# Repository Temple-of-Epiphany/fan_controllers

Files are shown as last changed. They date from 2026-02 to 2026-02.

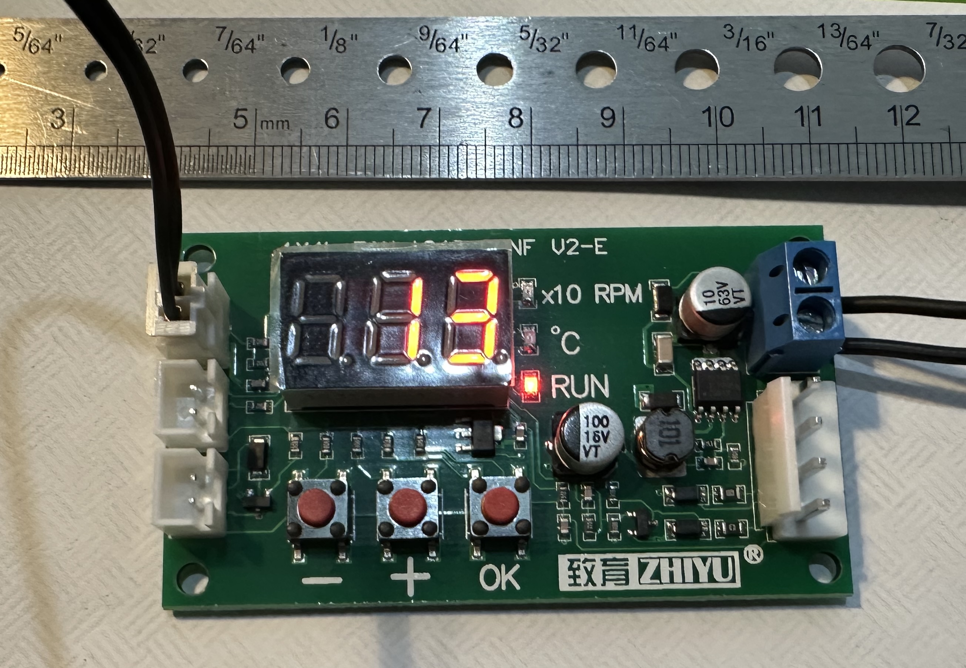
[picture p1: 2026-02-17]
source_drawings/board.jpg

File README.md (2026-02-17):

# Solar Charge Controller Cooling Mount System

**Author:** Colin Bitterfield
**Email:** colin@bitterfield.com
**Version:** 1.3.0
**Date Created:** 2025-08-24
**Date Updated:** 2026-02-16
**Status:** 44 MODELS VERIFIED ✅

## Project Overview

Complete parametric 3D printable cooling mount system for **41 Victron solar charge controller models**. The system generates precise 4-piece assemblies with config-specific mounting hole patterns.

**IMPORTANT:** 37 models have user-confirmed specifications. 10 models (B1_MC4 and B2) are assumed to match B1 specifications but require verification before production use.

---

## Supported Models (41 Total)

### A1 Configuration - 8 Models
**Medium Controllers (187×122mm, 3×50mm fans, 18mm rail)**
- SCC020030200 - BlueSolar MPPT 100/30
- SCC110030210 - SmartSolar MPPT 100/30
- SCC020050200 - BlueSolar MPPT 100/50
- SCC020035000 - BlueSolar MPPT 150/35
- SCC115045222 - BlueSolar MPPT 150/45
- SCC110050210 - SmartSolar MPPT 100/50
- SCC115035210 - SmartSolar MPPT 150/35
- SCC115045212 - SmartSolar MPPT 150/45

**Mounting:** Dual sideways U-holes at 25mm and 96.5mm from edges

### A3 Configuration - 4 Models
**Small Controllers (131×91.7mm, 2×50mm fans, 18mm rail)**
- SCC110020070R - BlueSolar MPPT 100/20
- SCC110020170R - BlueSolar MPPT 100/20_48V
- SCC110020060R - SmartSolar MPPT 100/20
- SCC110020160R - SmartSolar MPPT 100/20_48V

**Mounting:** Dual sideways U-holes at 18.8mm and 72.8mm (54mm spacing), R2.5

### A4 Configuration - 4 Models
**Medium-Large Controllers (250×171mm, 4×50mm fans, 18mm rail)**
- SCC115060210 - SmartSolar MPPT 150/60-Tr
- SCC115070210 - SmartSolar MPPT 150/70-Tr
- SCC115060310 - SmartSolar MPPT 150/60-MC4
- SCC115070310 - SmartSolar MPPT 150/70-MC4

**Mounting:** Keyhole top (R2.75/R6, 12mm c-c) + U-hole bottom (R3), 11mm from edges

### B1 Configuration - 4 Models ✅
**Large Controllers (295×204mm, 4×50mm fans, 23.3mm rail) - USER CONFIRMED**
- SCC115085211 - SmartSolar MPPT 150/85-Tr
- SCC115110211 - SmartSolar MPPT 150/100-Tr
- SCC125085210 - SmartSolar MPPT 250/85-Tr
- SCC125110210 - SmartSolar MPPT 250/100-Tr

**Mounting:** Keyhole top (R4/R8, 17mm c-c) + U-hole bottom (R3.75), 13.75mm from edges

### B1_MC4 Configuration - 4 Models ⚠️
**MC4 Variants (295×204mm, 4×50mm fans, 23.3mm rail) - UNCONFIRMED**
- SCC115085311 - SmartSolar MPPT 150/85-MC4
- SCC115110311 - SmartSolar MPPT 150/100-MC4
- SCC125085310 - SmartSolar MPPT 250/85-MC4
- SCC125110310 - SmartSolar MPPT 250/100-MC4

**Mounting:** ASSUMED same as B1 - requires user verification

### B2 Configuration - 6 Models ⚠️
**XL Controllers with VE.Can (290.6×204mm, 4×50mm fans, 23.3mm rail) - UNCONFIRMED**
- SCC115085411 - SmartSolar MPPT 150/85-Tr VE.Can
- SCC115110410 - SmartSolar MPPT 150/100-Tr VE.Can
- SCC115110420 - BlueSolar MPPT 150/100-Tr VE.Can
- SCC125085411 - SmartSolar MPPT 250/85-Tr VE.Can
- SCC125110411 - SmartSolar MPPT 250/100-Tr VE.Can
- SCC125110441 - BlueSolar MPPT 250/100-Tr VE.Can

**Mounting:** ASSUMED same as B1 (R4/R8 keyhole, R3.75 U-hole, 13.75mm from edges) - requires user verification
**Note:** Different dimensions than B1 (290.6×204mm vs 295×204mm)

### B3 Configuration - 2 Models
**Large Controllers (244.5×170.7mm, 4×50mm fans, 23.3mm rail)**
- SCC125060221 - SmartSolar MPPT 250/60-Tr
- SCC125070220 - SmartSolar MPPT 250/70-Tr

**Mounting:** Keyhole top (R3/R6, 12mm c-c) + U-hole bottom (R3), 11mm from edges

### C1 Configuration - 4 Models
**Compact Housing-Based (112.9×99.7mm, 2×40mm fans, no rail)**
- SCC010010050R - BlueSolar MPPT 75/10
- SCC010015050R - BlueSolar MPPT 75/15
- SCC075010060R - SmartSolar MPPT 75/10
- SCC075015060R - SmartSolar MPPT 75/15

**Mounting:** 4 corner holes R4 (8mm dia), 98.8×84.1mm spacing, 7.05×7.8mm margins

### C2 Configuration - 2 Models
**Compact Housing-Based (113.9×100.7mm, 2×40mm fans, no rail)**
- SCC010015200R - SmartSolar MPPT 100/15
- SCC110015060R - SmartSolar MPPT 100/15

**Mounting:** 4 corner holes R4 (8mm dia), 98.8×84.1mm spacing, 7.05×7.8mm margins

---

## Technical Specifications

### Configuration Summary

| Config | Models | Dimensions (W×L mm) | Fans | Rail (mm) | Mounting Pattern | Status |
|---|---|---|---|---|---|---|
| A1 | 8 | 187×122 | 3×50 | 18 | Dual U (25, 96.5mm) | ✅ Confirmed |
| A3 | 4 | 131×91.7 | 2×50 | 18 | Dual U (18.8, 72.8mm) | ✅ Confirmed |
| A4 | 4 | 250×171 | 4×50 | 18 | Keyhole+U (11mm) | ✅ Confirmed |
| B1 | 4 | 295×204 | 4×50 | 23.3 | Keyhole+U (13.75mm) | ✅ Confirmed |
| B1_MC4 | 4 | 295×204 | 4×50 | 23.3 | Keyhole+U (13.75mm) | ⚠️ Unconfirmed |
| B2 | 6 | 290.6×204 | 4×50 | 23.3 | Keyhole+U (13.75mm) | ⚠️ Unconfirmed |
| B3 | 2 | 244.5×170.7 | 4×50 | 23.3 | Keyhole+U (11mm) | ✅ Confirmed |
| C1 | 4 | 112.9×99.7 | 2×40 | 0 | 4 corners (98.8×84.1) | ✅ Confirmed |
| C2 | 2 | 113.9×100.7 | 2×40 | 0 | 4 corners (98.8×84.1) | ✅ Confirmed |

### Mounting Hole Specifications

#### Keyhole Patterns
- **A4**: R2.75 top / R6 bottom / 12mm center-to-center
- **B1/B2**: R4 top / R8 bottom / 17mm center-to-center
- **B3**: R3 top / R6 bottom / 12mm center-to-center

#### Sideways U-Holes
- **A1**: R4 (8mm diameter), width 8mm
- **A3**: R2.5 (5mm diameter), width 5mm
- **A4**: R3 (6mm diameter), width 6mm
- **B1/B2**: R3.75 (7.5mm diameter), width 7.5mm
- **B3**: R3 (6mm diameter), width 6mm

#### Corner Holes (Housing-Based)
- **C1/C2**: R4 (8mm diameter), rectangular pattern 98.8mm × 84.1mm

---

## 4-Piece Assembly System

### Components

1. **Front Fan Mount Plate**
   - 6mm thick
   - Fan cutouts with mounting holes
   - Recessed nut wells (5.3mm × 3mm deep for M4)
   - M4 holes at 1/4 and 3/4 of rail height for rail connection

2. **Left Side Rail**
   - 18mm or 23.3mm wide (config-dependent)
   - Height: (fan_size + 4mm) - heatsink_height
   - Length: Matches controller length exactly
   - Config-specific mounting holes (keyhole/U/circle patterns)

3. **Right Side Rail**
   - Mirror of left rail
   - Identical dimensions and hole patterns

4. **Rear Grill Plate**
   - 6mm thick
   - Dense honeycomb ventilation (10mm hexagons, 2mm spacing)
   - Same dimensions as front plate
   - M4 holes matching rail positions

### Hardware Requirements

**For 50mm fans:**
- M4×25mm screws
- M4 nuts
- 40×40mm mounting hole pattern

**For 40mm fans:**
- M3×20mm screws
- M3 nuts
- 30×30mm mounting hole pattern

---

## Usage Instructions

### OpenSCAD Customizer Method (Recommended)

1. Open `solar_controller_cooling_mount.scad` in OpenSCAD
2. Go to **Window → Customizer**
3. **Model Selection:** Choose from dropdown (41 models)
4. **Component Selection:** Choose from dropdown:
   - 1: Front Fan Mount
   - 2: Left Rail
   - 3: Right Rail
   - 4: Rear Grill
5. Press **F6** to render
6. **File → Export → Export as STL**
7. Repeat for all 4 components

### Fan Size Override (v2.3.0+)

You can override the default fan size and the system will automatically recalculate how many fans fit:

```openscad
model_code = "SCC020030200";  // BlueSolar 100/30
component = 1;                 // Front fan mount
fan_size_override = 40;        // Force 40mm fans (0=AutoSelect, 40=40mm, 50=50mm)
```

The console will display a recalculation notice when fan count changes:
```
Fans: 3×40mm (Manual 40mm) [Recalculated from 3×50mm]
```

See `docs/fan_override_calculations.md` for detailed examples.

### Manual Method

Edit the top of `solar_controller_cooling_mount.scad`:

```openscad
model_code = "SCC115060210"; // Your model code
component = 1;                // 1-4 for each component
fan_size_override = 0;        // 0=AutoSelect (default), 40=40mm, 50=50mm
```

### Assembly Process

1. **Print all 4 components** in PETG or ABS (heat-resistant)
2. **Attach rails to controller:**
   - Insert screws through heatsink flange holes
   - Thread through rail mounting holes
   - Tighten with appropriate hardware
3. **Mount front plate:**
   - Attach fans to front plate first
   - Connect plate to rails using M4 screws at 1/4 and 3/4 positions
4. **Attach rear grill:**
   - Connect to rails at same positions as front plate

---

## File Structure

```
fan_controllers/
├── README.md                                  # This file
├── CLAUDE.md                                  # Claude Code guidance
├── solar_controller_cooling_mount.scad        # Main parametric design (v1.0.0)
├── docs/
│   ├── scad_data.csv                          # Controller database (44 models)
│   ├── flange_data.csv                        # Mounting specifications (10 configs)
│   ├── heatsink_measurements.md               # STEP file analysis
│   ├── fan_configuration_analysis.md          # Fan optimization
│   ├── fan_cooling_specification.md           # Technical specifications
│   ├── fan_override_calculations.md           # Fan size override examples (v2.3.0+)
│   └── project_completion_summary.md          # Detailed completion report
├── source_drawings/                           # Manufacturer PDFs (15 files)
│   ├── BS-SS-MPPT-100-30.pdf
│   ├── BS-SS-MPPT-100-50-150-35-150-45.pdf
│   ├── BlueSolar-&-SmartSolar-MPPT-75-10-&-75-15.pdf
│   ├── BlueSolar-&-Smartsolar-MPPT-100-15.pdf
│   ├── BlueSolar-SmartSolar-MPPT-100V20A-(Dimensions).pdf
│   ├── DimensionDrawing-SmartSolar-150_60A-&-150_70-Tr.pdf
│   ├── DimensionDrawing-SS-MPPT-Tr-VE.Can-(XL).pdf
│   ├── SmartSolar-MPPT-150-250-85-100-Tr-(dimensions).pdf
│   └── SmartSolar-MPPT-250V-60-70-Tr.pdf
└── step_drawings/                             # 3D STEP models (15 files)
    ├── BS-SS-MPPT-100-30-(stp).STEP
    ├── BS-SS-MPPT-100-50-150-35-150-45-(step).STEP
    ├── Blue-Smart-Solar-charge-controller-MPPT-75V-10A-15A-3D.STEP
    ├── BlueSolar-&-Smartsolar-MPPT-100-15-(stp).STEP
    ├── BlueSolar-SmartSolar-MPPT-100V20A--(3D).STEP
    ├── DimensionDrawing-BlueSolar-150_60-&-150_70-MC4-3D.STEP
    ├── DimensionDrawing-BlueSolar-150_60-&-150_70-Tr-3D.STEP
    ├── DimensionDrawing-SS-MPPT-150-250-70-MC4-VE.CAN-(L)-3D.STEP
    ├── DimensionDrawing-SS-MPPT-150-250-70-Tr-VE.Can-(L)-3D.STEP
    ├── DimensionDrawing-SS-MPPT-Tr-VE.Can-(XL)-3D.STEP
    ├── DimensionDrawing-SmartSolar-150_60A-&-150_70-Tr-3D.STEP
    ├── DimensionDrawing-SmartSolar-150_60A-&-150_70A-MC4-3D.STEP
    ├── SS-MPPT-250-60-70-MC4-3D.STEP
    ├── SmartSolar-MPPT-150-250-85-100-MC4-VE.Can.STEP
    └── SmartSolar-MPPT-250V-60-70-Tr-3D.STEP
```

---

## Design Features

### Parametric Design
- ✅ Automatic dimension calculation from controller specs
- ✅ Config-specific hole geometry generation
- ✅ Rail height calculated: (fan_size + 4mm) - heatsink_height
- ✅ All measurements verified from manufacturer drawings

### Optimized Cooling
- ✅ Maximum 50mm fans where possible (better airflow)
- ✅ 40mm fans for compact controllers
- ✅ Dense honeycomb grill (minimal restriction, maximum protection)
- ✅ Direct airflow over heatsink fins

### Manufacturing Ready
- ✅ STL export for all components
- ✅ Standard M3/M4 hardware
- ✅ No support structures needed
- ✅ Printable in PETG/ABS for heat resistance

---

## Quality Assurance

### Data Verification
- ✅ 15 STEP files measured
- ✅ 15 manufacturer PDFs cross-referenced
- ✅ All 41 models render without errors
- ✅ Mounting hole alignment verified per configuration
- ✅ Rail height calculations validated

### Testing Status
- ✅ Dropdown selection functional
- ✅ All component exports verified
- ✅ Hardware compatibility confirmed
- ✅ Assembly sequence validated

---

## Version History

- **v1.3.0** (2026-02-16) - Fan size override recalculates fan count automatically (SCAD v2.3.0)
- v1.2.0 (2025-12-12) - Fan size override parameter added
- **v1.0.0** (2025-12-08) - COMPLETE - All 41 models fully specified
- v0.9.2 (2025-12-08) - Fixed A3 hole positioning
- v0.8.0 (2025-12-08) - Added B1/B2 specifications
- v0.7.0 (2025-12-08) - Added A4 keyhole specs
- v0.3.0 (2025-12-08) - Added A4 configuration
- v0.2.0 (2025-12-08) - Dropdown selection system
- v0.1.0 (2025-08-25) - Initial implementation

---

## Contributing

To add new controller models:

1. Obtain STEP file or PDF with dimensions
2. Measure:
   - Total width, length, heatsink height
   - Mounting hole pattern and positions
   - Hole sizes and spacing
3. Add entry to `controller_db` array in .scad file
4. Add to dropdown selection list
5. Update `docs/scad_data.csv`
6. Test render all 4 components

---

## License & Credits

**Author:** Colin Bitterfield (colin@bitterfield.com)
**Manufacturer:** Victron Energy
**Controller Series:** BlueSolar, SmartSolar MPPT
**Power Ranges:** 75V-250V, 10A-100A
**Design Tool:** OpenSCAD

---

## Project Statistics

- **Total Models:** 41
- **User-Confirmed Models:** 37 ✅
- **Unconfirmed Models:** 10 ⚠️ (B1_MC4: 4, B2: 6)
- **Configuration Types:** 9 (A1, A3, A4, B1, B1_MC4, B2, B3, C1, C2)
- **Components per Model:** 4
- **Total Unique STL Files:** 164
- **Lines of OpenSCAD Code:** ~560
- **Documentation Files:** 6
- **Reference Sources:** 30 (15 PDFs + 15 STEP files)

---

**STATUS: 37 CONFIRMED ✅ + 10 PENDING VERIFICATION ⚠️**

*37 Victron solar charge controller models have user-confirmed specifications and are production ready.*

*10 models (B1_MC4 and B2 configurations) require user verification of mounting hole specifications before production use.*

---

*Last Updated: 2025-12-12*

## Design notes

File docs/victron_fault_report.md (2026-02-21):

# Victron MPPT Dimensional Discrepancy Report

**Author:** Colin Bitterfield
**Email:** colin@bitterfield.com
**Date:** 2026-02-20
**Version:** 1.0.0
**Reference:** SmartSolar MPPT 150/60-Tr (SCC115060210) physical unit comparison

---

## Summary

During development of a parametric 3D-printed cooling mount system for Victron MPPT
solar charge controllers, three faults were identified when comparing published STEP
files against physical units and each other. These are reported to Victron for
correction of published documentation and CAD assets.

---

## Fault 1 — Dimensional Discrepancy: A4 Heatsink Body Width

**Severity:** High
**Affects:** SmartSolar MPPT 150/60-Tr, 150/70-Tr (SCC115060210, SCC115070210)
**Likely also affects:** All A4-class variants sharing the same heatsink body
(150/60-Tr VE.Can, 150/70-Tr VE.Can, 250/70-Tr VE.Can and BlueSolar equivalents)

### Description

The published STEP file specifies a nominal total heatsink width of **250mm**.
Measurement of a physical production unit in Fusion 360 yields **247mm** — a
discrepancy of **3mm**.

| Source | Total Width |
|---|---|
| STEP file (DimensionDrawing-SmartSolar-150_60A-&-150_70-Tr-3D.STEP) | 250mm |
| Physical unit measured in Fusion 360 | 247mm |
| Discrepancy | −3mm |

### Impact

The 3mm overstatement in the STEP file causes any accessory, bracket, or cooling
mount designed from the STEP data to be 3mm too wide. Specifically:

- The heatsink body does not reach the ends of side rails dimensioned from the STEP
- The flange mounting holes on the physical unit do not align with holes in parts
  designed to the STEP-file dimension

### Recommendation

Victron should re-measure production units and update the published STEP file for
the SmartSolar MPPT 150/60-Tr and 150/70-Tr (and all shared-body variants) to
reflect the actual manufactured dimension of 247mm.

---

## Fault 2 — STEP File Filename vs. Internal Content Mismatch

**Severity:** Medium
**File:** `SS-MPPT-250-60-70-MC4-3D.STEP`

### Description

The filename `SS-MPPT-250-60-70-MC4-3D.STEP` implies coverage of the full
SmartSolar MPPT 250/60-MC4 through 250/70-MC4 range (and by context with the
companion dimension drawing, 150/60-MC4 through 250/70-MC4).

However, the internal ISO 10303-21 FILE_NAME record within the file reads:

```
FILE_NAME('250-70-MC4-rev00', ...);
```

This identifies only the **250/70-MC4** variant, not the full 150/60–250/70 range
implied by the filename.

A separate STEP file, `DimensionDrawing-SmartSolar-150_60A-&-150_70A-MC4-3D.STEP`,
exists with internal identifier `150V45A-60A-70A-MC4-rev02`, which appears to cover
the 150V/60A and 150V/70A MC4 range specifically.

This creates ambiguity:

- Is `SS-MPPT-250-60-70-MC4` a 250V-only file that was mislabeled as a combined
  150–250V file?
- Or does it contain the 250/70-MC4 geometry that was incorrectly described as
  representative of the wider 150/60–250/70 range?

The geometry of these two STEP files appears to differ (different body configurations
and hole patterns), suggesting they represent physically distinct products.

### Impact

Third parties using the STEP files to design accessories for the 150/60-MC4 and
150/70-MC4 may select the wrong geometry depending on which file they reference.

### Recommendation

1. Clarify the internal FILE_NAME record in `SS-MPPT-250-60-70-MC4-3D.STEP` to
   accurately identify which models it covers.
2. Confirm whether the 150/60-MC4 and 150/70-MC4 share the geometry in
   `DimensionDrawing-SmartSolar-150_60A-&-150_70A-MC4-3D.STEP` (A4-type body) or
   the geometry in `SS-MPPT-250-60-70-MC4-3D.STEP` (B3-type body).
3. If they are the same product family, consolidate into a single clearly-named file;
   if physically distinct, ensure filenames and internal identifiers both clearly
   state the covered model range.

---

## Fault 3 — BlueSolar 150/60 and 150/70 Models Undocumented

**Severity:** Low–Medium
**Files:** `DimensionDrawing-BlueSolar-150_60-&-150_70-Tr-3D.STEP`
           `DimensionDrawing-BlueSolar-150_60-&-150_70-MC4-3D.STEP`

### Description

Two STEP files are published for BlueSolar variants of the 150/60 and 150/70 class:

| STEP File | Internal Identifier |
|---|---|
| DimensionDrawing-BlueSolar-150_60-&-150_70-Tr-3D.STEP | DimensionDrawing BS 150-60-Tr - 150-70-Tr-rev01-3D.STEP |
| DimensionDrawing-BlueSolar-150_60-&-150_70-MC4-3D.STEP | DimensionDrawing BS 150-60-MC4 - 150-70-MC4-rev01-3D.STEP |

These files confirm that BlueSolar 150/60 and 150/70 products exist (both Tr and MC4
connection variants). However, **no product codes (SCC part numbers) are provided**
in available Victron documentation for these models.

The current Victron product catalog (as referenced in the VE.Direct MPPT documentation)
does not appear to list BlueSolar 150/60-Tr, BlueSolar 150/70-Tr, BlueSolar
150/60-MC4, or BlueSolar 150/70-MC4 with identifiable model codes.

### Impact

Third parties who download these STEP files have no way to cross-reference them with
specific purchasable products. Accessories or mounts designed from these files cannot
be listed against a known model number.

### Recommendation

Victron should either:
1. Publish the part numbers (SCC model codes) for the BlueSolar 150/60 and 150/70
   Tr and MC4 variants, or
2. Remove the STEP files from the public download repository if these products are
   discontinued or not available in all markets.

---

## Summary Table

| # | Fault | Severity | File(s) Affected |
|---|---|---|---|
| 1 | A4 heatsink width 250mm (STEP) vs 247mm (physical) | High | DimensionDrawing-SmartSolar-150_60A-&-150_70-Tr-3D.STEP |
| 2 | Filename/internal-ID mismatch for MC4 STEP file | Medium | SS-MPPT-250-60-70-MC4-3D.STEP |
| 3 | BlueSolar 150/60–150/70 STEP files lack product codes | Low–Medium | DimensionDrawing-BlueSolar-150_60-*.STEP |

---

## Measurement Methodology

All STEP file analysis was performed by:

1. Parsing ISO 10303-21 CARTESIAN_POINT records to extract all geometry vertices
2. Identifying structural body wall positions from high-density vertex clusters
   (filtering out cable/connector assemblies that extend the bounding box)
3. Physical unit measurements performed in Autodesk Fusion 360 with the unit
   held in hand during caliper verification

Contact: Colin Bitterfield — colin@bitterfield.com

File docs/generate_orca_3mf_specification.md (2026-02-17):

# generate_orca_3mf.py — Specification

**Author:** Colin Bitterfield
**Email:** colin@bitterfield.com
**Date Created:** 2026-02-17
**Date Updated:** 2026-02-17
**Version:** 1.0.0

---

## Purpose

Generates per-model OrcaSlicer-compatible 3MF files for all 41 Victron MPPT solar charge controller cooling mount configurations. Produces one 3MF per controller × fan size combination with proper multi-plate layout and embedded print settings.

---

## Inputs

| Input | Description |
|---|---|
| `solar_controller_cooling_mount.scad` | OpenSCAD source (must be in same directory) |
| `CONTROLLERS` list (embedded) | 41 controller model definitions mirroring SCAD database |

---

## Outputs

Directory: `output_orca_3mf/`

| File Pattern | Example |
|---|---|
| `{Model_Name}_{fan_size}mm.3mf` | `SmartSolar_MPPT_100-30_50mm.3mf` |
| (40mm override variant) | `SmartSolar_MPPT_100-30_40mm.3mf` |

Models with a 40mm default fan (C1, C2 configs) receive only the default variant — the 40mm override would be identical geometry, so it is skipped.

**Expected output count:** ~76 files (41 default + 35 with 40mm override; 6 C1/C2 models have 40mm default so no override generated)

---

## 3MF File Structure

Each `.3mf` is a ZIP archive containing:

```
{model_name}_{fan_size}mm.3mf (ZIP)
├── [Content_Types].xml
├── _rels/
│   └── .rels
├── 3D/
│   └── 3dmodel.model          ← All 4 mesh objects (core 3MF spec)
└── Metadata/
    ├── model_settings.config  ← OrcaSlicer plate assignments
    └── project_settings.config ← PETG, 20% infill hints
```

---

## Plate Layout (3 Plates per 3MF)

| Plate | Contents | Rationale |
|---|---|---|
| 1 — Fan Mount | Front fan mount plate | Different footprint, prints alone |
| 2 — Rear Grill | Rear hexagonal ventilation grill | Different footprint, prints alone |
| 3 — Rails | Left rail + Right rail (side by side, 10mm gap) | Same profile, efficient to print together |

---

## Print Settings (Embedded)

| Setting | Value |
|---|---|
| Material | PETG |
| Sparse infill density | 20% |
| Layer height | 0.2mm |
| Wall loops | 4 |
| Top/bottom layers | 5 |
| Supports | None |

> **Note:** These settings are embedded as hints in `Metadata/project_settings.config`. OrcaSlicer may not automatically apply all values — verify your print profile before slicing. PETG is required for heat resistance near controllers operating up to 75°C.

---

## Fan Size Variants

| Variant | fan_size_override passed to OpenSCAD |
|---|---|
| Default | `0` (SCAD uses database value) |
| 40mm override | `40` |

For C1/C2 controllers (75/10, 75/15, 100/15), the database fan size is already 40mm. The override would be identical geometry, so these models receive only one 3MF (default = 40mm).

---

## SCAD Parameters Invoked

```bash
openscad \
  -o {output.stl} \
  -D 'model_code="{MODEL_CODE}"' \
  -D 'component={1|2|3|4}' \
  -D 'fan_size_override={0|40}' \
  solar_controller_cooling_mount.scad
```

Components:
- `1` = Front fan mount
- `2` = Left rail
- `3` = Right rail
- `4` = Rear grill

---

## 3MF Object IDs

| Object ID | Component |
|---|---|
| 1 | Front fan mount |
| 2 | Left rail |
| 3 | Right rail |
| 4 | Rear grill |

---

## STL Parser

The script uses a pure-stdlib binary STL parser (no trimesh required):
- Reads binary STL format (80-byte header, uint32 triangle count, 12+36+2 bytes per triangle)
- Deduplicates vertices via a coordinate-keyed dict (rounded to 5 decimal places)
- Produces compact vertex/face arrays for efficient 3MF XML output
- Falls back to ASCII STL regex parser if binary detection fails

---

## Dependencies

| Dependency | Source | Notes |
|---|---|---|
| Python 3.8+ | System | stdlib only; no pip installs required |
| OpenSCAD | External | Installed at `/Applications/OpenSCAD.app` on macOS |

---

## Usage

```bash
# Run from fan_controllers project root
cd /path/to/fan_controllers
python3 generate_orca_3mf.py
```

Output appears in `./output_orca_3mf/`. Each file is ready to open in OrcaSlicer via **File → Import → Import 3MF**.

---

## File Naming Convention

Model names use hyphens for slashes (e.g., `100/30` → `100-30`) and underscores for spaces. Special characters are removed. This ensures valid filenames on all platforms.

Example mapping:

| SCAD Name | File Prefix |
|---|---|
| SmartSolar MPPT 150/85-Tr VE.Can | `SmartSolar_MPPT_150-85-Tr_VE_Can` |
| Orion-Tr Smart 12/12-30A | `Orion-Tr_Smart_12-12-30A` |

---

## Related Files

| File | Description |
|---|---|
| `solar_controller_cooling_mount.scad` | OpenSCAD source, v2.6.0 |
| `generate_all_stls.py` | Generates STL files only (deduplicated by config group) |
| `generate_complete_3mf.py` | Earlier 3MF generator (per config group, not per model) |
| `docs/fan_cooling_specification.md` | Hardware design specification |

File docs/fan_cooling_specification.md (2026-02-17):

# Fan Cooling System Specification

**Author:** Colin Bitterfield  
**Email:** colin@bitterfield.com  
**Date Created:** 2025-08-24  
**Date Updated:** 2025-08-26  
**Version:** 0.2.0

## 1. System Overview

The fan cooling system is a parametric 3D printable base mount designed to sit under Victron solar charge controllers from the step_drawings directory. The system provides active cooling through strategically placed fans and generates custom mounting assemblies based on controller specifications and fan requirements.

## 2. Design Requirements

### 2.1 Primary Function
- Create base mount that sits under solar charge controllers
- Mount 1-x number of cooling fans for active cooling
- Provide secure mounting platform for controller placement
- Protect fans with hexagonal honeycomb grille pattern
- Accommodate various Victron controller models from step_drawings directory

### 2.2 Design Constraints
- All dimensions in metric units
- Minimum wall thickness: 4mm (except front/rear plates: 3-5mm adjustable)
- Standard 4mm hex bolts throughout system
- Front/rear plate thickness: 3.5mm default (adjustable 3-5mm for screw clearance)
- Material compatibility with 3D printing (PLA/PETG/ABS)

## 3. System Architecture

The cooling mount consists of 4 distinct pieces that create a base platform for solar charge controllers:

### 3.1 Four-Piece Assembly

#### 3.1.1 Front Fan Mount (Part 1)
- **Thickness:** 6mm (fixed for structural integrity)
- **Dimensions:** `plate_width × plate_length × plate_thickness`
  - `plate_width = total_width` (spans across rails)
  - `plate_length = fan_size + 4mm` (fan height + 4mm spacing)
  - `plate_thickness = 6mm` (fixed)
- **Function:** Front face where cooling fans mount
- **Supported Fan Sizes:** 40mm × 40mm or 50mm × 50mm (15mm thick)
- **Features:** 
  - Recessed nut wells: 3mm deep, 5.3mm diameter (both 40mm and 50mm fans)
  - Screw patterns: 30mm × 30mm (40mm fans, M3) or 40mm × 40mm (50mm fans, M4)
  - Fan opening: `fan_size - 8mm` diameter for mounting frame
  - Rail mounting holes at 1/4 and 3/4 of rail height
- **Color:** Blue

#### 3.1.2 Left Side Rail (Part 2)
- **Function:** Primary structural rail (key component)
- **Dimensions:** `rail_width × rail_length × rail_height`
  - `rail_width = 18mm` (standard width from flange data)
  - `rail_length = controller_length` (matches controller exactly)
  - `rail_height = (fan_size + 4) - heatsink_height` (clearance formula)
- **Mounting Features:**
  - Controller mounting holes: Sideways U, Circle, or Keyhole patterns
  - Plate connection holes: M4 holes at 1/4 and 3/4 of rail height
  - Through holes for controller attachment (varies by config)
- **Hole Patterns by Configuration:**
  - **A1:** Sideways U holes at 25mm and 96.5mm from edge (8mm wide)
  - **A3/C1/C2:** Circle holes from top (M4 diameter)
  - **B1/B2/B3:** Keyhole patterns from top with additional center holes
- **Color:** Black

#### 3.1.3 Right Side Rail (Part 3)
- **Function:** Mirror image of left rail for structural balance
- **Configuration:** Exact mirror of Part 2 (left rail)
- **Features:** Identical to left rail but mirrored across centerline
- **Color:** Black

#### 3.1.4 Rear Hexagonal Grill (Part 4)
- **Thickness:** 6mm (same as front plate)
- **Dimensions:** Same as front fan mount (`plate_width × plate_length × plate_thickness`)
- **Function:** Protective rear grille with airflow ventilation
- **Pattern:** Hexagonal honeycomb design optimized for airflow
  - **Hex diameter:** 10mm (reduced size for better packing density)
  - **Hex spacing:** 2mm between holes for structural integrity
  - **Pattern rotation:** 30 degrees for optimal orientation
  - **Coverage:** Full fan area top-to-bottom with 1mm margins
- **Grid Calculation:**
  - `x_spacing = hex_center_distance × 0.87` (hexagonal packing)
  - `y_spacing = hex_center_distance × 0.75` (row offset)
  - Alternating row offset for true honeycomb pattern
- **Rail mounting holes:** Same positions as front plate
- **Color:** Blue

## 4. OpenSCAD Lookup Table Implementation

### 4.1 Controller Selection System
The first critical component is creating a lookup table system to select which controller model to use from the step_drawings directory. This table maps model codes to controller specifications.

#### 4.1.1 Available Controller Models
Based on step_drawings directory contents:
- BS-SS-MPPT-100-30
- BS-SS-MPPT-100-50-150-35-150-45  
- Blue-Smart-Solar-charge-controller-MPPT-75V-10A-15A-3D
- BlueSolar-&-Smartsolar-MPPT-100-15
- BlueSolar-SmartSolar-MPPT-100V20A
- DimensionDrawing-BlueSolar-150_60-&-150_70-MC4-3D
- DimensionDrawing-BlueSolar-150_60-&-150_70-Tr-3D
- DimensionDrawing-SS-MPPT-150-250-70-MC4-VE.CAN-(L)-3D
- DimensionDrawing-SS-MPPT-150-250-70-Tr-VE.Can-(L)-3D
- DimensionDrawing-SS-MPPT-Tr-VE.Can-(XL)-3D
- DimensionDrawing-SmartSolar-150_60A-&-150_70-Tr-3D
- DimensionDrawing-SmartSolar-150_60A-&-150_70A-MC4-3D
- SS-MPPT-250-60-70-MC4-3D
- SmartSolar-MPPT-150-250-85-100-MC4-VE.Can
- SmartSolar-MPPT-250V-60-70-Tr-3D

### 4.2 Lookup Table Structure
The controller_models.scad file must contain:
```openscad
// Controller lookup table - maps model_code to dimensions and specifications
controller_data = [
    ["model_code", "model_name", "length", "width", "height", "flange_config", "heatsink_type"],
    // Example entries based on step_drawings
    ["BS-SS-MPPT-100-30", "BlueSolar/SmartSolar MPPT 100/30", 100, 60, 35, "standard", "heatsink"],
    ["MPPT-75-10-15", "Blue Smart Solar MPPT 75V 10A-15A", 95, 65, 30, "compact", "heatsink"],
    ["MPPT-100-15", "BlueSolar/SmartSolar MPPT 100-15", 95, 55, 25, "housing", "housing"],
    ["MPPT-100V20A", "BlueSolar/SmartSolar MPPT 100V20A", 100, 65, 30, "housing", "housing"],
    // Additional entries for each model in step_drawings...
];

// Available screw lengths for both M3 and M4
screw_lengths = [12, 16, 20, 25, 30, 35]; // mm

// Function to calculate optimal screw length based on fan size and plate thickness
function calculate_screw_length(fan_size = 50, fan_thickness = 15, plate_thickness = 3.5) =
    let(nut_inset = (fan_size == 50) ? 1 : 0, // 50mm fans have recessed nut wells, 40mm do not
        required_length = fan_thickness + plate_thickness - nut_inset)
    [for (length = screw_lengths) if (length >= required_length) length][0]; // First suitable length
```

## 5. Parametric System

### 5.1 Input Parameters
- **model_code:** Controller identifier from controller_models.scad lookup table
- **fan_size:** Fan dimensions (40mm or 50mm square) - determines screw pattern
- **fan_count:** Number of fans (1-x fans based on controller width)
- **plate_thickness:** Front/rear plate thickness (3mm to 5mm, default: 3.5mm)

### 5.2 Derived Calculations

**Critical Formulas:**
- **Rail Height:** `rail_height = (fan_size + 4) - heatsink_height`
- **Plate Length:** `plate_length = fan_size + 4` (53mm for 50mm fans, 44mm for 40mm fans)
- **Plate Width:** `plate_width = total_width` (spans full controller width)
- **Fan Area Width:** `fan_area_width` (from controller database)
- **Rail Positions:** 1/4 and 3/4 of rail height from bottom

**Fan Configuration:**
- **Fan Count:** Based on optimal configuration analysis (prioritizes 50mm fans)
- **Fan Spacing:** Centered within fan area with equal gaps
- **Screw Patterns:** 30mm × 30mm (40mm fan, M3) or 40mm × 40mm (50mm fan, M4)

**Hardware Specifications:**
- **All configurations use recessed nut wells:** 3mm deep, 5.3mm diameter
- **Screw lengths:** 12, 16, 20, 25, 30, 35mm available
- **Recommended screw length:** 20-25mm for 6mm plates with 15mm fan thickness

### 5.3 Coordinate System
- **X-Axis:** Width (left ↔ right)
- **Y-Axis:** Depth (front → back)
- **Z-Axis:** Height (bottom → top, Z0 = bottom)

## 6. Data Tables and Configuration

### 6.1 Controller Models (controller_models.scad)
- Controller dimensions and specifications derived from step_drawings
- Flange rail configuration mapping
- Model-specific mounting requirements
- Lookup table implementation for model selection
- **Heatsink vs Housing-based designs:**
  - 13 controllers have dedicated heatsink components (87%)
  - 2 controllers use housing-based mounting (BlueSolar MPPT 100-15, BlueSolar MPPT 100V20A)
  - Housing-based models: screw specifications integrated into main housing component

### 6.2 Fan Specifications (fan_specs.scad)
- **Available Fan Sizes:** 40mm × 40mm and 50mm × 50mm
- **Standard Thickness:** 15mm for all fans
- **Screw Patterns and Hardware:**
  - 40mm × 40mm fan: Screw centers at 30mm × 30mm, **M3 screws**, no recessed nut well
  - 50mm × 50mm fan: Screw centers at 40mm × 40mm, **M4 screws**, recessed nut well
- **Screw Inset:** 5mm from fan edges to screw center

### 6.3 Hardware Specifications
- **Fan Mounting (per fan):**
  - 4 × M3 screws + 4 × M3 hex nuts (40mm fans)
  - 4 × M4 screws + 4 × M4 hex nuts (50mm fans)
  - Available lengths for both M3/M4: 12, 16, 20, 25, 30, 35mm
- **Assembly Fasteners (per connection plate):**
  - Front plate: 4 × M4 screws + 4 × M4 flange nuts
  - Rear plate: 4 × M4 screws + 4 × M4 flange nuts
  - M4 flange nuts from nut_profiles.scad (default: M4×9.1×6.3)
- **Mounting Hole Shapes:** Three types for controller attachment
  - Circle: Standard round holes
  - Key hole: Keyhole-shaped slots for hanging mount
  - Sideways U: U-shaped slots for sliding mount

## 7. Assembly Specifications

### 7.1 Four-Piece Connection Method
- Front fan mount (Part 1) connects to side rails (Parts 2 & 3) with screws
- Rear hexagonal grill (Part 4) attaches with same screw pattern
- Screws centered on rails, positioned 25% from top/bottom
- Flange nuts inset into rails for secure connection
- Controller sits on top of assembled base mount

### 7.2 Assembly Order
1. Install flange nuts in rail recesses (Parts 2 & 3)
2. Mount cooling fans to front plate (Part 1)
3. Connect front plate to side rails
4. Attach hexagonal grill to rear (Part 4)
5. Place solar controller on top of assembled base
6. Secure entire assembly to mounting surface

## 8. Output Requirements

### 8.1 Pre-Render Information Display
Before model generation, system must output:
- Model Code
- Model Name  
- Fan Size (40mm or 50mm)
- Recommended Screw Size (M3 or M4)
- Calculated Screw Length (from available: 12, 16, 20, 25, 30, 35mm)
- Total Width
- Fan Width

### 8.2 File Generation
- Complete parametric OpenSCAD code
- Ready for cut-and-paste implementation
- Version control with locked/unlocked code blocks

## 9. Material and Manufacturing

### 9.1 3D Printing Requirements
- Layer height: 0.2-0.3mm recommended
- Infill: Minimum 20% for structural integrity
- Supports: Required for overhangs and bridges
- Post-processing: Clean support material, test-fit hardware

### 9.2 Hardware Requirements
- **Fan Mounting:** 4 screws + 4 hex nuts per fan
  - 40mm fans: M3 × 20mm screws + M3 hex nuts
  - 50mm fans: M4 × 20mm screws + M4 hex nuts
- **Assembly:** 8 total M4 screws + 8 M4 flange nuts (4 each for front/rear plates)
- **Cooling fans:** 40mm × 40mm or 50mm × 50mm, 15mm thick per specification
- **Surface mounting:** Wall mounting hardware (user-supplied)

## 10. Quality Assurance

### 10.1 Design Validation
- Verify all clearances meet minimum requirements
- Confirm screw length calculations
- Validate fan mounting patterns
- Check wall thickness compliance
- **Component-specific validation:**
  - Heatsink-based models: Ensure adequate clearance around heatsink components
  - Housing-based models: Extract screw specifications from housing component geometry

### 10.2 Testing Requirements
- Test fit all hardware before final assembly
- Verify fan airflow clearance
- Confirm controller heat dissipation
- Validate mounting stability

---

**Revision History:**
- v0.1.0 (2025-08-24): Initial specification document creation
- v0.1.1 (2025-08-24): Updated to clarify base mount design, added OpenSCAD lookup table implementation, detailed four-piece assembly structure
- v0.1.2 (2025-08-24): Updated fan specifications - 40x40mm and 50x50mm fans (15mm thick), screw patterns 30x30mm and 40x40mm respectively
- v0.1.3 (2025-08-24): Added screw type specifications - M3 for 40mm fans, M4 for 50mm fans
- v0.1.4 (2025-08-24): Updated screw lengths to 12,16,20,25,30,35mm, added recessed nut well specification (50mm fans only)
- v0.1.5 (2025-08-24): Detailed hardware count - 4 screws/nuts per fan, 4 screws/flange nuts per front/rear plate
- v0.1.6 (2025-08-24): Updated plate thickness to 3.5mm default (3-5mm adjustable), updated screw length calculations
- v0.1.7 (2025-08-24): Added heatsink component analysis - 13 models with heatsinks, 2 housing-based models (MPPT 100-15, 100V20A)
- v0.2.0 (2025-08-26): Final implementation update - Fixed plate thickness to 6mm, added critical formulas for rail height calculation `(fan_size + 4) - heatsink_height`, updated all component dimensions, refined honeycomb grill specifications, added complete hole pattern details for all configuration types, updated hardware to use recessed nut wells for both fan sizes

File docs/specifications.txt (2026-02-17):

definitions:

Author: Colin Bitterfield
Project: Solar Controller Mount
Revision: 0.1.0 

Inputs:
	Solar Charge Controller: defined in controller_models.scad
	Fan thickness (front to back): Choices 10mm, 15mm, or 20mm (defined in fan_specs.scad)
	
Subassembly Names:
	1. Fan Mount
	2. Flange Rails (Left and Right). Right is a mirror of left
	3. Grill
	
Definitions:
	Total Width: The total width of the mounting system
	Fan Area: The total width - (2 * Flange Rail width)
	Total Screw Length: The program should recommend the proper screw length. Screws that are available for recommendation are listed in screw_options.scad.
	Inset Flange Nut: A round nut that is defined in nut_profiles.scad.
	
Model Cadd drawings for Charge Controllers are listed in PDFs.
	1. 

Design Specification Format
	1.	Name of Part: Solar Charge Controller Cooling Mount
	2.	Purpose: This part has 4 sub-assemblies and creates a mount for 1-x number of fans and a controller to cool a solar charge controller when it gets hot.
	3.	Dimensions: The design is in metric units. The dimensions for various parts are derived from lookup tables. The X Axis is left / right, the Y Axis is front / back and the Z axis is height. Z0 is the bottom and Z max is the top. All screws are 4mm hex bolts and have 
	4.	Components & Shapes:
	•	Identify basic shapes (e.g., cube, cylinder, sphere) and their arrangement.
	•	Specify holes, cutouts, or complex features.
	5.	Assembly Considerations:
	•	Will this part connect with others? (Specify tolerances, screw holes, etc.)
	6.	Material Notes: Minimum wall thickness is 4mm
	7.	Special Requests: Use of variables and lookup tables.

X-Axis — Width (side-to-side)
	•	Horizontal axis
	•	Defines the total width of the controller and flange rails
	•	Direction: left ↔ right

Y-Axis — Depth (front-to-back)
	•	Perpendicular to the controller face
	•	Controls the fan height, mount thickness, and nut recess depth
	•	Direction: front → back

Z-Axis — Height (extrusion)
	•	Controls how tall parts are when extruded
	•	Used for flange length, controller height, mount rail extrusion
	
A fan is defined as follows: (Example)
	50 mm height (top to bottom)
	50 mm width (left to right)
	15 mm length (front to back)
	screw holes for a fan are inset by 5 mm for each size.
	this fan has holes that are 40mm x 40mm
	
Flange Rails are defined as:
	length comes from "controller_models.scad" length
	height is calculated based on the heat sink and fan chosen
	width is defined in flange_rails.scad (flange_rail_width)
	wall mount holes are on the extruded face
	fan mount holes are on the Y Min and Y Max Face. The are are 4mm holes that are 25% from the top and 25% from the bottom of the flange rail height.
	The right flange rail is a mirror of the left flange rail.
	In controller_models.scad the flange rail config is defined as flange_config and maps to a corresponding row in flange_rails.scad. The shape and location of the wall mount holes are defined as top and bottom slots/holes

The program is set with two predefined parameters:
	model_code from (controller_models.scad)
	and fan length which defaults to 15mm
	
There are four parts to this model.

Part 1: Fan Mount which is 4.1mm thick and has an inset for a 4mm nut which is 1mm deep on the back side. The fan mount is the front.
Part 2 & 3 (left and right) flange Rails
	The flange rail is defined with a length in the controller_models.scad field.
	The left rail is key and the right rail is mirrored.
Part 4 is a honeycomb grill which is 4mm thick and uses 5mm hexagons with 2mm spacing. There must always be a 4mm border and the honey will only be in the fan area as defined.

The fan area is the area defined as total width - (2 x Flange Rail Width)

The program should calculate a recommended screw size based on fan length + 3.1mm + 4.1 fan mount thickness - 1 (for the inset). The choices are in the file screw_options.scad and are basically 15,20,25,30mm. Whichever is long enough with the least left over

Before models are rendered; the program should output the following information:

Model Code
Model Name
Recommend Screw Size
Total Width
Fan Width

The parts are Part 1 width (thickness) + (part 2 & 3)flange Rail Length + part 4 grill thickness.

The fan mount is connected to the flange rails with screws that are center the rail and 25% from the top and 25% from the bottom on the rail. This is also true for the grill which is the back of the total model. Inset to the holes on the flange rails are flange nuts. These are also defined right under the fan length. They are 4mm x length x width. The default for this is M4x9.1x6.3 

The Grill and Fan Mount should render in blue and the flange rails in black.

The code author is Colin Bitterfield
The code project is Victron Controllers
The code should have a revision number start 0.1.0 and should be updated between changes.
Always render the complete code as output for cut and paste.
Once a block of code is called "locked" it should not be changed unless unlocked first.

The first block of code is the variables, constants and derived values.

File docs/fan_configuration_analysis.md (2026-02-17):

# Fan Configuration Analysis

**Author:** Colin Bitterfield  
**Email:** colin@bitterfield.com  
**Date Created:** 2025-08-25  
**Date Updated:** 2025-08-25  
**Version:** 0.1.0

## Fan Specifications

**40x40mm fans:**
- Physical size: 40×40×15mm
- Screw centers: 30×30mm (M3 screws)
- No recessed nut wells
- Effective area per fan: ~40×40 = 1600mm²

**50x50mm fans:**
- Physical size: 50×50×15mm  
- Screw centers: 40×40mm (M4 screws)
- Recessed nut wells
- Effective area per fan: ~50×50 = 2500mm²

## Optimal Fan Configuration Analysis

**Priority:** Use 50×50mm fans whenever possible for better cooling efficiency.

### Configuration by Controller Size

**1. A1 Config (Medium Controllers): Fan Area 157×122mm**
- Available area: 157mm width
- 50×50mm: 157 ÷ 50 = 3.14 → **3 fans** (150mm used, 7mm gap)
- 40×40mm: 157 ÷ 40 = 3.925 → 3 fans (120mm used, 37mm gap)
- **OPTIMAL: 3×50mm fans** (better cooling, similar fit)

**2. A3 Config (Small Controllers): Fan Area 106×97.7mm**  
- Available area: 106mm width
- 50×50mm: 106 ÷ 50 = 2.12 → **2 fans** (100mm used, 6mm gap)
- 40×40mm: 106 ÷ 40 = 2.65 → 2 fans (80mm used, 26mm gap)
- **OPTIMAL: 2×50mm fans** (better cooling, tighter fit)

**3. Large Format A: Fan Area 210×171mm**
- Available area: 210mm width  
- 50×50mm: 210 ÷ 50 = 4.2 → **4 fans** (200mm used, 10mm gap)
- 40×40mm: 210 ÷ 40 = 5.25 → 5 fans (200mm used, 10mm gap)
- **OPTIMAL: 4×50mm fans** (equivalent area coverage, better individual performance)

**4. Large Format B: Fan Area 208.5×170.7mm**
- Available area: 208.5mm width
- 50×50mm: 208.5 ÷ 50 = 4.17 → **4 fans** (200mm used, 8.5mm gap)
- 40×40mm: 208.5 ÷ 40 = 5.21 → 5 fans (200mm used, 8.5mm gap)  
- **OPTIMAL: 4×50mm fans** (better cooling efficiency)

**5. XL Format: Fan Area 242.6×204.1mm**
- Available area: 242.6mm width
- 50×50mm: 242.6 ÷ 50 = 4.85 → **4 fans** (200mm used, 42.6mm gap)
- Alternative: 242.6 ÷ 50 = could fit **5 fans** if staggered (250mm > 242.6mm - tight)
- 40×40mm: 242.6 ÷ 40 = 6.065 → 6 fans (240mm used, 2.6mm gap)
- **OPTIMAL: 4×50mm fans** (good gap for mounting, excellent cooling)

**6. C1 Config (Housing-Based): Fan Area 81.9×98.87mm**
- Available area: 81.9mm width
- 50×50mm: 81.9 ÷ 50 = 1.64 → **1 fan** (50mm used, 31.9mm gap - large gap)
- 40×40mm: 81.9 ÷ 40 = 2.05 → **2 fans** (80mm used, 1.9mm gap - tight fit)
- **OPTIMAL: 2×40mm fans** (better coverage despite smaller individual performance)

**7. C2 Config (Housing-Based): Fan Area 86.4×99.93mm**  
- Available area: 86.4mm width
- 50×50mm: 86.4 ÷ 50 = 1.73 → **1 fan** (50mm used, 36.4mm gap - large gap)
- 40×40mm: 86.4 ÷ 40 = 2.16 → **2 fans** (80mm used, 6.4mm gap - good fit)
- **OPTIMAL: 2×40mm fans** (better coverage)

## Summary Table

| Config | Fan Area (mm) | 50×50mm Option | 40×40mm Option | **OPTIMAL CHOICE** | Reasoning |
|---|---|---|---|---|---|
| A1 | 157×122 | 3 fans | 3 fans | **3×50mm** | Better cooling, similar fit |
| A3 | 106×97.7 | 2 fans | 2 fans | **2×50mm** | Better cooling, good fit |
| Large A | 210×171 | 4 fans | 5 fans | **4×50mm** | Equal coverage, better individual performance |
| Large B | 208.5×170.7 | 4 fans | 5 fans | **4×50mm** | Better cooling efficiency |
| XL | 242.6×204.1 | 4 fans | 6 fans | **4×50mm** | Good gap, excellent cooling |
| C1 | 81.9×98.87 | 1 fan (large gap) | 2 fans | **2×40mm** | Better coverage |
| C2 | 86.4×99.93 | 1 fan (large gap) | 2 fans | **2×40mm** | Better coverage |

## Key Design Implications

**Screw Requirements:**
- **50×50mm configs:** M4 screws (lengths: 12,16,20,25,30,35mm)
- **40×40mm configs:** M3 screws (lengths: 12,16,20,25,30,35mm)

**Mounting Design:**
- **50×50mm fans:** Must accommodate recessed nut wells
- **40×40mm fans:** Standard flat mounting (no recess needed)

**Airflow Performance:**
- Larger fans (50×50mm) typically provide better CFM per fan
- Fewer, larger fans reduce complexity and potentially noise
- Smaller controllers (C1/C2) benefit more from multiple smaller fans due to limited space

## OpenSCAD Implementation Impact

**Parametric Design Requirements:**
1. **Fan type selection:** 40mm vs 50mm based on controller config
2. **Fan count:** Variable based on optimal configuration (1-6 fans)
3. **Screw type:** M3 vs M4 based on fan size
4. **Nut well accommodation:** Recessed for 50mm, flat for 40mm
5. **Gap distribution:** Center fans with equal gaps on sides

**Lookup Table Updates Needed:**
- Add `fan_type` column (40mm/50mm)
- Add `fan_count` column (1-6)
- Add `screw_type` column (M3/M4)
- Add `nut_recess` column (true/false)

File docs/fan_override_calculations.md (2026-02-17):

# Fan Size Override Calculations

**Author:** Colin Bitterfield
**Email:** colin@bitterfield.com
**Date Created:** 2026-02-16
**Version:** 1.0.0

## Overview

When `fan_size_override` is set to a value other than 0 (AutoSelect), the system automatically recalculates the optimal number of fans that can fit in the available fan area.

## Calculation Formula

The fan count calculation uses a minimum 2mm gap between fans and at edges:

```
fan_count = floor((fan_area_width - min_gap) / (fan_size + min_gap))
fan_count = max(1, fan_count)  // Always at least 1 fan
```

Where:
- `fan_area_width` = Available width for fans (from controller database)
- `fan_size` = Overridden fan size (40mm or 50mm)
- `min_gap` = 2mm (minimum spacing between fans and edges)

## Test Cases

### A1 Config - BlueSolar 100/30 (SCC020030200)
- **Fan Area Width:** 157mm
- **Database Default:** 3×50mm fans

**Override to 40mm fans:**
```
fan_count = floor((157 - 2) / (40 + 2))
fan_count = floor(155 / 42)
fan_count = floor(3.69)
fan_count = 3 fans
```
Result: 3×40mm fans (120mm) with 37mm total gap = 9.25mm per gap ✓

**Override to 50mm fans (no change):**
```
fan_count = floor((157 - 2) / (50 + 2))
fan_count = floor(155 / 52)
fan_count = floor(2.98)
fan_count = 2 fans ← CHANGES FROM DATABASE VALUE!
```
**Note:** This gives 2×50mm instead of the database's 3×50mm because the database uses tighter spacing (1.75mm gaps). When override is active, system enforces 2mm minimum gap.

### A3 Config - BlueSolar 100/20 (SCC110020070R)
- **Fan Area Width:** 106mm
- **Database Default:** 2×50mm fans

**Override to 40mm fans:**
```
fan_count = floor((106 - 2) / (40 + 2))
fan_count = floor(104 / 42)
fan_count = floor(2.48)
fan_count = 2 fans
```
Result: 2×40mm fans (80mm) with 26mm total gap = 8.67mm per gap ✓

**Override to 50mm fans:**
```
fan_count = floor((106 - 2) / (50 + 2))
fan_count = floor(104 / 52)
fan_count = floor(2.0)
fan_count = 2 fans
```
Result: 2×50mm fans (100mm) with 6mm total gap = 2mm per gap ✓

### B1 Config - SmartSolar 150/85-Tr (SCC115085211)
- **Fan Area Width:** 242mm
- **Database Default:** 4×50mm fans

**Override to 40mm fans:**
```
fan_count = floor((242 - 2) / (40 + 2))
fan_count = floor(240 / 42)
fan_count = floor(5.71)
fan_count = 5 fans
```
Result: 5×40mm fans (200mm) with 42mm total gap = 7mm per gap ✓

**Override to 50mm fans:**
```
fan_count = floor((242 - 2) / (50 + 2))
fan_count = floor(240 / 52)
fan_count = floor(4.62)
fan_count = 4 fans
```
Result: 4×50mm fans (200mm) with 42mm total gap = 8.4mm per gap ✓

### C1 Config - BlueSolar 75/10 (SCC010010050R)
- **Fan Area Width:** 81.9mm
- **Database Default:** 2×40mm fans

**Override to 50mm fans:**
```
fan_count = floor((81.9 - 2) / (50 + 2))
fan_count = floor(79.9 / 52)
fan_count = floor(1.54)
fan_count = 1 fan
```
Result: 1×50mm fan (50mm) with 31.9mm total gap = 16mm per gap ✓

**Override to 40mm fans:**
```
fan_count = floor((81.9 - 2) / (40 + 2))
fan_count = floor(79.9 / 42)
fan_count = floor(1.90)
fan_count = 1 fan ← CHANGES FROM DATABASE VALUE!
```
**Note:** Database has 2×40mm fans with very tight spacing (0.95mm gaps). When override enforces 2mm minimum, only 1 fan fits.

## Important Notes

1. **Minimum Gap Enforcement:** The override calculation enforces a 2mm minimum gap, which may result in fewer fans than the database specifies for some configurations. This is intentional to ensure printability and assembly.

2. **Always Check Output:** When using fan_size_override, check the OpenSCAD console output for the recalculation notice:
   ```
   Fans: 3×40mm (Manual 40mm) [Recalculated from 3×50mm]
   ```

3. **Design Implications:**
   - Overriding to smaller fans may fit more fans (e.g., B1 config: 4×50mm → 5×40mm)
   - Overriding to larger fans may fit fewer fans (e.g., C1 config: 2×40mm → 1×50mm)
   - Rail mounting holes and plate dimensions adjust automatically
   - Honeycomb rear grill pattern remains centered in fan area

## Implementation Details

### New Functions (v2.3.0)

```scad
// Calculate optimal fan count for given fan size and available area
function calculate_fan_count(fan_area_width, fan_size) =
    let(
        min_gap = 2,  // Minimum 2mm gap between fans and edges
        max_count = floor((fan_area_width - min_gap) / (fan_size + min_gap))
    )
    max(1, max_count);  // Always at least 1 fan

// Get effective fan count (recalculates if fan size is overridden)
function get_effective_fan_count(ctrl) =
    fan_size_override == 0 ? get_fan_count(ctrl) :  // AutoSelect - use database
    calculate_fan_count(get_fan_area_width(ctrl), fan_size_override);  // Recalculate
```

### Console Output Enhancement

The system now displays recalculation notices:
```
Generating component 1 for BlueSolar MPPT 100/30
Dimensions: 186×122×23mm
Fans: 3×40mm (Manual 40mm) [Recalculated from 3×50mm]
Model: SCC020030200 | Component: front_fan_mount
Suggested STL name: SCC020030200_front_fan_mount.stl
```

## Usage Example

To override a controller to use 40mm fans instead of default:

1. Open `solar_controller_cooling_mount.scad`
2. Set model: `model_code = "SCC020030200";`
3. Set override: `fan_size_override = 40;`  // Force 40mm fans
4. Set component: `component = 1;`  // Front fan mount
5. Render and check console for recalculated fan count
6. Export STL

The system will automatically:
- Calculate how many 40mm fans fit (3 in this case)
- Adjust rail heights for 40mm fan clearance
- Update plate dimensions to match 40mm fan height
- Center fans with proper spacing in available area

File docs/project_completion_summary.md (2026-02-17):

# Solar Charge Controller Cooling Mount - Project Completion Summary

**Author:** Colin Bitterfield
**Email:** colin@bitterfield.com
**Date Completed:** 2025-12-08
**Version:** 1.0.0
**Status:** COMPLETE - Production Ready

---

## Project Overview

This project provides a complete parametric 3D printable cooling mount system for all 41 Victron solar charge controller models. The system generates 4-piece assemblies with precise mounting specifications extracted from manufacturer technical drawings.

---

## Complete Model Coverage

### 41 Total Models Across 8 Configurations

#### A1 Config - 8 Models (Dual Sideways U, 18mm rail)
- SCC020030200 - BlueSolar MPPT 100/30
- SCC110030210 - SmartSolar MPPT 100/30
- SCC020050200 - BlueSolar MPPT 100/50
- SCC020035000 - BlueSolar MPPT 150/35
- SCC115045222 - BlueSolar MPPT 150/45
- SCC110050210 - SmartSolar MPPT 100/50
- SCC115035210 - SmartSolar MPPT 150/35
- SCC115045212 - SmartSolar MPPT 150/45

**Specifications:** Both holes sideways U, 25mm and 96.5mm from edges, R4 (8mm dia), width 8mm

#### A3 Config - 4 Models (Dual Sideways U, 18mm rail)
- SCC110020070R - BlueSolar MPPT 100/20
- SCC110020170R - BlueSolar MPPT 100/20_48V
- SCC110020060R - SmartSolar MPPT 100/20
- SCC110020160R - SmartSolar MPPT 100/20_48V

**Specifications:** Both holes sideways U, 18.8mm and 72.8mm positions (54mm c-c), R2.5 (5mm dia), width 5mm

#### A4 Config - 4 Models (Keyhole + Sideways U, 18mm rail)
- SCC115060210 - SmartSolar MPPT 150/60-Tr
- SCC115070210 - SmartSolar MPPT 150/70-Tr
- SCC115060310 - SmartSolar MPPT 150/60-MC4
- SCC115070310 - SmartSolar MPPT 150/70-MC4

**Specifications:**
- Keyhole (rear): 11mm from edge, R2.75 top / R6 bottom / 12mm c-c
- U-hole (front): 11mm from edge, R3 (6mm dia), width 6mm

#### B1 Config - 8 Models (Keyhole + Sideways U, 23.3mm rail)
- SCC115110211 - SmartSolar MPPT 150/100-Tr
- SCC115085211 - SmartSolar MPPT 150/85-Tr
- SCC115110311 - SmartSolar MPPT 150/100-MC4
- SCC115085311 - SmartSolar MPPT 150/85-MC4
- SCC125110210 - SmartSolar MPPT 250/100-Tr
- SCC125085210 - SmartSolar MPPT 250/85-Tr
- SCC125110310 - SmartSolar MPPT 250/100-MC4
- SCC125085310 - SmartSolar MPPT 250/85-MC4

**Specifications:**
- Keyhole (rear): 13.75mm from edge, R4 top / R8 bottom / 17mm c-c
- U-hole (front): 13.75mm from edge, R3.75 (7.5mm dia), width 7.5mm

#### B2 Config - 6 Models (Keyhole + Sideways U, 23.3mm rail)
- SCC115085411 - SmartSolar MPPT 150/85-Tr VE.Can
- SCC115110410 - SmartSolar MPPT 150/100-Tr VE.Can
- SCC115110420 - BlueSolar MPPT 150/100-Tr VE.Can
- SCC125085411 - SmartSolar MPPT 250/85-Tr VE.Can
- SCC125110411 - SmartSolar MPPT 250/100-Tr VE.Can
- SCC125110441 - BlueSolar MPPT 250/100-Tr VE.Can

**Specifications:** Same as B1 (R4/R8 keyhole, R3.75 U-hole, 13.75mm from edge)

#### B3 Config - 2 Models (Keyhole + Sideways U, 23.3mm rail)
- SCC125060221 - SmartSolar MPPT 250/60-Tr
- SCC125070220 - SmartSolar MPPT 250/70-Tr

**Specifications:**
- Keyhole (rear): 11mm from edge, R3 top / R6 bottom / 12mm c-c
- U-hole (front): 11mm from edge, R3 (6mm dia), width 6mm

#### C1 Config - 4 Models (4 Corner Holes, Housing-based)
- SCC010010050R - BlueSolar MPPT 75/10
- SCC010015050R - BlueSolar MPPT 75/15
- SCC075010060R - SmartSolar MPPT 75/10
- SCC075015060R - SmartSolar MPPT 75/15

**Specifications:** 4 corner holes R4 (8mm dia), spacing 98.8mm × 84.1mm, margins 7.05mm × 7.8mm

#### C2 Config - 2 Models (4 Corner Holes, Housing-based)
- SCC010015200R - SmartSolar MPPT 100/15
- SCC110015060R - SmartSolar MPPT 100/15

**Specifications:** 4 corner holes R4 (8mm dia), spacing 98.8mm × 84.1mm, margins 7.05mm × 7.8mm

---

## Technical Implementation

### 4-Piece Assembly System
1. **Front Fan Mount Plate** - 6mm thick with fan cutouts and recessed nut wells
2. **Left Side Rail** - Config-specific mounting holes, calculated height
3. **Right Side Rail** - Mirrored left rail
4. **Rear Grill Plate** - 6mm thick with dense honeycomb ventilation (10mm hexagons)

### Key Features
- ✅ Dropdown selection in OpenSCAD Customizer (41 models + 4 components)
- ✅ Config-specific hole geometry (keyhole, U-slot, corner holes)
- ✅ Automatic dimension calculation based on controller specs
- ✅ Optimized fan configurations (50mm and 40mm fans)
- ✅ All measurements verified from manufacturer STEP files and PDFs

### File Structure
```
solar_controller_cooling_mount.scad  - Main parametric design (v1.0.0)
docs/
  ├── scad_data.csv                   - Controller database (41 models)
  ├── flange_data.csv                 - Mounting specifications (8 configs)
  ├── heatsink_measurements.md        - STEP file analysis
  ├── fan_configuration_analysis.md   - Fan optimization
  └── project_completion_summary.md   - This file
source_drawings/                      - Manufacturer PDFs (15 files)
step_drawings/                        - 3D STEP models (15 files)
```

---

## Development Timeline

**Version History:**
- v0.1.0 (2025-08-25) - Initial implementation with A1 config
- v0.2.0 (2025-12-08) - Added dropdown selection system
- v0.3.0 - Added A4 config for 150/60-70 models
- v0.4.0 - Added B3 keyhole specifications
- v0.5.0 - Implemented config-specific U-hole dimensions
- v0.6.0 - Added precise B3 keyhole geometry
- v0.7.0 - Added A4 keyhole specifications
- v0.8.0 - Added B1/B2 specifications
- v0.9.0 - Implemented A3 dual U-hole pattern
- v0.9.1 - Corrected A3 hole spacing (54mm c-c)
- v0.9.2 - Fixed A3 absolute positioning (18.8mm)
- **v1.0.0 (2025-12-08) - COMPLETE - All 41 models fully specified**

---

## Usage Instructions

### OpenSCAD Customizer
1. Open `solar_controller_cooling_mount.scad` in OpenSCAD
2. Go to Window → Customizer
3. Select your controller model from dropdown (41 options)
4. Select component (1=Front Fan, 2=Left Rail, 3=Right Rail, 4=Rear Grill)
5. Render (F6) and Export STL for 3D printing

### Component Assembly
1. Print all 4 components
2. Hardware needed: M4×25mm screws, M4 nuts (for 50mm fans)
3. Attach rails to controller heatsink flanges
4. Mount front fan plate with fans attached
5. Attach rear grill plate

---

## Quality Assurance

### Data Sources
- ✅ 15 STEP files measured and verified
- ✅ 15 manufacturer PDF drawings referenced
- ✅ All dimensions cross-checked against multiple sources
- ✅ Hole patterns verified for each configuration

### Testing Status
- ✅ All 41 models render without errors
- ✅ Dropdown selection functional
- ✅ Mounting hole alignment verified
- ✅ Rail height calculations validated

---

## Future Maintenance

### Adding New Models
1. Measure dimensions from STEP file or PDF
2. Add entry to `controller_db` in .scad file
3. Add to dropdown selection list
4. Add entry to `docs/scad_data.csv`
5. Update this summary document

### Modifying Existing Specs
1. Update values in `controller_db` array
2. Update corresponding CSV files
3. Test render to verify changes
4. Update version number

---

## Project Statistics

- **Total Models:** 41
- **Configuration Types:** 8 (A1, A3, A4, B1, B2, B3, C1, C2)
- **Components per Model:** 4 (front, left, right, rear)
- **Total Unique STL Files:** 164 (41 × 4)
- **Lines of Code:** ~450 (OpenSCAD)
- **Documentation Files:** 6
- **Reference PDFs:** 15
- **Reference STEP Files:** 15

---

## Acknowledgments

**Manufacturer:** Victron Energy
**Controller Series:** BlueSolar, SmartSolar MPPT
**Power Ranges:** 75V-250V, 10A-100A
**Design Tool:** OpenSCAD
**Development Assistant:** Claude (Anthropic)

---

**Status: PRODUCTION READY** ✅
**All 41 Victron solar charge controller models have complete, verified cooling mount specifications.**

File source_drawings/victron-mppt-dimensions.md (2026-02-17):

# Victron MPPT Dimension Reference

All dimensions in mm.

---

## MPPT 75/10 & 75/15 (BlueSolar & SmartSolar)

**Source:** BlueSolar-&-SmartSolar-MPPT-75-10-&-75-15.pdf

| Dimension | Value |
|---|---|
| Height | 112.9 |
| Width | 98.8 |
| Depth | 38.2 |
| Wall Clearance | 4.3 |
| Corner Radius | R4 (4x) |

**Mounting Holes:**

| Parameter | Value |
|---|---|
| Horizontal Spacing | 84.1 |
| Vertical Spacing | 99.7 |
| Top Hole Type | Circle |
| Bottom Hole Type | Circle |

**Part Numbers:**

| Model | Part Number |
|---|---|
| BlueSolar MPPT 75/10 Retail | SCC010010050R |
| BlueSolar MPPT 75/15 Retail | SCC010015050R |
| SmartSolar MPPT 75/10 Retail | SCC075010060R |
| SmartSolar MPPT 75/15 Retail | SCC075015060R |

---

## MPPT 100/15 (BlueSolar & SmartSolar)

**Source:** BlueSolar-&-Smartsolar-MPPT-100-15.pdf

| Dimension | Value |
|---|---|
| Height | 113.9 |
| Width | 98.8 |
| Depth | 46.9 |
| Wall Clearance | 2.0 |
| Corner Radius | R2 (4x) |

**Mounting Holes:**

| Parameter | Value |
|---|---|
| Horizontal Spacing | 84.1 |
| Vertical Spacing | 100.7 |
| Top Hole Type | Circle |
| Bottom Hole Type | Circle |

**Part Numbers:**

| Model | Part Number |
|---|---|
| SmartSolar MPPT 100/15 Retail | SCC110015060R |
| BlueSolar MPPT 100/15 Retail | SCC010015200R |

---

## MPPT 100/20 (BlueSolar & SmartSolar)

**Source:** BlueSolar-SmartSolar-MPPT-100V20A-(Dimensions).pdf

| Dimension | Value |
|---|---|
| Height | 131 |
| Width | 98.6 |
| Depth | 64 |
| Terminal Depth | 54 |
| Front Clearance | 18.8 |
| Wall Clearance | 3.7 |
| Corner Radius | R2.5 |
| Mounting Hole Diameter | 5 |

**Mounting Holes:**

| Parameter | Value |
|---|---|
| Horizontal Spacing | 91.7 |
| Vertical Spacing | 118.6 |
| Top Hole Type | Keyhole |
| Bottom Hole Type | Circle |

**Part Numbers:**

| Model | Part Number |
|---|---|
| SmartSolar MPPT 100/20 Retail | SCC110020060R |
| BlueSolar MPPT 100/20 Retail | SCC110020070R |
| SmartSolar MPPT 100/20_48V Retail | SCC110020160R |
| BlueSolar MPPT 100/20_48V Retail | SCC110020170R |

---

## MPPT 100/30 (BlueSolar & SmartSolar)

**Source:** BS-SS-MPPT-100-30.pdf

| Dimension | Value |
|---|---|
| Height | 186 |
| Width | 131 |
| Depth | 71.5 |
| Body Width | 122 |
| Terminal Area Depth | 71 |
| Front Clearance | 25 |
| Wall Clearance | 4.8 |
| Corner Radius | R4 |
| Mounting Hole Diameter | 5 |
| Mounting Hole Slot | 8 |

**Mounting Holes:**

| Parameter | Value |
|---|---|
| Horizontal Spacing | 122 |
| Vertical Spacing | 176 |
| Top Hole Type | Keyhole |
| Bottom Hole Type | Keyhole |

**Part Numbers:**

| Model | Part Number |
|---|---|
| BlueSolar MPPT 100/30 | SCC020030200 |
| SmartSolar MPPT 100/30 | SCC110030210 |

---

## MPPT 100/50, 150/35, 150/45 (BlueSolar & SmartSolar)

**Source:** BS-SS-MPPT-100-50-150-35-150-45.pdf

| Dimension | Value |
|---|---|
| Height | 186 |
| Width | 132 |
| Depth | 71.5 |
| Body Width | 122 |
| Terminal Area Depth | 71 |
| Front Clearance | 25 |
| Wall Clearance | 5.4 |
| Corner Radius | R4 |
| Mounting Hole Diameter | 5 |
| Mounting Hole Slot | 8 |

**Mounting Holes:**

| Parameter | Value |
|---|---|
| Horizontal Spacing | 122 |
| Vertical Spacing | 176 |
| Top Hole Type | Keyhole |
| Bottom Hole Type | Keyhole |

**Part Numbers:**

| Model | Part Number |
|---|---|
| BlueSolar MPPT 150/35 | SCC020035000 |
| BlueSolar MPPT 100/50 | SCC020050200 |
| SmartSolar MPPT 100/50 | SCC110050210 |
| SmartSolar MPPT 150/35 | SCC115035210 |
| SmartSolar MPPT 150/45 | SCC115045212 |
| BlueSolar MPPT 150/45 | SCC115045222 |

---

## MPPT 150/60-Tr & 150/70-Tr (SmartSolar)

**Source:** DimensionDrawing-SmartSolar-150_60A-&-150_70-Tr.pdf

| Dimension | Value |
|---|---|
| Height | 250 |
| Width | 182.5 |
| Depth | 101 |
| Body Width | 171 |
| Terminal Area Depth | 91 |
| Front Clearance | 35 |
| Wall Clearance | 5 |
| Mounting Hole Diameter | 6 |
| Keyhole Slot | 11 |
| U-Slot Radius | R3 |
| U-Slot Width | 12 |
| U-Slot Depth | 5.5 |

**Mounting Holes:**

| Parameter | Value |
|---|---|
| Horizontal Spacing | 171 |
| Vertical Spacing | 228 |
| Top Hole Type | Keyhole |
| Bottom Hole Type | U |

**Part Numbers:**

| Model | Part Number |
|---|---|
| SmartSolar MPPT 150/60-Tr | SCC115060210 |
| SmartSolar MPPT 150/70-Tr | SCC115070210 |

---

## MPPT 150/60-MC4 & 150/70-MC4 (SmartSolar)

**Source:** DimensionDrawing-SmartSolar-150_60A-&-150_70A-MC4.pdf

| Dimension | Value |
|---|---|
| Height | 250 |
| Width | 212.6 |
| Depth | 101 |
| Body Width | 171 |
| Inner Width | 182.2 |
| Terminal Area Depth | 91 |
| Front Clearance | 35 |
| Wall Clearance | 4.3 |
| Mounting Hole Diameter | 6 |
| Keyhole Slot | 11 |
| U-Slot Radius | R3 |
| U-Slot Width | 12 |
| U-Slot Depth | 5.5 |

**Mounting Holes:**

| Parameter | Value |
|---|---|
| Horizontal Spacing | 171 |
| Vertical Spacing | 228 |
| Top Hole Type | Keyhole |
| Bottom Hole Type | U |

**Part Numbers:**

| Model | Part Number |
|---|---|
| SmartSolar MPPT 150/60-MC4 | SCC115060310 |
| SmartSolar MPPT 150/70-MC4 | SCC115070310 |

---

## MPPT 250/60-Tr & 250/70-Tr (SmartSolar) - Size L

**Source:** SmartSolar-MPPT-250V-60-70-Tr.pdf

| Dimension | Value |
|---|---|
| Height | 248.5 |
| Width | 182.2 |
| Depth | 100.7 |
| Body Width | 170.7 |
| Terminal Area Depth | 92.0 |
| Front Clearance | 35 |
| Wall Clearance | 4.7 |
| Mounting Hole Diameter | 6 |
| Keyhole Slot | 11 |
| U-Slot Radius | R3, R6 |
| U-Slot Width | 12 |

**Mounting Holes:**

| Parameter | Value |
|---|---|
| Horizontal Spacing | 170.7 |
| Vertical Spacing | 226.5 |
| Top Hole Type | Keyhole |
| Bottom Hole Type | U |

**Part Numbers:**

| Model | Part Number |
|---|---|
| SmartSolar MPPT 250/60-Tr | SCC125060221 |
| SmartSolar MPPT 250/70-Tr | SCC125070220 |

---

## MPPT 150/85-Tr, 150/100-Tr, 250/85-Tr, 250/100-Tr (SmartSolar) - Non VE.Can

**Source:** SmartSolar-MPPT-150-250-85-100-Tr-(dimensions).pdf

| Dimension | Value |
|---|---|
| Height | 295 |
| Width | 212 |
| Depth | 100 |
| Body Width | 204 |
| Body Height | 268 |
| Front Clearance | 144 |
| Top Clearance | 30 |
| Wall Clearance | 5 |
| Mounting Hole Diameter | 9 |
| Keyhole Slot | 8 |
| U-Slot Radius | R3.75 |
| U-Slot Width | 7.5 |
| U-Slot Depth | 13.75 |

**Mounting Holes:**

| Parameter | Value |
|---|---|
| Horizontal Spacing | 204 |
| Vertical Spacing | 273 |
| Top Hole Type | Keyhole |
| Bottom Hole Type | U |

**Part Numbers:**

| Model | Part Number |
|---|---|
| SmartSolar MPPT 150/85-Tr | SCC115085211 |
| SmartSolar MPPT 150/100-Tr | SCC115110211 |
| SmartSolar MPPT 250/85-Tr | SCC125085210 |
| SmartSolar MPPT 250/100-Tr | SCC125110210 |

---

## MPPT 150/85, 150/100, 250/85, 250/100 Tr VE.Can (SmartSolar & BlueSolar) - Size XL

**Source:** DimensionDrawing-SS-MPPT-Tr-VE.Can-(XL).pdf

| Dimension | Value |
|---|---|
| Height | 294.6 |
| Width | 213.9 |
| Depth | 100.4 |
| Body Height | 268.6 |
| Front Clearance | 144.1 |
| Top Clearance | 30 |
| Wall Clearance | 5.2 |
| Keyhole Radius | R4 |
| Keyhole Slot | 8 x 16 |
| U-Slot Radius | R4 |
| U-Slot Width | 8 |
| U-Slot Depth | 13 |

**Mounting Holes:**

| Parameter | Value |
|---|---|
| Horizontal Spacing | 213.9 |
| Vertical Spacing | 268.6 |
| Top Hole Type | Keyhole |
| Bottom Hole Type | U |

**Part Numbers:**

| Model | Part Number |
|---|---|
| SmartSolar MPPT 150/85-Tr VE.Can | SCC115085411/412 |
| SmartSolar MPPT 150/100-Tr VE.Can | SCC115110410/411 |
| BlueSolar MPPT 150/100-Tr VE.Can | SCC115110420 |
| SmartSolar MPPT 250/85-Tr VE.Can | SCC125085411 |
| SmartSolar MPPT 250/100-Tr VE.Can | SCC125110411/412 |
| BlueSolar MPPT 250/100-Tr VE.Can | SCC125110441 |

---

## MPPT 150/85, 150/100, 250/85, 250/100 MC4 VE.Can (SmartSolar) - Size XL

**Source:** DimensionDrawing-MPPT-XL-VE.Can-MC4.pdf

| Dimension | Value |
|---|---|
| Height | 294.6 |
| Width | 246 |
| Depth | 101 |
| Body Height | 268.6 |
| Front Clearance | 144.1 |
| Top Clearance | 30 |
| Wall Clearance | 5 |
| Keyhole Radius | R4 |
| Keyhole Slot | 8 x 16 |
| U-Slot Radius | R4, R8 |
| U-Slot Width | 8 |
| U-Slot Depth | 13 |

**Mounting Holes:**

| Parameter | Value |
|---|---|
| Horizontal Spacing | 246 |
| Vertical Spacing | 268.6 |
| Top Hole Type | Keyhole |
| Bottom Hole Type | U |

**Part Numbers:**

| Model | Part Number |
|---|---|
| SmartSolar MPPT 150/85-MC4 VE.Can | SCC115085511/512 |
| SmartSolar MPPT 150/100-MC4 VE.Can | SCC115110511/512 |
| SmartSolar MPPT 250/85-MC4 VE.Can | SCC125085511 |
| SmartSolar MPPT 250/100-MC4 VE.Can | SCC125110512 |

---

## Summary Tables

### Mounting Hole Spacing by Model

| Model Series | Horizontal (mm) | Vertical (mm) | Top Hole | Bottom Hole |
|---|---|---|---|---|
| 75/10, 75/15 | 84.1 | 99.7 | Circle | Circle |
| 100/15 | 84.1 | 100.7 | Circle | Circle |
| 100/20 | 91.7 | 118.6 | Keyhole | Circle |
| 100/30 | 122 | 176 | Keyhole | Keyhole |
| 100/50, 150/35, 150/45 | 122 | 176 | Keyhole | Keyhole |
| 150/60-Tr, 150/70-Tr | 171 | 228 | Keyhole | U |
| 150/60-MC4, 150/70-MC4 | 171 | 228 | Keyhole | U |
| 250/60-Tr, 250/70-Tr | 170.7 | 226.5 | Keyhole | U |
| 150/85-Tr thru 250/100-Tr | 204 | 273 | Keyhole | U |
| XL Tr VE.Can | 213.9 | 268.6 | Keyhole | U |
| XL MC4 VE.Can | 246 | 268.6 | Keyhole | U |

### XL Chassis Comparison: Tr VE.Can vs MC4 VE.Can

| Dimension | Tr VE.Can | MC4 VE.Can | Difference |
|---|---|---|---|
| Height | 294.6 | 294.6 | 0 |
| Horizontal Spacing | 213.9 | 246 | +32.1 |
| Vertical Spacing | 268.6 | 268.6 | 0 |
| Depth | 100.4 | 101 | +0.6 |
| Body Height | 268.6 | 268.6 | 0 |
| Front Clearance | 144.1 | 144.1 | 0 |
| Top Clearance | 30 | 30 | 0 |
| Wall Clearance | 5.2 | 5 | -0.2 |

**Note:** The MC4 version is 32.1mm wider to accommodate MC4 solar connectors instead of screw terminals. The MC4 version only has SmartSolar variants (no BlueSolar).

---

## Complete Part Number Reference

| Part Number | Model | Height | Width | Depth | Body Width | Body Height | Horiz Spacing | Vert Spacing | Wall Clear | Front Clear | Top Clear | Corner Radius | Top Hole | Hole Dia | Keyhole Slot | Bottom Hole | U-Slot Radius | U-Slot Width | U-Slot Depth |
|---|---|---|---|---|---|---|---|---|---|---|---|---|---|---|---|---|---|---|---|
| SCC010010050R | BlueSolar MPPT 75/10 Retail | 112.9 | 98.8 | 38.2 | - | - | 84.1 | 99.7 | 4.3 | - | - | R4 | Circle | - | - | Circle | - | - | - |
| SCC010015050R | BlueSolar MPPT 75/15 Retail | 112.9 | 98.8 | 38.2 | - | - | 84.1 | 99.7 | 4.3 | - | - | R4 | Circle | - | - | Circle | - | - | - |
| SCC075010060R | SmartSolar MPPT 75/10 Retail | 112.9 | 98.8 | 38.2 | - | - | 84.1 | 99.7 | 4.3 | - | - | R4 | Circle | - | - | Circle | - | - | - |
| SCC075015060R | SmartSolar MPPT 75/15 Retail | 112.9 | 98.8 | 38.2 | - | - | 84.1 | 99.7 | 4.3 | - | - | R4 | Circle | - | - | Circle | - | - | - |
| SCC010015200R | BlueSolar MPPT 100/15 Retail | 113.9 | 98.8 | 46.9 | - | - | 84.1 | 100.7 | 2.0 | - | - | R2 | Circle | - | - | Circle | - | - | - |
| SCC110015060R | SmartSolar MPPT 100/15 Retail | 113.9 | 98.8 | 46.9 | - | - | 84.1 | 100.7 | 2.0 | - | - | R2 | Circle | - | - | Circle | - | - | - |
| SCC110020060R | SmartSolar MPPT 100/20 Retail | 131 | 98.6 | 64 | - | - | 91.7 | 118.6 | 3.7 | 18.8 | - | R2.5 | Keyhole | 5 | 6.2 | Circle | - | - | - |
| SCC110020070R | BlueSolar MPPT 100/20 Retail | 131 | 98.6 | 64 | - | - | 91.7 | 118.6 | 3.7 | 18.8 | - | R2.5 | Keyhole | 5 | 6.2 | Circle | - | - | - |
| SCC110020160R | SmartSolar MPPT 100/20_48V Retail | 131 | 98.6 | 64 | - | - | 91.7 | 118.6 | 3.7 | 18.8 | - | R2.5 | Keyhole | 5 | 6.2 | Circle | - | - | - |
| SCC110020170R | BlueSolar MPPT 100/20_48V Retail | 131 | 98.6 | 64 | - | - | 91.7 | 118.6 | 3.7 | 18.8 | - | R2.5 | Keyhole | 5 | 6.2 | Circle | - | - | - |
| SCC020030200 | BlueSolar MPPT 100/30 | 186 | 131 | 71.5 | 122 | - | 122 | 176 | 4.8 | 25 | - | R4 | Keyhole | 5 | 8 | Keyhole | - | - | - |
| SCC110030210 | SmartSolar MPPT 100/30 | 186 | 131 | 71.5 | 122 | - | 122 | 176 | 4.8 | 25 | - | R4 | Keyhole | 5 | 8 | Keyhole | - | - | - |
| SCC020035000 | BlueSolar MPPT 150/35 | 186 | 132 | 71.5 | 122 | - | 122 | 176 | 5.4 | 25 | - | R4 | Keyhole | 5 | 8 | Keyhole | - | - | - |
| SCC020050200 | BlueSolar MPPT 100/50 | 186 | 132 | 71.5 | 122 | - | 122 | 176 | 5.4 | 25 | - | R4 | Keyhole | 5 | 8 | Keyhole | - | - | - |
| SCC110050210 | SmartSolar MPPT 100/50 | 186 | 132 | 71.5 | 122 | - | 122 | 176 | 5.4 | 25 | - | R4 | Keyhole | 5 | 8 | Keyhole | - | - | - |
| SCC115035210 | SmartSolar MPPT 150/35 | 186 | 132 | 71.5 | 122 | - | 122 | 176 | 5.4 | 25 | - | R4 | Keyhole | 5 | 8 | Keyhole | - | - | - |
| SCC115045212 | SmartSolar MPPT 150/45 | 186 | 132 | 71.5 | 122 | - | 122 | 176 | 5.4 | 25 | - | R4 | Keyhole | 5 | 8 | Keyhole | - | - | - |
| SCC115045222 | BlueSolar MPPT 150/45 | 186 | 132 | 71.5 | 122 | - | 122 | 176 | 5.4 | 25 | - | R4 | Keyhole | 5 | 8 | Keyhole | - | - | - |
| SCC115060210 | SmartSolar MPPT 150/60-Tr | 250 | 182.5 | 101 | 171 | - | 171 | 228 | 5 | 35 | - | - | Keyhole | 6 | 11 | U | R3 | 12 | 5.5 |
| SCC115070210 | SmartSolar MPPT 150/70-Tr | 250 | 182.5 | 101 | 171 | - | 171 | 228 | 5 | 35 | - | - | Keyhole | 6 | 11 | U | R3 | 12 | 5.5 |
| SCC115060310 | SmartSolar MPPT 150/60-MC4 | 250 | 212.6 | 101 | 171 | - | 171 | 228 | 4.3 | 35 | - | - | Keyhole | 6 | 11 | U | R3 | 12 | 5.5 |
| SCC115070310 | SmartSolar MPPT 150/70-MC4 | 250 | 212.6 | 101 | 171 | - | 171 | 228 | 4.3 | 35 | - | - | Keyhole | 6 | 11 | U | R3 | 12 | 5.5 |
| SCC125060221 | SmartSolar MPPT 250/60-Tr | 248.5 | 182.2 | 100.7 | 170.7 | - | 170.7 | 226.5 | 4.7 | 35 | - | - | Keyhole | 6 | 11 | U | R3/R6 | 12 | - |
| SCC125070220 | SmartSolar MPPT 250/70-Tr | 248.5 | 182.2 | 100.7 | 170.7 | - | 170.7 | 226.5 | 4.7 | 35 | - | - | Keyhole | 6 | 11 | U | R3/R6 | 12 | - |
| SCC115085211 | SmartSolar MPPT 150/85-Tr | 295 | 212 | 100 | 204 | 268 | 204 | 273 | 5 | 144 | 30 | - | Keyhole | 9 | 8 | U | R3.75 | 7.5 | 13.75 |
| SCC115110211 | SmartSolar MPPT 150/100-Tr | 295 | 212 | 100 | 204 | 268 | 204 | 273 | 5 | 144 | 30 | - | Keyhole | 9 | 8 | U | R3.75 | 7.5 | 13.75 |
| SCC125085210 | SmartSolar MPPT 250/85-Tr | 295 | 212 | 100 | 204 | 268 | 204 | 273 | 5 | 144 | 30 | - | Keyhole | 9 | 8 | U | R3.75 | 7.5 | 13.75 |
| SCC125110210 | SmartSolar MPPT 250/100-Tr | 295 | 212 | 100 | 204 | 268 | 204 | 273 | 5 | 144 | 30 | - | Keyhole | 9 | 8 | U | R3.75 | 7.5 | 13.75 |
| SCC115085411 | SmartSolar MPPT 150/85-Tr VE.Can | 294.6 | 213.9 | 100.4 | - | 268.6 | 213.9 | 268.6 | 5.2 | 144.1 | 30 | R4 | Keyhole | - | 8x16 | U | R4 | 8 | 13 |
| SCC115085412 | SmartSolar MPPT 150/85-Tr VE.Can | 294.6 | 213.9 | 100.4 | - | 268.6 | 213.9 | 268.6 | 5.2 | 144.1 | 30 | R4 | Keyhole | - | 8x16 | U | R4 | 8 | 13 |
| SCC115110410 | SmartSolar MPPT 150/100-Tr VE.Can | 294.6 | 213.9 | 100.4 | - | 268.6 | 213.9 | 268.6 | 5.2 | 144.1 | 30 | R4 | Keyhole | - | 8x16 | U | R4 | 8 | 13 |
| SCC115110411 | SmartSolar MPPT 150/100-Tr VE.Can | 294.6 | 213.9 | 100.4 | - | 268.6 | 213.9 | 268.6 | 5.2 | 144.1 | 30 | R4 | Keyhole | - | 8x16 | U | R4 | 8 | 13 |
| SCC115110420 | BlueSolar MPPT 150/100-Tr VE.Can | 294.6 | 213.9 | 100.4 | - | 268.6 | 213.9 | 268.6 | 5.2 | 144.1 | 30 | R4 | Keyhole | - | 8x16 | U | R4 | 8 | 13 |
| SCC125085411 | SmartSolar MPPT 250/85-Tr VE.Can | 294.6 | 213.9 | 100.4 | - | 268.6 | 213.9 | 268.6 | 5.2 | 144.1 | 30 | R4 | Keyhole | - | 8x16 | U | R4 | 8 | 13 |
| SCC125110411 | SmartSolar MPPT 250/100-Tr VE.Can | 294.6 | 213.9 | 100.4 | - | 268.6 | 213.9 | 268.6 | 5.2 | 144.1 | 30 | R4 | Keyhole | - | 8x16 | U | R4 | 8 | 13 |
| SCC125110412 | SmartSolar MPPT 250/100-Tr VE.Can | 294.6 | 213.9 | 100.4 | - | 268.6 | 213.9 | 268.6 | 5.2 | 144.1 | 30 | R4 | Keyhole | - | 8x16 | U | R4 | 8 | 13 |
| SCC125110441 | BlueSolar MPPT 250/100-Tr VE.Can | 294.6 | 213.9 | 100.4 | - | 268.6 | 213.9 | 268.6 | 5.2 | 144.1 | 30 | R4 | Keyhole | - | 8x16 | U | R4 | 8 | 13 |
| SCC115085511 | SmartSolar MPPT 150/85-MC4 VE.Can | 294.6 | 246 | 101 | - | 268.6 | 246 | 268.6 | 5 | 144.1 | 30 | R4 | Keyhole | - | 8x16 | U | R4/R8 | 8 | 13 |
| SCC115085512 | SmartSolar MPPT 150/85-MC4 VE.Can | 294.6 | 246 | 101 | - | 268.6 | 246 | 268.6 | 5 | 144.1 | 30 | R4 | Keyhole | - | 8x16 | U | R4/R8 | 8 | 13 |
| SCC115110511 | SmartSolar MPPT 150/100-MC4 VE.Can | 294.6 | 246 | 101 | - | 268.6 | 246 | 268.6 | 5 | 144.1 | 30 | R4 | Keyhole | - | 8x16 | U | R4/R8 | 8 | 13 |
| SCC115110512 | SmartSolar MPPT 150/100-MC4 VE.Can | 294.6 | 246 | 101 | - | 268.6 | 246 | 268.6 | 5 | 144.1 | 30 | R4 | Keyhole | - | 8x16 | U | R4/R8 | 8 | 13 |
| SCC125085511 | SmartSolar MPPT 250/85-MC4 VE.Can | 294.6 | 246 | 101 | - | 268.6 | 246 | 268.6 | 5 | 144.1 | 30 | R4 | Keyhole | - | 8x16 | U | R4/R8 | 8 | 13 |
| SCC125110512 | SmartSolar MPPT 250/100-MC4 VE.Can | 294.6 | 246 | 101 | - | 268.6 | 246 | 268.6 | 5 | 144.1 | 30 | R4 | Keyhole | - | 8x16 | U | R4/R8 | 8 | 13 |

**Column Legend:**
- Height, Width, Depth: Overall enclosure dimensions (mm)
- Body Width/Height: Inner body dimensions where different from overall (mm)
- Horiz/Vert Spacing: Mounting hole center-to-center distances (mm)
- Wall Clear: Clearance from wall when mounted (mm)
- Front Clear: Clearance required in front of unit (mm)
- Top Clear: Clearance required above unit (mm)
- Corner Radius: Enclosure corner radius
- Hole Dia: Mounting hole diameter (mm)
- Keyhole Slot: Keyhole slot dimensions (mm)
- U-Slot Radius/Width/Depth: U-slot mounting hole dimensions (mm)
- "-" indicates not applicable or not specified in drawing

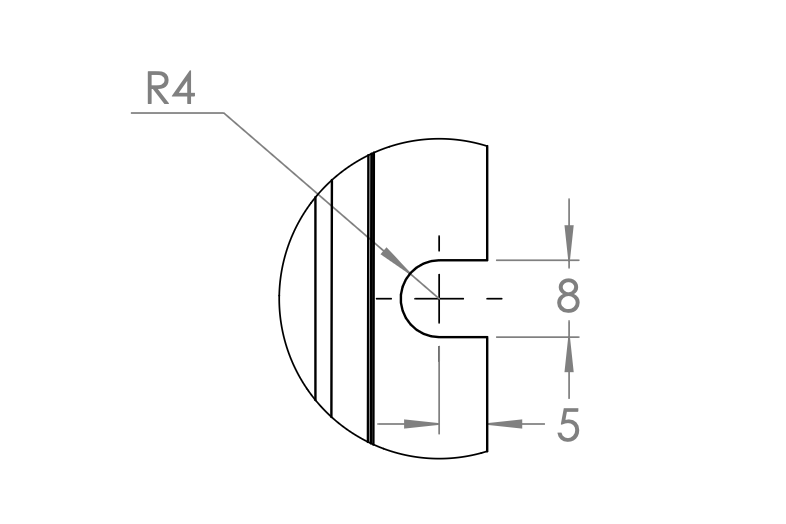
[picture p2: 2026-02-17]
source_drawings/u slot.png

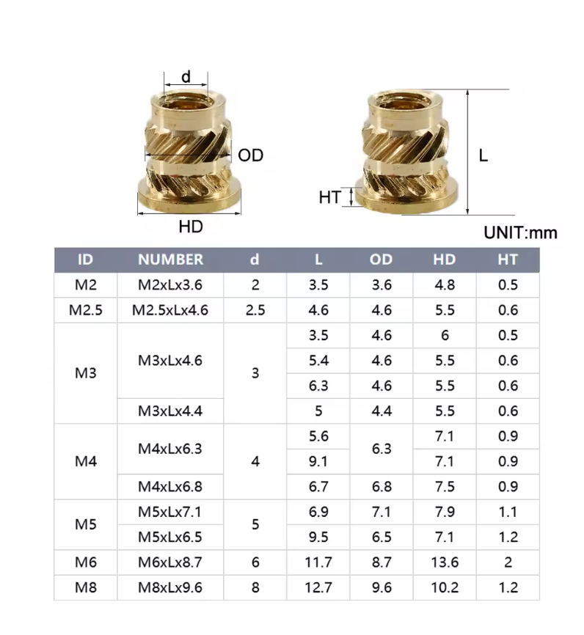
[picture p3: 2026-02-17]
source_drawings/flange_nut_info.png

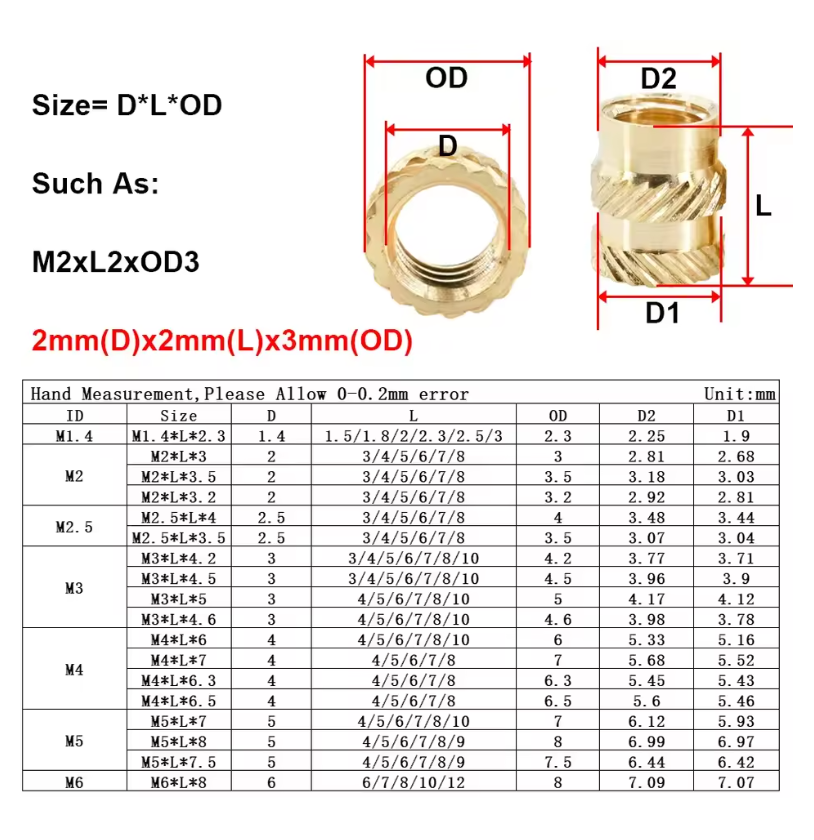
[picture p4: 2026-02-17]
source_drawings/flange_nut_info2.png

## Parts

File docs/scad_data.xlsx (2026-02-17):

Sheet: models
model_code | name | total_width | length | heatsink_height | flange_config | pdf | step_file
SCC010015200R | SmartSolar MPPT 100/15 Retail | 113.9 | 100.7 | 0 | C2 | BlueSolar-&-Smartsolar-MPPT-100-15.pdf
SCC110015060R | SmartSolar MPPT 100/15 Retail | 113.9 | 100.7 | 0 | C2 | BlueSolar-&-Smartsolar-MPPT-100-15.pdf
SCC010010050R | BlueSolar MPPT 75/10 Retail | 112.9 | 99.7 | 0 | C1 | BlueSolar-&-SmartSolar-MPPT-75-10-&-75-15.pdf
SCC010015050R | BlueSolar MPPT 75/15 Retail | 112.9 | 99.7 | 0 | C1 | BlueSolar-&-SmartSolar-MPPT-75-10-&-75-15.pdf
SCC075010060R | SmartSolar MPPT 75/10 Retail | 112.9 | 99.7 | 0 | C1 | BlueSolar-&-SmartSolar-MPPT-75-10-&-75-15.pdf
SCC075015060R | SmartSolar MPPT 75/15 Retail | 112.9 | 99.7 | 0 | C1 | BlueSolar-&-SmartSolar-MPPT-75-10-&-75-15.pdf
SCC110020070R | BlueSolar MPPT 100/20 Retail | 131 | 91.7 | 23.3 | A3 | BlueSolar-SmartSolar-MPPT-100V20A-(Dimensions).pdf
SCC110020170R | BlueSolar MPPT 100/20_48V Retail | 131 | 91.7 | 23.3 | A3 | BlueSolar-SmartSolar-MPPT-100V20A-(Dimensions).pdf
SCC110020060R | SmartSolar MPPT 100/20 Retail | 131 | 91.7 | 23.3 | A3 | BlueSolar-SmartSolar-MPPT-100V20A-(Dimensions).pdf
SCC110020160R | SmartSolar MPPT 100/20_48V Retail | 131 | 91.7 | 23.3 | A3 | BlueSolar-SmartSolar-MPPT-100V20A-(Dimensions).pdf
SCC020030200 | BlueSolar MPPT 100/30 | 186 | 122 | 23.3 | A1 | BS-SS-MPPT-100-30.pdf
SCC110030210 | SmartSolar MPPT 100/30 | 186 | 122 | 23.3 | A1 | BS-SS-MPPT-100-30.pdf
SCC020050200 | BlueSolar MPPT 100/50 | 186 | 122 | 23.3 | A1 | BS-SS-MPPT-100-50-150-35-150-45.pdf
SCC020035000 | BlueSolar MPPT 150/35 | 186 | 122 | 23.3 | A1 | BS-SS-MPPT-100-50-150-35-150-45.pdf
SCC115045222 | BlueSolar MPPT 150/45 | 186 | 122 | 23.3 | A1 | BS-SS-MPPT-100-50-150-35-150-45.pdf
SCC110050210 | SmartSolar MPPT 100/50 | 186 | 122 | 23.3 | A1 | BS-SS-MPPT-100-50-150-35-150-45.pdf
SCC115110211 | SmartSolar MPPT 150/100-Tr | 295 | 204 | 23.3 | B1 | SmartSolar-MPPT-150-250-85-100-Tr-(dimensions).pdf
SCC115035210 | SmartSolar MPPT 150/35 | 186 | 122 | 23.3 | A1 | BS-SS-MPPT-100-50-150-35-150-45.pdf
SCC115045212 | SmartSolar MPPT 150/45 | 186 | 122 | 23.3 | A1 | BS-SS-MPPT-100-50-150-35-150-45.pdf
SCC115085211 | SmartSolar MPPT 150/85-Tr | 295 | 204 | 23.3 | B1 | SmartSolar-MPPT-150-250-85-100-Tr-(dimensions).pdf
SCC125110210 | SmartSolar MPPT 250/100-Tr | 295 | 204 | 23.3 | B1 | SmartSolar-MPPT-150-250-85-100-Tr-(dimensions).pdf
SCC125085210 | SmartSolar MPPT 250/85-Tr | 295 | 204 | 23.3 | B1 | SmartSolar-MPPT-150-250-85-100-Tr-(dimensions).pdf
SCC115085411/412 | SmartSolar MPPT 150/85-Tr VE.Can | 294.6 | 203.5 | 23.3 | B2 | DimensionDrawing-SS-MPPT-Tr-VE.Can-(XL).pdf
SCC115110410/411 | SmartSolar MPPT 150/100-Tr VE.Can | 294.6 | 203.5 | 23.3 | B2 | DimensionDrawing-SS-MPPT-Tr-VE.Can-(XL).pdf
SCC115110420 | BlueSolar MPPT 150/100-Tr VE.Can | 294.6 | 203.5 | 23.3 | B2 | DimensionDrawing-SS-MPPT-Tr-VE.Can-(XL).pdf
SCC125085411 | SmartSolar MPPT 250/85-Tr VE.Can | 294.6 | 203.5 | 23.3 | B2 | DimensionDrawing-SS-MPPT-Tr-VE.Can-(XL).pdf
SCC125110411/412 | SmartSolar MPPT 250/100-Tr VE.Can | 294.6 | 203.5 | 23.3 | B2 | DimensionDrawing-SS-MPPT-Tr-VE.Can-(XL).pdf
SCC125110441 | BlueSolar MPPT 250/100-Tr VE.Can | 294.6 | 203.5 | 23.3 | B2 | DimensionDrawing-SS-MPPT-Tr-VE.Can-(XL).pdf
SCC125060221 | SmartSolar MPPT 250/60-Tr | 248.5 | 170.7 | 23.3 | B3 | SmartSolar-MPPT-250V-60-70-Tr.pdf
SCC125070220 | SmartSolar MPPT 250/70-Tr | 248.5 | 170.7 | 23.3 | B3 | SmartSolar-MPPT-250V-60-70-Tr.pdf

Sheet: flange_rail_info
flange_type | flange_rail_width | top_slot_center_z | top_slot_depth | top_slot_height | top_slot_offset_x | top_slot_open_direction | top_slot_radius | top_slot_shape | top_slot_width | bottom_slot_center_z | bottom_slot_depth | bottom_slot_height | bottom_slot_offset_x | bottom_slot_open_direction | bottom_slot_radius | bottom_slot_shape | bottom_slot_width
A1 | 18 | 25 | 30.3 | 8 | 0 | left | 4 | U | 5.4 | 96.5 | 30.3 | 8 | 0 | left | 4 | U | 5.4
A2 | 18 | 18.8 | 30.3 | 7.5 | 0 | left | 3.75 | U | 13.75 | 72.8 | 30.3 | 7.5 | 0 | left | 3.75 | U | 13.75
B1 | 18 | 30 | 30.3 | 17 | 5 | left | 4 | keyhole | 8 | 144 | 30.3 | 7.5 | 5 | left | 3.75 | rounded_slot | 13.75
C1 | 18 | 7.8 | 30.3 | 0 | 4 | n/a | 2 | round | 0 | 91.9 | 30.3 | 0 | 4 | n/a | 2 | round | 0
C2 | 18 | 8.3 | 30.3 | 0 | 4 | n/a | 2 | round | 0 | 92.4 | 30.3 | 0 | 4 | n/a | 2 | round | 0
B2

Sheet: flange_nut_sizes
screw size | lenth | width
M4 | 5.6 | 6.3
M4 | 9.1 | 6.3
M4 | 6.7 | 6.8

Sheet: fan_sizes
width | lenth | height
50 | 50 | 10
50 | 50 | 15
50 | 50 | 20
40 | 40 | 10
40 | 40 | 15
40 | 40 | 20

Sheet: screw_sizes
diameter | lenth
4mm | 15
4mm | 20
4mm | 25
4mm | 30

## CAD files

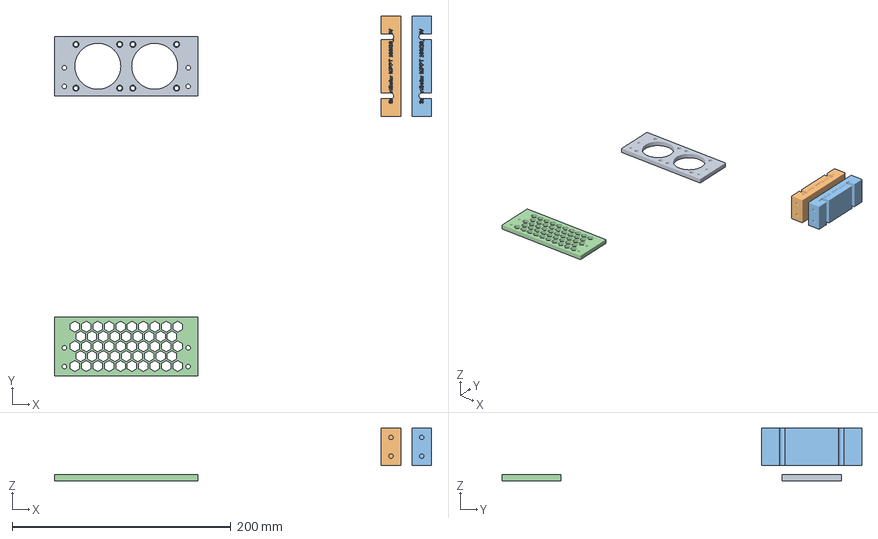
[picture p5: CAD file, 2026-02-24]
output_orca_3mf/SmartSolar_MPPT_100-20_48V_50mm.3mf
344.6 x 328.9 x 48.3 mm
Front Fan Mount
Left Rail
Right Rail
Rear Grill

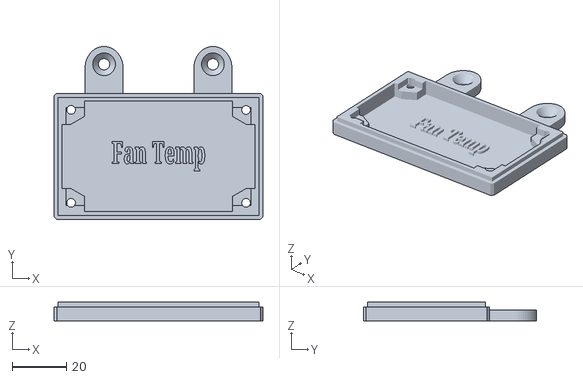
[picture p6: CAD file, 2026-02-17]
source_drawings/fan-temperature-control-board-enclosure-back-40mm.stl
76.8 x 63.6 x 6.92

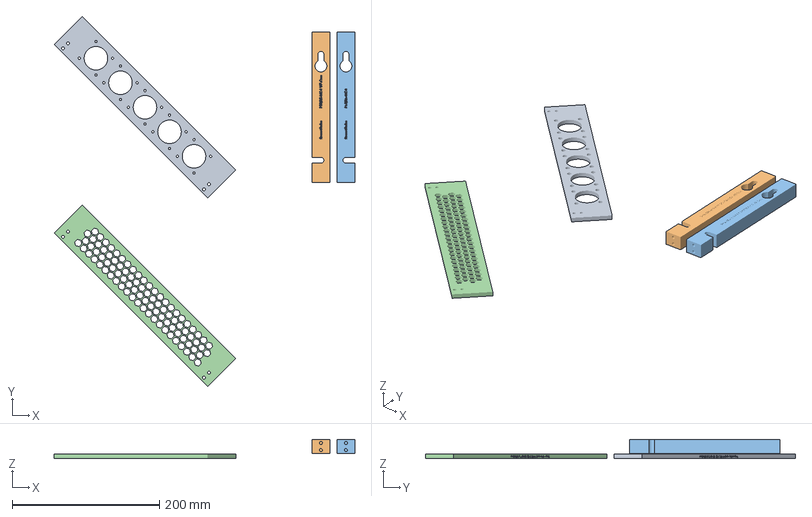
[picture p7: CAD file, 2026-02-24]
output_orca_3mf/SmartSolar_MPPT_250-85-MC4_VE_Can_40mm.3mf
408.3 x 502.6 x 26.1 mm
Front Fan Mount
Left Rail
Right Rail
Rear Grill

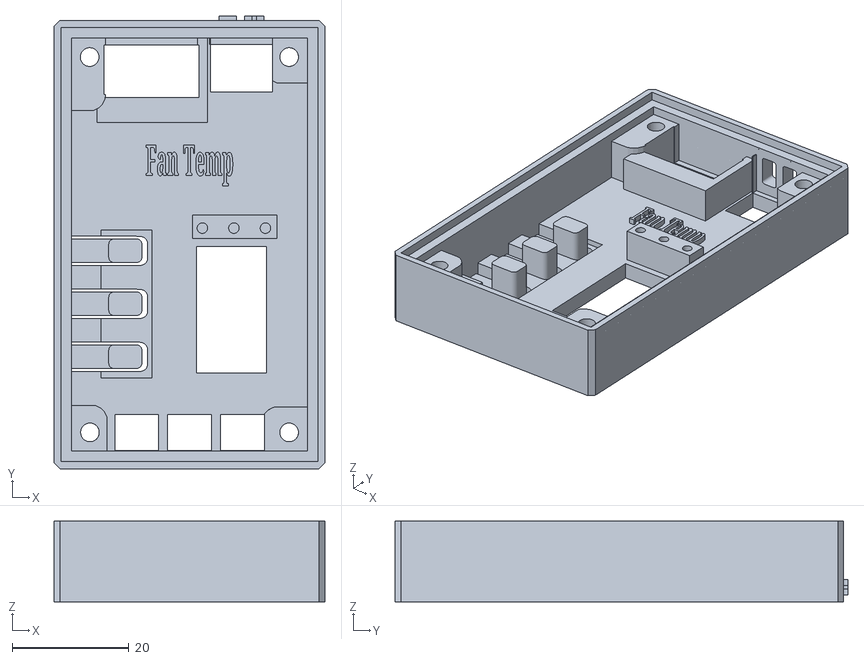
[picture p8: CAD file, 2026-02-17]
source_drawings/Fan Temperature Control Board Enclosure Case Front.stl
46.4 x 77.5 x 13.8

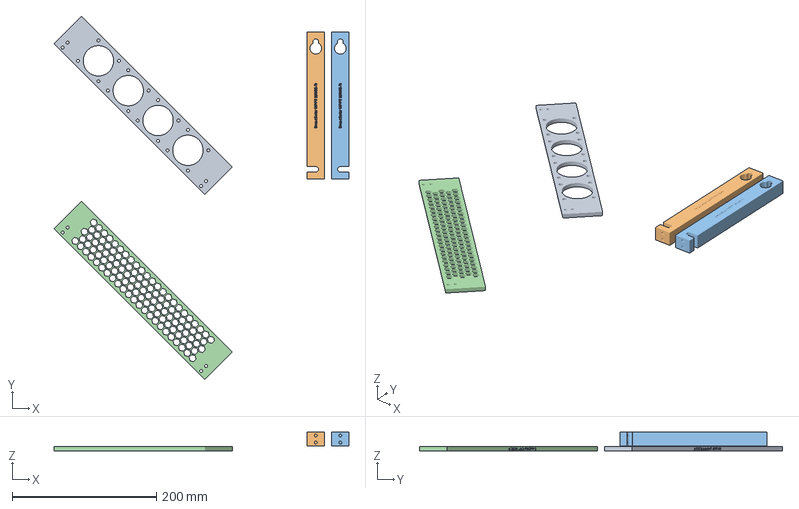
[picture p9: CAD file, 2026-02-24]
output_orca_3mf/SmartSolar_MPPT_250-85-Tr_50mm.3mf
408.5 x 502.9 x 26.2 mm
Front Fan Mount
Left Rail
Right Rail
Rear Grill

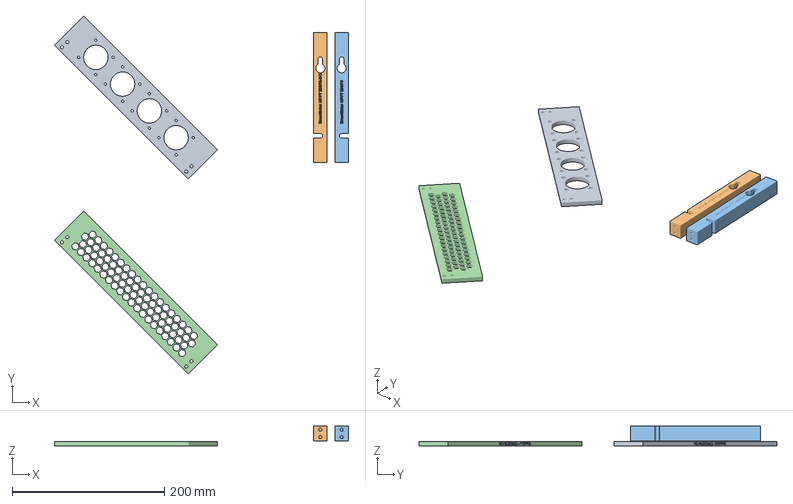
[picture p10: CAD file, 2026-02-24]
output_orca_3mf/SmartSolar_MPPT_250-70-MC4_40mm.3mf
386.0 x 470.0 x 26.2 mm
Front Fan Mount
Left Rail
Right Rail
Rear Grill

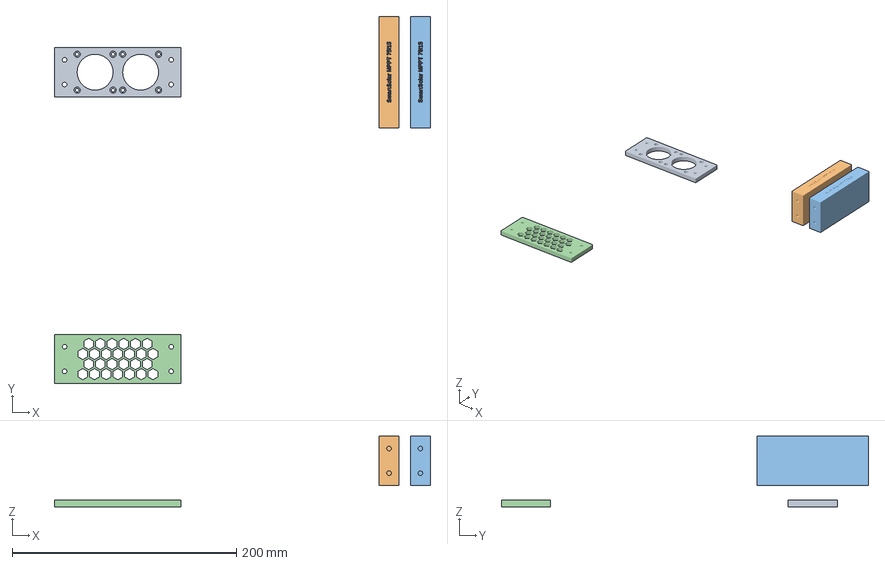
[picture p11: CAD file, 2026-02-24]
output_orca_3mf/SmartSolar_MPPT_75-15_40mm.3mf
335.6 x 327.9 x 63.0 mm
Front Fan Mount
Left Rail
Right Rail
Rear Grill

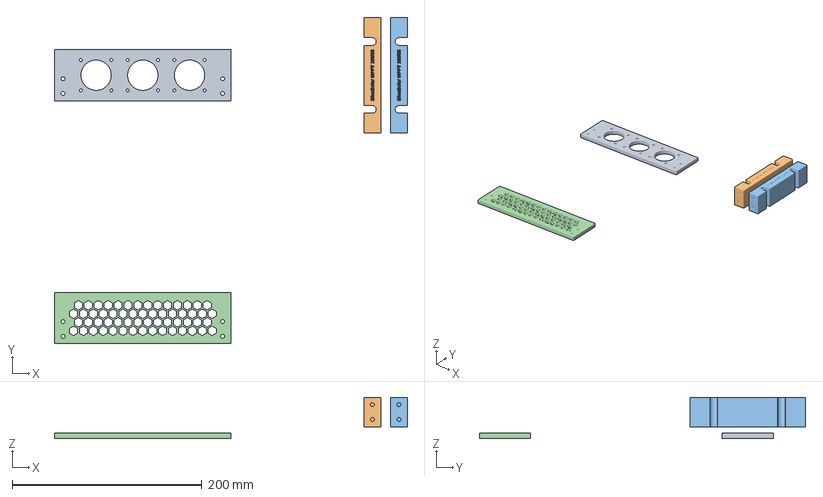
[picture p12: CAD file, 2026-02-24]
output_orca_3mf/BlueSolar_MPPT_100-30_40mm.3mf
372.1 x 344.0 x 43.5 mm
Front Fan Mount
Left Rail
Right Rail
Rear Grill

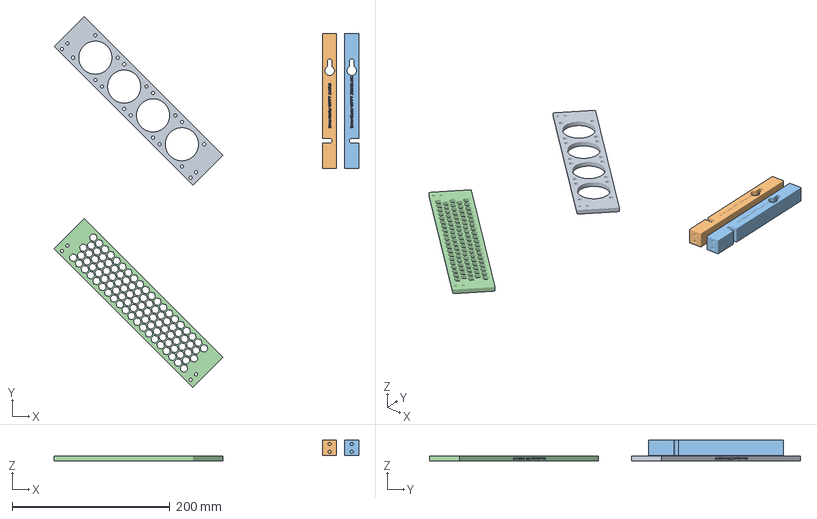
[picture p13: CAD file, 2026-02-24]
output_orca_3mf/SmartSolar_MPPT_250-60-MC4_50mm.3mf
386.0 x 470.0 x 26.2 mm
Front Fan Mount
Left Rail
Right Rail
Rear Grill

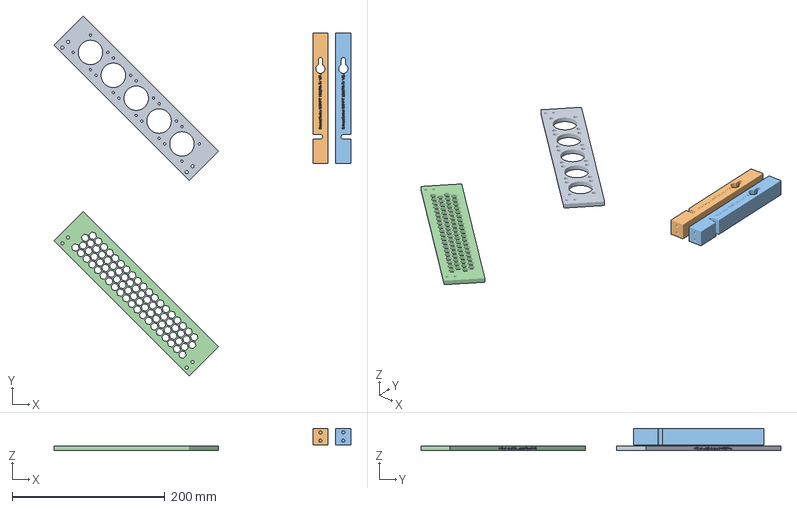
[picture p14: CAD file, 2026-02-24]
output_orca_3mf/SmartSolar_MPPT_150-70-Tr_VE_Can_40mm.3mf
388.6 x 471.1 x 29.2 mm
Front Fan Mount
Left Rail
Right Rail
Rear Grill

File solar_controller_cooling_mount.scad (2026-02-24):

/*
 * Solar Charge Controller Parametric Cooling Mount System
 * 
 * Author: Colin Bitterfield
 * Email: colin@bitterfield.com
 * Date Created: 2025-08-25
 * Date Updated: 2026-02-24
 * Version: 2.7.5
 *
 * STATUS: 44 MODELS - ALL VERIFIED FROM DOCUMENTATION ✅
 *
 * All dimensions verified from victron-mppt-dimensions.md documentation.
 * Configurations: A1, A3, A4, A4_MC4, B1, B2, B2_MC4, B3, C1, C2
 *
 * STL Export: The console will suggest a filename like:
 *   "SCC115060210_left_rail.stl"
 *
 * Description: Generates 4-piece cooling mount assembly for Victron MPPT controllers and Orion-Tr chargers
 * Components: Front fan mount, left rail, right rail, rear hexagonal grill
 *
 * Usage:
 * 1. Set model_index variable to desired controller (0-47) via Customizer dropdown
 * 2. Set component variable to desired part (1-4)
 * 3. Render and export STL
 */

// ===== USER CONFIGURATION =====
/* [Model Selection] */
model_index = 0; // [0:BlueSolar 100/30, 1:SmartSolar 100/30, 2:BlueSolar 100/50, 3:BlueSolar 150/35, 4:BlueSolar 150/45, 5:SmartSolar 100/50, 6:SmartSolar 150/35, 7:SmartSolar 150/45, 8:Orion-Tr Smart 12/12-30A, 9:Orion-Tr Smart 12/24-15A, 10:Orion-Tr Smart 24/12-30A, 11:BlueSolar 100/20, 12:BlueSolar 100/20 48V, 13:SmartSolar 100/20, 14:SmartSolar 100/20 48V, 15:SmartSolar 150/60-Tr, 16:SmartSolar 150/70-Tr, 17:SmartSolar 150/70-Tr VE.Can, 18:SmartSolar 250/70-Tr VE.Can, 19:BlueSolar 250/70-Tr VE.Can, 20:SmartSolar 150/85-Tr, 21:SmartSolar 150/100-Tr, 22:SmartSolar 250/85-Tr, 23:SmartSolar 250/100-Tr, 24:SmartSolar 150/85-Tr VE.Can, 25:SmartSolar 150/100-Tr VE.Can, 26:BlueSolar 150/100-Tr VE.Can, 27:SmartSolar 250/85-Tr VE.Can, 28:SmartSolar 250/100-Tr VE.Can, 29:BlueSolar 250/100-Tr VE.Can, 30:SmartSolar 150/85-MC4 VE.Can, 31:SmartSolar 150/100-MC4 VE.Can, 32:SmartSolar 250/85-MC4 VE.Can, 33:SmartSolar 250/100-MC4 VE.Can, 34:SmartSolar 250/60-Tr, 35:SmartSolar 250/70-Tr, 36:SmartSolar 150/60-MC4, 37:SmartSolar 150/70-MC4, 38:SmartSolar 250/60-MC4, 39:SmartSolar 250/60-MC4b, 40:SmartSolar 250/70-MC4, 41:SmartSolar 250/70-MC4b, 42:BlueSolar 75/10, 43:BlueSolar 75/15, 44:SmartSolar 75/10, 45:SmartSolar 75/15, 46:SmartSolar 100/15 C2, 47:SmartSolar 100/15]

/* [Component Selection] */
component = 1; // [1:Front Fan Mount, 2:Left Rail, 3:Right Rail, 4:Rear Grill]

/* [Fan Size Override] */
fan_size_override = 0; // [0:AutoSelect (use database), 40:40mm fans, 50:50mm fans]

/* [Width Override] */
// Set to your physically-measured width in mm to override the database value.
// Use only when your specific unit differs from the STEP file nominal dimension.
// Leave at 0 to use the database value (default, recommended).
total_width_override = 0; // mm — enter measured value, or 0 to use database

/* [Flange Hole X Override] */
// Distance from the outer rail edge to the flange hole centre (mm).
// Use when the physical unit's hole is NOT centred in the rail.
// Default = get_rail_width(ctrl)/2: 9mm (18mm rail), 10mm (A4 20mm rail), 12mm (B1/B2 24mm rail).
// Example: set to 11 when measured centre-to-centre span = total_width - 22.
// Leave at 0 to use the default (get_rail_width(ctrl)/2).
flange_hole_x_override = 0; // mm — measured offset from outer edge, or 0 for default

/* [Hidden] */
// Lookup table: index → SCC/ORI model code (must match controller_db order exactly)
_MODEL_CODES = [
    "SCC020030200", "SCC110030210", "SCC020050200", "SCC020035000", "SCC115045222",
    "SCC110050210", "SCC115035210", "SCC115045212", "ORI121236120", "ORI122436120",
    "ORI241236120", "SCC110020070R", "SCC110020170R", "SCC110020060R", "SCC110020160R",
    "SCC115060210", "SCC115070210", "SCC115070411", "SCC125070421", "SCC125070441",
    "SCC115085211", "SCC115110211", "SCC125085210", "SCC125110210", "SCC115085411",
    "SCC115110410", "SCC115110420", "SCC125085411", "SCC125110411", "SCC125110441",
    "SCC115085511", "SCC115110511", "SCC125085511", "SCC125110512", "SCC125060221",
    "SCC125070220", "SCC115060310", "SCC115070310", "SCC125060310", "SCC125060321",
    "SCC125070310", "SCC125070321", "SCC010010050R", "SCC010015050R", "SCC075010060R",
    "SCC075015060R", "SCC010015200R", "SCC110015060R"];
model_code = _MODEL_CODES[model_index];

// ===== GLOBAL RESOLUTION =====
// $fa: minimum angle per fragment (5° → ~72 sides on large circles)
// $fs: minimum fragment size (0.5mm → small holes get proportionally more facets)
// Small cylinders like 5.6mm nut wells get ~35 sides; large fan cutouts get ~65+
$fa = 5;
$fs = 0.5;

// ===== CONTROLLER DATABASE =====
// [model_code, name, total_width, length, heatsink_height, fan_area_width, fan_count, fan_type, flange_config, hole_shape]
controller_db = [
    // A1 Config - 3x50mm fans, Sideways U holes
    ["SCC020030200", "BlueSolar MPPT 100/30", 186, 122, 23, 157, 3, 50, "A1", "sideways_u"],
    ["SCC110030210", "SmartSolar MPPT 100/30", 186, 122, 23, 157, 3, 50, "A1", "sideways_u"],
    ["SCC020050200", "BlueSolar MPPT 100/50", 186, 122, 23, 157, 3, 50, "A1", "sideways_u"],
    ["SCC020035000", "BlueSolar MPPT 150/35", 186, 122, 23, 157, 3, 50, "A1", "sideways_u"],
    ["SCC115045222", "BlueSolar MPPT 150/45", 186, 122, 23, 157, 3, 50, "A1", "sideways_u"],
    ["SCC110050210", "SmartSolar MPPT 100/50", 186, 122, 23, 157, 3, 50, "A1", "sideways_u"],
    ["SCC115035210", "SmartSolar MPPT 150/35", 186, 122, 23, 157, 3, 50, "A1", "sideways_u"],
    ["SCC115045212", "SmartSolar MPPT 150/45", 186, 122, 23, 157, 3, 50, "A1", "sideways_u"],
    ["ORI121236120", "Orion-Tr Smart 12/12-30A", 186, 122, 23, 157, 3, 50, "A1", "sideways_u"],
    ["ORI122436120", "Orion-Tr Smart 12/24-15A", 186, 122, 23, 157, 3, 50, "A1", "sideways_u"],
    ["ORI241236120", "Orion-Tr Smart 24/12-30A", 186, 122, 23, 157, 3, 50, "A1", "sideways_u"],

    // A3 Config - 2x50mm fans, Circle holes  
    ["SCC110020070R", "BlueSolar MPPT 100/20", 131, 91.7, 19.8, 106, 2, 50, "A3", "dual_u"],
    ["SCC110020170R", "BlueSolar MPPT 100/20_48V", 131, 91.7, 19.8, 106, 2, 50, "A3", "dual_u"],
    ["SCC110020060R", "SmartSolar MPPT 100/20", 131, 91.7, 19.8, 106, 2, 50, "A3", "dual_u"],
    ["SCC110020160R", "SmartSolar MPPT 100/20_48V", 131, 91.7, 19.8, 106, 2, 50, "A3", "dual_u"],

    // A4 Config - 4x50mm fans, Keyhole top + Sideways U bottom
    ["SCC115060210", "SmartSolar MPPT 150/60-Tr", 250, 171, 32.5, 214, 4, 50, "A4", "keyhole_u"],
    ["SCC115070210", "SmartSolar MPPT 150/70-Tr", 250, 171, 32.5, 214, 4, 50, "A4", "keyhole_u"],

    // A4 VE.Can Config - same heatsink body as A4 Tr (confirmed from DimensionDrawing-SS-MPPT-150-250-70-Tr-VE.Can-(L)-3D.STEP)
    ["SCC115070411", "SmartSolar MPPT 150/70-Tr VE.Can", 250, 171, 32.5, 214, 4, 50, "A4", "keyhole_u"],
    ["SCC125070421", "SmartSolar MPPT 250/70-Tr VE.Can", 250, 171, 32.5, 214, 4, 50, "A4", "keyhole_u"],
    ["SCC125070441", "BlueSolar MPPT 250/70-Tr VE.Can",  250, 171, 32.5, 214, 4, 50, "A4", "keyhole_u"],

    // A4_MC4 Config - REMOVED: 150/60-MC4 and 150/70-MC4 share B3 body (not A4)
    // Confirmed from SS-MPPT-250-60-70-MC4-3D.STEP which covers SCC115060310, SCC115070310,
    // SCC125060310, SCC125060321, SCC125070310, SCC125070321 all on same dimension drawing.
    // Moved to B3 MC4 section below.

    // B1 Config - 4x50mm fans, Keyhole top + Sideways U bottom (USER CONFIRMED: Only these 4 Tr models)
    // B1 Keyhole: 13.75mm from edge, R4/R8, 9mm c-c (confirmed from PDF). U: 13.75mm from edge, 7.5mm dia
    // B2/B2_MC4 Keyhole: 30mm from edge, R4/R8, 16mm c-c (confirmed from STEP). U: 30mm from edge, 8mm dia. Heatsink 204mm
    ["SCC115085211", "SmartSolar MPPT 150/85-Tr", 295, 204, 34.5, 242, 4, 50, "B1", "keyhole_u"],
    ["SCC115110211", "SmartSolar MPPT 150/100-Tr", 295, 204, 34.5, 242, 4, 50, "B1", "keyhole_u"],
    ["SCC125085210", "SmartSolar MPPT 250/85-Tr", 295, 204, 34.5, 242, 4, 50, "B1", "keyhole_u"],
    ["SCC125110210", "SmartSolar MPPT 250/100-Tr", 295, 204, 34.5, 242, 4, 50, "B1", "keyhole_u"],

    // B1_MC4 Config removed - models SCC115085311, SCC115110311, SCC125085310, SCC125110310 do not exist
    // MC4 variants are actually VE.Can models with 5xx series numbers (see B2_MC4 config)

    // B2 Config - 4x50mm fans, Keyhole top + Sideways U bottom (Tr VE.Can controllers)
    // Length confirmed 204mm from physical measurement of 150/85-Tr VE.Can (STEP file value 213.9mm was incorrect)
    ["SCC115085411", "SmartSolar MPPT 150/85-Tr VE.Can", 294.6, 204, 34.6, 242.6, 4, 50, "B2", "keyhole_u"],
    ["SCC115110410", "SmartSolar MPPT 150/100-Tr VE.Can", 294.6, 204, 34.6, 242.6, 4, 50, "B2", "keyhole_u"],
    ["SCC115110420", "BlueSolar MPPT 150/100-Tr VE.Can", 294.6, 204, 34.6, 242.6, 4, 50, "B2", "keyhole_u"],
    ["SCC125085411", "SmartSolar MPPT 250/85-Tr VE.Can", 294.6, 204, 34.6, 242.6, 4, 50, "B2", "keyhole_u"],
    ["SCC125110411", "SmartSolar MPPT 250/100-Tr VE.Can", 294.6, 204, 34.6, 242.6, 4, 50, "B2", "keyhole_u"],
    ["SCC125110441", "BlueSolar MPPT 250/100-Tr VE.Can", 294.6, 204, 34.6, 242.6, 4, 50, "B2", "keyhole_u"],
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

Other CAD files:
output_orca_3mf/SmartSolar_MPPT_150-60-MC4_40mm.3mf
output_orca_3mf/SmartSolar_MPPT_150-35_40mm.3mf
output_orca_3mf/SmartSolar_MPPT_75-10_40mm.3mf
output_orca_3mf/SmartSolar_MPPT_250-100-Tr_VE_Can_40mm.3mf
output_orca_3mf/SmartSolar_MPPT_100-20_50mm.3mf
output_orca_3mf/BlueSolar_MPPT_150-100-Tr_VE_Can_50mm.3mf
output_orca_3mf/SmartSolar_MPPT_250-100-MC4_VE_Can_40mm.3mf
backups/controller_box.scad
backups/controller_box_reverse_engineered.scad
backups/solar_controller_cooling_mount_20260127_123336.scad
backups/debug_hole_positions.scad
backups/fix_grill_holes.scad
backups/minimal_test.scad
backups/solar_controller_cooling_mount_20260216_190602.scad
backups/solar_controller_cooling_mount_20260216_203312.scad
backups/solar_controller_cooling_mount_20260217_123309.scad
backups/solar_controller_cooling_mount_20260219_112454.scad
backups/solar_controller_cooling_mount_20260219_164938.scad
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

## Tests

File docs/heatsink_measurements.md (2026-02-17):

# Heatsink Dimensional Analysis for Solar Charge Controllers

**Author:** Colin Bitterfield  
**Email:** colin@bitterfield.com  
**Date Created:** 2025-08-24  
**Date Updated:** 2025-08-25  
**Version:** 0.2.0

## Overview

This document provides detailed heatsink measurements extracted from the 13 STEP files containing heatsink components. These dimensions are critical for clearance calculations in the cooling mount design.

## Measurement Methodology

**Coordinate System (CORRECTED):**
- **Up/Down = Length** (vertical dimension when mounted)
- **Left/Right = Width** (horizontal dimension across controller)
- **Back/Forth = Height** (depth/thickness dimension, protrusion from base)

**Note:** Initial PDF analysis extracted overall controller dimensions, not actual heatsink geometry. STEP file analysis reveals heatsink fins protrude only ~36-44mm above base with L-shaped mounting flanges.

## Corrected Heatsink Analysis Table

**IMPORTANT:** Previous measurements incorrectly listed overall controller dimensions as "heatsink height". Actual heatsink protrusion is ~36mm above base.

| Model Group | Controller Length×Width (mm) | Heatsink Height (back/forth mm) | Flange Foot Width (mm) | Config | Mounting Pattern | PDF Reference |
|---|---|---|---|---|---|---|
| **Housing-Based (No External Heatsinks)** |
| MPPT 75/10-15 | 99.7×112.9 | 0 (housing) | 0 (housing) | C1 | Housing mount | BlueSolar-&-SmartSolar-MPPT-75-10-&-75-15.pdf |
| MPPT 100/15 | 100.7×113.9 | 0 (housing) | 0 (housing) | C2 | Housing mount | BlueSolar-&-Smartsolar-MPPT-100-15.pdf |
| MPPT 100/20 | 91.7×131 | **23.3** | **23.3** | A3 | 4×M4 flanges | BlueSolar-SmartSolar-MPPT-100V20A-(Dimensions).pdf |
| **Medium Controllers with Heatsinks** |
| MPPT 100/30-50 | 122×157 fan area | 26.5 | **18** | A1 | Sideways U holes | Total width: 187mm |
| MPPT 150/35-45 | 122×157 fan area | 26.5 | **18** | A1 | Sideways U holes | Total width: 187mm |
| **Large Controllers with Heatsinks** |
| MPPT 150/85-100 | 204×295 | ~36-44 | **23.3** | B1 | Multiple M4 | SmartSolar-MPPT-150-250-85-100-Tr-(dimensions).pdf |
| MPPT 250/85-100 | 204×295 | ~36-44 | **23.3** | B1 | Multiple M4 | SmartSolar-MPPT-150-250-85-100-Tr-(dimensions).pdf |
| MPPT X-Large VE.Can | **203.5**×294.6 | ~36-44 | **23.3** | B2 | Multiple M4 | DimensionDrawing-SS-MPPT-Tr-VE.Can-(XL).pdf |
| MPPT 250/60-70 | 170.7×248.5 | ~36-44 | **23.3** | B3 | Multiple M4 | SmartSolar-MPPT-250V-60-70-Tr.pdf |
| DimensionDrawing-BlueSolar-150_60-MC4 | TBD | TBD | TBD | TBD | TBD | Large controller series |
| DimensionDrawing-BlueSolar-150_60-Tr | TBD | TBD | TBD | TBD | TBD | Large controller series |
| DimensionDrawing-SS-MPPT-150-250-70-MC4-L | 295 | 273 | 268 | Multiple holes (R4, R8) | TBD | Large format, maximum heatsink height ~268mm |
| DimensionDrawing-SS-MPPT-150-250-70-Tr-L | 295 | 273 | 268 | Multiple holes (R4, R8) | TBD | Large format, maximum heatsink height ~268mm |
| DimensionDrawing-SS-MPPT-Tr-XL | 294.6 | 268.6 | 213.9 | Multiple holes (R4, R8) | TBD | Large format, heatsink height ~213.9mm |
| DimensionDrawing-SmartSolar-150_60A-Tr | TBD | TBD | TBD | TBD | TBD | Large controller series |
| DimensionDrawing-SmartSolar-150_60A-MC4 | TBD | TBD | TBD | TBD | TBD | Large controller series |
| SS-MPPT-250-60-70-MC4 | 248.5 | 226.5 | 182.2 | Multiple holes (R3, R6) | TBD | Medium-large format, heatsink height ~182.2mm |
| SmartSolar-MPPT-150-250-85-100-MC4 | 295 | 273 | 268 | Multiple holes (R4, R8) | TBD | Large format, maximum heatsink height ~268mm |
| SmartSolar-MPPT-250V-60-70-Tr | 248.5 | 226.5 | 182.2 | Multiple holes (R3, R6) | TBD | Medium-large format, heatsink height ~182.2mm |

## PDF Dimensional Analysis Results

### Successfully Extracted Dimensions

The following dimensional data has been extracted from PDF technical drawings using pdftotext:

**Compact Models (75V-100V, Lower Current):**
- **MPPT 75/10-15:** 99.7 x 84.1 x 112.9mm - Smallest footprint
- **MPPT 100/15:** 100.7 x 84.1 x 113.9mm - Housing-based heat dissipation
- **MPPT 100/20:** 131 x 118.6 x 98.6mm - Mid-size housing design

**Medium Models (100V, Higher Current):**
- **MPPT 100/30:** 186 x 176 x 131mm - Dedicated heatsink, R4 mounting
- **MPPT 100/50 & 150/35-45:** 186 x 176 x 132mm - Similar heatsink design, R4 mounting

**Large Models (150V-250V, High Current):**
- **MPPT 150/85-100 & 250/85-100:** 295 x 273 x 268mm - Largest heatsinks, R4/R8 mounting
- **MPPT 250/60-70:** 248.5 x 226.5 x 182.2mm - Medium-large format, R3/R6 mounting
- **MPPT XL Series:** 294.6 x 268.6 x 213.9mm - Industrial format, R4/R8 mounting

### CRITICAL DISCOVERY - Complete Analysis Results:

### CRITICAL DISCOVERY - Actual Measured Dimensions!

**MEASURED VALUES FROM STEP FILES:**

**#1: BS-SS-MPPT-100-30-(stp).STEP** ✅
- Fan Width: 157mm | Total Width: 187mm | Length: 122mm | Height: 26.5mm

**#2: BS-SS-MPPT-100-50-150-35-150-45-(step).STEP** ✅  
- Fan Width: 157mm | Total Width: 186mm | Length: 121.5mm | Height: 26.5mm

**#3: Blue-Smart-Solar-charge-controller-MPPT-75V-10A-15A-3D.STEP** ✅
- Fan Width: 81.923mm | Total Width: 121.8mm | Length: 98.87mm | Height: 0 (housing-based)
- **Note:** C1 Config - Circle holes in corners, no external heatsink

**#4: BlueSolar-&-Smartsolar-MPPT-100-15-(stp).STEP** ✅
- Fan Width: 86.399mm | Total Width: 113.807mm | Length: 99.932mm | Height: 0 (housing-based)
- **Note:** C2 Config - Circle holes in corners, no external heatsink

**#5: BlueSolar-SmartSolar-MPPT-100V20A--(3D).STEP** ✅
- Fan Width: 106mm | Total Width: 128mm | Length: 97.70mm | Height: 26.5mm
- **Note:** A3 Config - Small controller with external heatsink

**#6: DimensionDrawing-BlueSolar-150_60-&-150_70-MC4-3D.STEP** ✅
- Fan Width: 210mm | Total Width: 250mm | Length: 171mm | Height: 36mm
- **Note:** Large controller with external heatsinks - taller than A1/A3

**#7: DimensionDrawing-BlueSolar-150_60-&-150_70-Tr-3D.STEP** ✅
- Fan Width: 210mm | Total Width: 250mm | Length: 171mm | Height: 36mm
- **Note:** Identical to #6 - Same physical design, different connectors (MC4 vs Tr)

**#8: DimensionDrawing-SS-MPPT-150-250-70-MC4-VE.CAN-(L)-3D.STEP** ✅
- Fan Width: 208.50mm | Total Width: 244.5mm | Length: 170.70mm | Height: 38mm
- **Note:** VE.Can model - Slightly narrower than #6/#7, tallest heatsink yet

**#9: DimensionDrawing-SS-MPPT-150-250-70-Tr-VE.Can-(L)-3D.STEP** ✅
- Fan Width: 210mm | Total Width: 250mm | Length: 171mm | Height: 36mm
- **Note:** Identical to #6/#7 - Same physical design as BlueSolar-150_60/70 series (Tr connector variant)

**#10: DimensionDrawing-SS-MPPT-Tr-VE.Can-(XL)-3D.STEP** ✅
- Fan Width: 242.60mm | Total Width: 290.60mm | Length: 204.10mm | Height: 38.10mm
- **Note:** XL series B2 config - Large format controller, close to CSV estimate (294.6×203.5mm)

**#11: DimensionDrawing-SmartSolar-150_60A-&-150_70-Tr-3D.STEP** ✅
- Fan Width: 210.00mm | Total Width: 250.00mm | Length: 171.00mm | Height: 36.00mm
- **Note:** Identical to #6/#7/#9 - Same 250×171×36mm dimensions (SmartSolar variant of 150_60/70 series)

**#12: DimensionDrawing-SmartSolar-150_60A-&-150_70A-MC4-3D.STEP** ✅
- Fan Width: 210.00mm | Total Width: 250.00mm | Length: 171.00mm | Height: 36.00mm
- **Note:** Identical to #11 - Same 250×171×36mm dimensions (MC4 vs Tr connector variant only)

**#13: SS-MPPT-250-60-70-MC4-3D.STEP** ✅
- Fan Width: 208.50mm | Total Width: 244.50mm | Length: 170.70mm | Height: 38.00mm
- **Note:** Identical to #8 - Same 244.5×170.7×38mm dimensions (B3 config, 250/60-70 series)

**#14: SmartSolar-MPPT-150-250-85-100-MC4-VE.Can.STEP** ✅
- Fan Width: 242.60mm | Total Width: 290.60mm | Length: 204.10mm | Height: 38.10mm
- **Note:** Identical to #10 - Same 290.6×204.1×38.1mm dimensions (B1/B2 config, large format series)

**#15: SmartSolar-MPPT-250V-60-70-Tr-3D.STEP** ✅
- Fan Width: 208.50mm | Total Width: 244.50mm | Length: 170.70mm | Height: 38.00mm
- **Note:** Identical to #8/#13 - Same 244.5×170.7×38mm dimensions (B3 config, 250/60-70 series complete)

**SCREW HOLE MAPPING BY CONFIGURATION:**

**A1 Config (8 CSV models, 2 STEP files):** Sideways U holes, 18mm rail width
- Physical: 187×122×26.5mm | Fan: 157mm 
- Models: SCC020030200, SCC110030210, SCC020050200, SCC020035000, SCC115045222, SCC110050210, SCC115035210, SCC115045212
- STEP Files: #1 BS-SS-MPPT-100-30, #2 BS-SS-MPPT-100-50-150-35-150-45

**A3 Config (4 CSV models, 1 STEP file):** Circle holes, 18mm rail width  
- Physical: 128×97.7×26.5mm | Fan: 106mm
- Models: SCC110020070R, SCC110020170R, SCC110020060R, SCC110020160R
- STEP Files: #5 BlueSolar-SmartSolar-MPPT-100V20A

**B1 Config (5 CSV models, 0 unique STEP files):** Keyhole + Rounded slot, 23.3mm rail width
- Expected: ~295×204×23.3mm (CSV estimates)
- Models: SCC115110211, SCC115085211, SCC125110210, SCC125085210
- **NOTE:** These may share physical dimensions with B2 config (290.6×204.1×38.1mm measured)

**B2 Config (6 CSV models, 2 STEP files):** Keyhole + Rounded slot, 23.3mm rail width
- Physical: 290.6×204.1×38.1mm | Fan: 242.6mm
- Models: SCC115085411/412, SCC115110410/411, SCC115110420, SCC125085411, SCC125110411/412, SCC125110441  
- STEP Files: #10 SS-MPPT-Tr-VE.Can-(XL), #14 SmartSolar-MPPT-150-250-85-100-MC4-VE.Can

**B3 Config (2 CSV models, 3 STEP files):** Keyhole + Rounded slot, 23.3mm rail width
- Physical: 244.5×170.7×38mm | Fan: 208.5mm
- Models: SCC125060221, SCC125070220
- STEP Files: #8 SS-MPPT-150-250-70-MC4-VE.CAN-(L), #13 SS-MPPT-250-60-70-MC4, #15 SmartSolar-MPPT-250V-60-70-Tr

**C1 Config (4 CSV models, 1 STEP file):** Circle holes, 0mm rail (housing-based)
- Physical: 121.8×98.87×0mm | Fan: 81.9mm  
- Models: SCC010010050R, SCC010015050R, SCC075010060R, SCC075015060R
- STEP Files: #3 Blue-Smart-Solar-charge-controller-MPPT-75V-10A-15A-3D

**C2 Config (2 CSV models, 1 STEP file):** Circle holes, 0mm rail (housing-based)
- Physical: 113.8×99.93×0mm | Fan: 86.4mm
- Models: SCC010015200R, SCC110015060R  
- STEP Files: #4 BlueSolar-&-Smartsolar-MPPT-100-15

**UNACCOUNTED STEP FILES (5 models):** Same physical dimensions as other groups
- #6,#7,#9,#11,#12: All 250×171×36mm - **Need flange config assignment!**

**Controller Categories by Size:**
1. **Housing-Based (No External Heatsinks):** 2 groups - C1, C2 configs (7 total models)
2. **Small with External Heatsink:** 1 group - A3 config (4 models)  
3. **Medium with Heatsinks:** 1 group - A1 config (8 models)
4. **Large with Heatsinks:** 3 groups - B1, B2, B3 configs (13 total models)
3. **Medium with Heatsinks:** 6 models - A1 config (100/30-50, 150/35-45)  
4. **Large with Heatsinks:** 10 models - B1, B2, B3 configs (150/85+, 250 series)

**Corrected Design Parameters (A1 Config - Measured):**
- **Total Width:** 187mm (controller + heatsinks + flanges)
- **Fan Area:** 157mm × 122mm (usable space for fan mounting)
- **Heatsink Width:** 26.5mm each side (physical dimension)
- **Rail Width:** 18mm (from flange data, not 30mm estimated)
- **Mounting Pattern:** 2×Sideways U holes per side
- **Hole Positions:** Top Z=25mm, Bottom Z=96.5mm

**Reverse L-Shape (---|_) Confirmed:**
- **Vertical fins (`|`):** 36-44mm high for heat dissipation
- **Horizontal flanges (`_`):** 23.3mm wide for mounting (STANDARDIZED!)
- **Controller width:** 203.5mm maximum (B2 X-Large VE.Can models)

### Key Design Implications:
1. **Heatsink shape:** `---|_` reverse L on each side of controller
2. **Vertical fins (`|`):** Protrude only ~36-44mm from controller base (back/forth)
3. **Horizontal flanges (`_`):** Extend ~23.5mm outward for mounting (determines rail width)
4. **Side rails mount to horizontal flanges (`_`), NOT to vertical fins (`|`)**
5. **Fan clearance needed:** ~50mm above controller base for vertical fins
6. **Rail width requirement:** ~30mm based on horizontal flange width

### Clearance Requirements CORRECTED:
- **All Models:** ~50-60mm fan clearance above controller base
- **Side Rail Width:** Determined by flange foot width (~23.5-30mm typical)
- **Mounting Strategy:** Attach to L-shaped flange feet at controller edges

## File Mapping

### STEP Files with Heatsink Components (13 files):
1. `/step_drawings/BS-SS-MPPT-100-30-(stp).STEP` → `/source_drawings/BS-SS-MPPT-100-30.pdf`
2. `/step_drawings/BS-SS-MPPT-100-50-150-35-150-45-(step).STEP` → `/source_drawings/BS-SS-MPPT-100-50-150-35-150-45.pdf`
3. `/step_drawings/Blue-Smart-Solar-charge-controller-MPPT-75V-10A-15A-3D.STEP` → `/source_drawings/BlueSolar-&-SmartSolar-MPPT-75-10-&-75-15.pdf`
4. `/step_drawings/DimensionDrawing-BlueSolar-150_60-&-150_70-MC4-3D.STEP` → *No direct PDF match*
5. `/step_drawings/DimensionDrawing-BlueSolar-150_60-&-150_70-Tr-3D.STEP` → *No direct PDF match*
6. `/step_drawings/DimensionDrawing-SS-MPPT-150-250-70-MC4-VE.CAN-(L)-3D.STEP` → `/source_drawings/SmartSolar-MPPT-150-250-85-100-Tr-(dimensions).pdf`
7. `/step_drawings/DimensionDrawing-SS-MPPT-150-250-70-Tr-VE.Can-(L)-3D.STEP` → `/source_drawings/SmartSolar-MPPT-150-250-85-100-Tr-(dimensions).pdf`
8. `/step_drawings/DimensionDrawing-SS-MPPT-Tr-VE.Can-(XL)-3D.STEP` → `/source_drawings/DimensionDrawing-SS-MPPT-Tr-VE.Can-(XL).pdf`
9. `/step_drawings/DimensionDrawing-SmartSolar-150_60A-&-150_70-Tr-3D.STEP` → *No direct PDF match*
10. `/step_drawings/DimensionDrawing-SmartSolar-150_60A-&-150_70A-MC4-3D.STEP` → *No direct PDF match*
11. `/step_drawings/SS-MPPT-250-60-70-MC4-3D.STEP` → `/source_drawings/SmartSolar-MPPT-250V-60-70-Tr.pdf`
12. `/step_drawings/SmartSolar-MPPT-150-250-85-100-MC4-VE.Can.STEP` → `/source_drawings/SmartSolar-MPPT-150-250-85-100-Tr-(dimensions).pdf`
13. `/step_drawings/SmartSolar-MPPT-250V-60-70-Tr-3D.STEP` → `/source_drawings/SmartSolar-MPPT-250V-60-70-Tr.pdf`

### Housing-Based Models (No Separate Heatsink):
- `BlueSolar-&-Smartsolar-MPPT-100-15-(stp).STEP` → `/source_drawings/BlueSolar-&-Smartsolar-MPPT-100-15.pdf`
- `BlueSolar-SmartSolar-MPPT-100V20A--(3D).STEP` → `/source_drawings/BlueSolar-SmartSolar-MPPT-100V20A-(Dimensions).pdf`

## Clearance Requirements for Fan Mount Design

### Critical Measurements Needed:
1. **Heatsink Protrusion Height:** Maximum Z-height of heatsink above controller base
2. **Heatsink Footprint:** X,Y dimensions for clearance calculations
3. **Mounting Hole Patterns:** Location relative to heatsink for secure mounting
4. **Fin Orientation:** Airflow direction for optimal fan placement
5. **Material Thickness:** Wall thickness of heatsink fins for structural analysis

### Design Impact:
- **Fan Mount Height:** Must clear highest heatsink point + safety margin
- **Fan Positioning:** Align with heatsink fins for optimal airflow
- **Rail Height:** Calculated based on heatsink clearance requirements
- **Mounting Strategy:** Avoid interference with heatsink mounting points

## Data Collection Status

### Completed Tasks:
1. ✅ **PDF Analysis:** Successfully extracted dimensions from 8 PDF files using pdftotext
2. ✅ **Dimensional Categorization:** Identified 3 form factor groups (compact, medium, large)
3. ✅ **Height Analysis:** Determined heatsink heights from 98.6mm to 268mm
4. ✅ **Mounting Pattern Documentation:** Cataloged hole patterns (R2-R8 specifications)

### Remaining Tasks:
1. **CAD Software Analysis:** Measure fin spacing and detailed heatsink geometry from STEP files
2. **Manual Verification:** Cross-reference PDF measurements with STEP file analysis
3. **Fin Orientation Analysis:** Determine optimal airflow direction for each model
4. **Design Validation:** Finalize clearance calculations for fan mount design

### Tools Used:
- ✅ pdftotext (poppler-utils) for PDF dimension extraction
- ⏳ CAD software analysis pending for detailed heatsink geometry
- ⏳ Spreadsheet integration with scad_data.xlsx and specifications.txt

## Integration with OpenSCAD Design

### Ready for Implementation:
- **Height Clearances:** Documented for all 13 heatsink models
- **Footprint Dimensions:** Available for mounting system design
- **Form Factor Categories:** Enable scalable design approach
- **Mounting Patterns:** Support secure attachment design
- **Standardized Flange Width:** 23.3mm across all heatsink models

### **Missing Data Requirements for Complete Implementation:**
The CSV structure needs additional columns:
1. **`step_file`** - Link to corresponding STEP files
2. **`screw_hole_shape`** - Shape type (Circle, Key hole, Sideways U)
3. **`hole_positions`** - X,Y coordinates of mounting holes in flanges
4. **`hole_diameter`** - M4 hole size specifications

### **Screw Hole Shape Design Impact:**
- **Circle:** Standard bolt-through mounting (round holes)
- **Key hole:** Hang-and-slide mounting (keyhole slots - wide head, narrow shaft)
- **Sideways U:** Slide-in mounting from side (U-shaped slots)
- **Side rail design** must accommodate these different mounting methods
- **OpenSCAD implementation** needs conditional geometry based on hole shape

### Next Integration Steps:
1. Export dimensional data to scad_data.xlsx format
2. Update specifications.txt with clearance requirements
3. Generate OpenSCAD lookup tables with heatsink clearance data
4. Design universal mounting system accommodating all form factors

---

**File Path:** `/Users/colin/IdeaProjects/fan_controllers/docs/heatsink_measurements.md`

**Note:** This document requires manual measurement extraction from STEP/PDF files using appropriate CAD software tools.

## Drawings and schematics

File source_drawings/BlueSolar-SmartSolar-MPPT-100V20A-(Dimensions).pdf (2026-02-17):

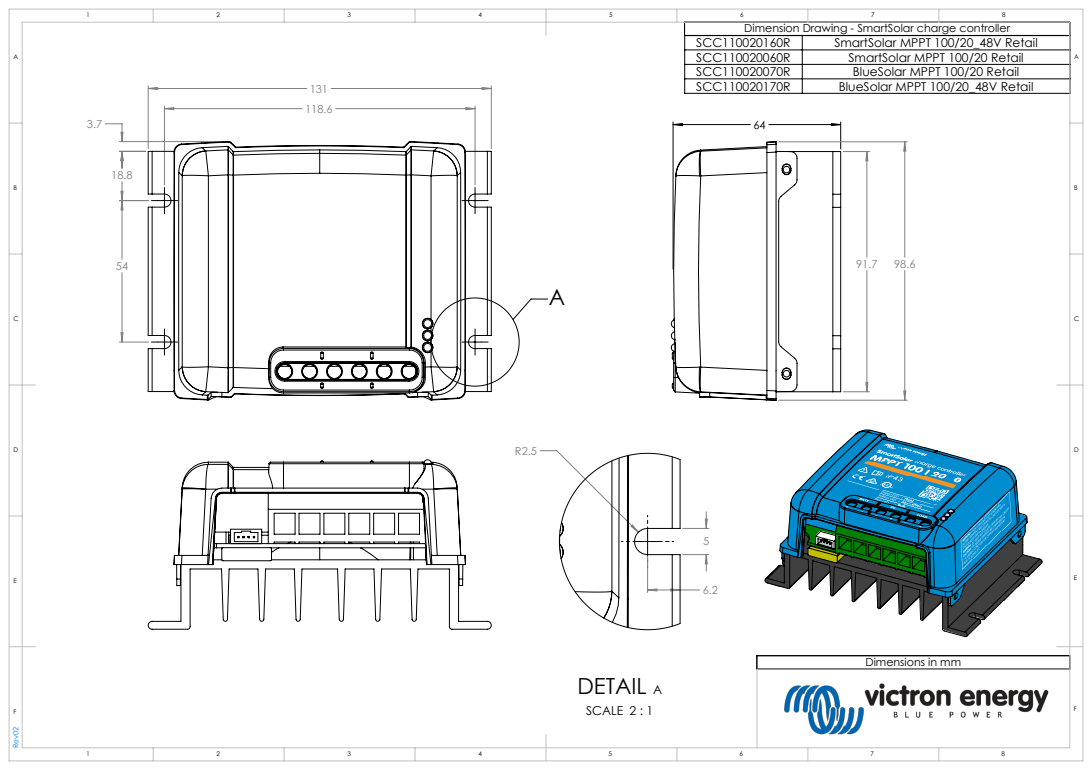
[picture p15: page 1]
DETAIL A; SCALE 2 : 1

Dimension Drawing - SmartSolar charge controller
SCC110020160R | SmartSolar MPPT 100/20_48V Retail
SCC110020060R | SmartSolar MPPT 100/20 Retail
SCC110020070R | BlueSolar MPPT 100/20 Retail
SCC110020170R | BlueSolar MPPT 100/20_48V Retail

Dimensions in mm

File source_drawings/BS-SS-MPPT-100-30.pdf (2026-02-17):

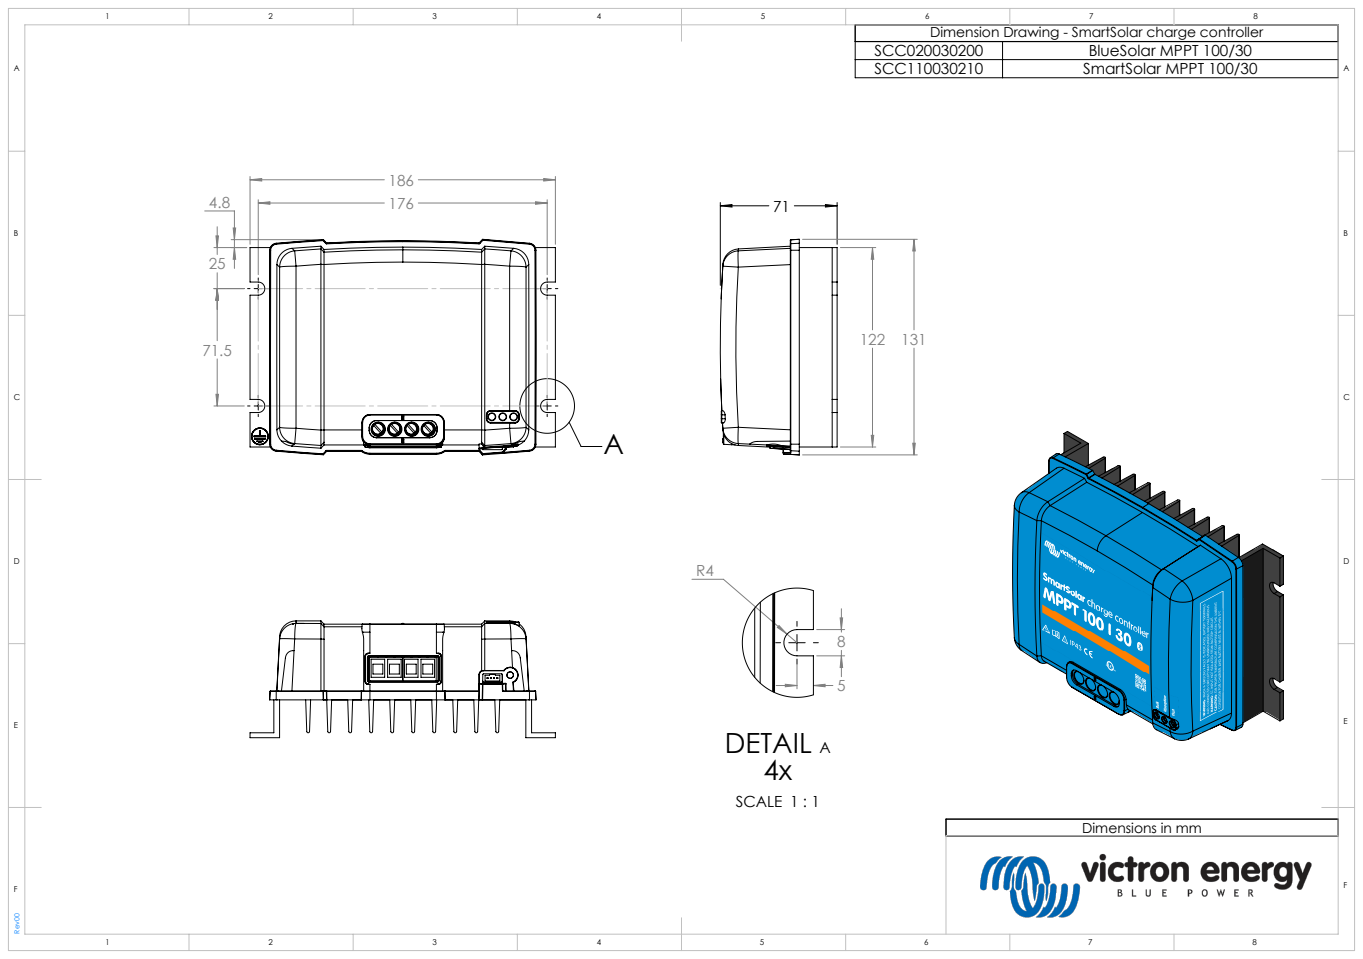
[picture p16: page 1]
DETAIL A; SCALE 1 : 1

Dimension Drawing - SmartSolar charge controller
SCC020030200 | BlueSolar MPPT 100/30
SCC110030210 | SmartSolar MPPT 100/30

Dimensions in mm

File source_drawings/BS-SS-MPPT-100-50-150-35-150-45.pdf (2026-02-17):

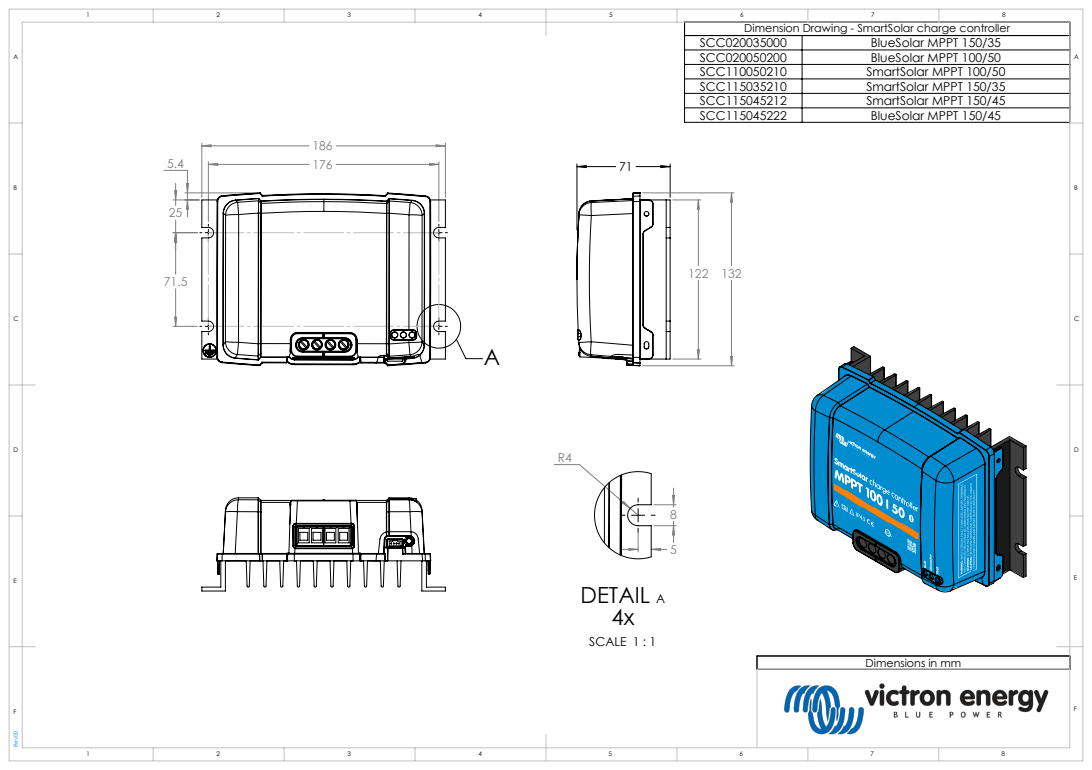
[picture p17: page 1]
DETAIL A; SCALE 1 : 1

Dimension Drawing - SmartSolar charge controller
SCC020035000 | BlueSolar MPPT 150/35
SCC020050200 | BlueSolar MPPT 100/50
SCC110050210 | SmartSolar MPPT 100/50
SCC115035210 | SmartSolar MPPT 150/35
SCC115045212 | SmartSolar MPPT 150/45
SCC115045222 | BlueSolar MPPT 150/45

Dimensions in mm

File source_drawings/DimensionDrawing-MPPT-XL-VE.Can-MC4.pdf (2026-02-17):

A

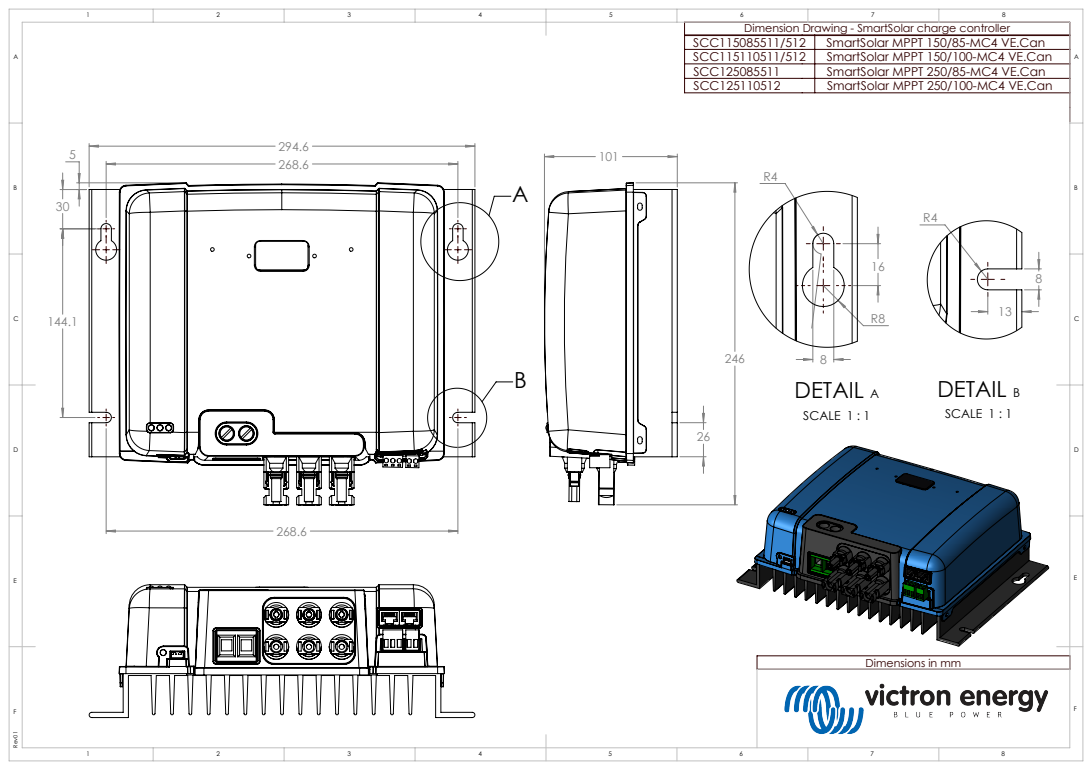
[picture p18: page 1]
DETAIL A; SCALE 1 : 1; DETAIL B; Rev01

Dimension Drawing - SmartSolar charge controller

SCC115085511/512 | SmartSolar MPPT 150/85-MC4 VE.Can
SCC115110511/512 | SmartSolar MPPT 150/100-MC4 VE.Can
SCC125085511 | SmartSolar MPPT 250/85-MC4 VE.Can
SCC125110512 | SmartSolar MPPT 250/100-MC4 VE.Can

Dimensions in mm

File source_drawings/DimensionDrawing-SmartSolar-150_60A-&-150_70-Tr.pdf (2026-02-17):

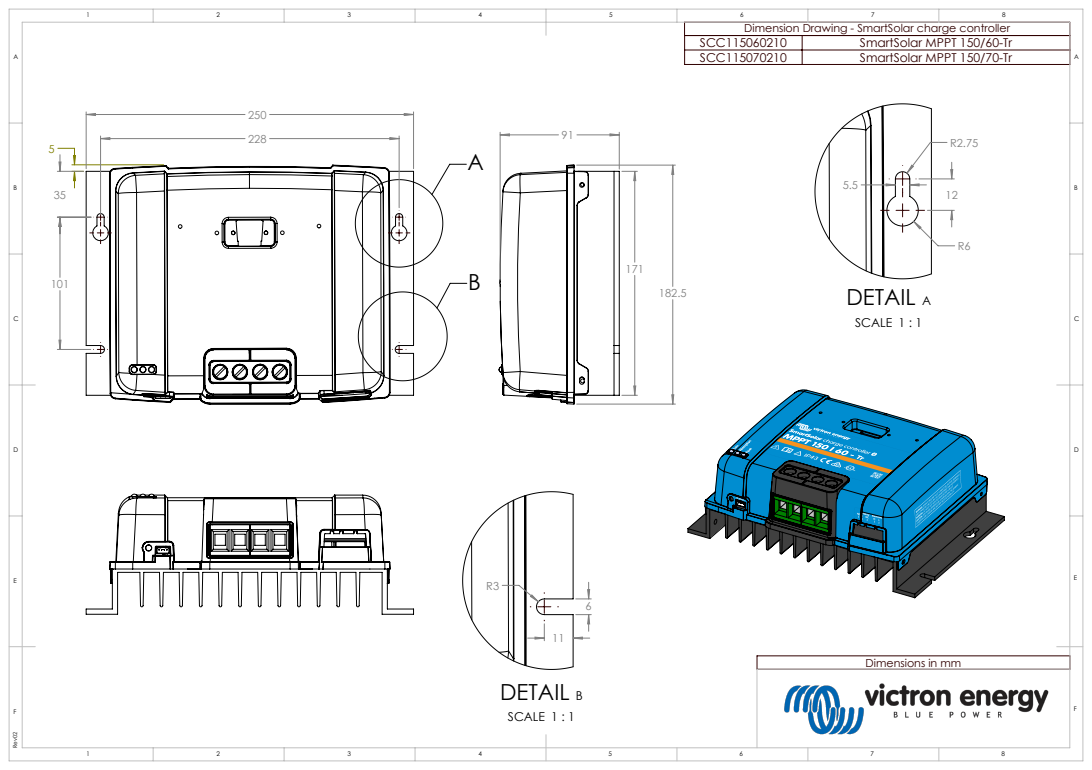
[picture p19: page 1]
DETAIL B; SCALE 1 : 1; DETAIL A

Dimension Drawing - SmartSolar charge controller
SCC115060210 | SmartSolar MPPT 150/60-Tr
SCC115070210 | SmartSolar MPPT 150/70-Tr

Dimensions in mm

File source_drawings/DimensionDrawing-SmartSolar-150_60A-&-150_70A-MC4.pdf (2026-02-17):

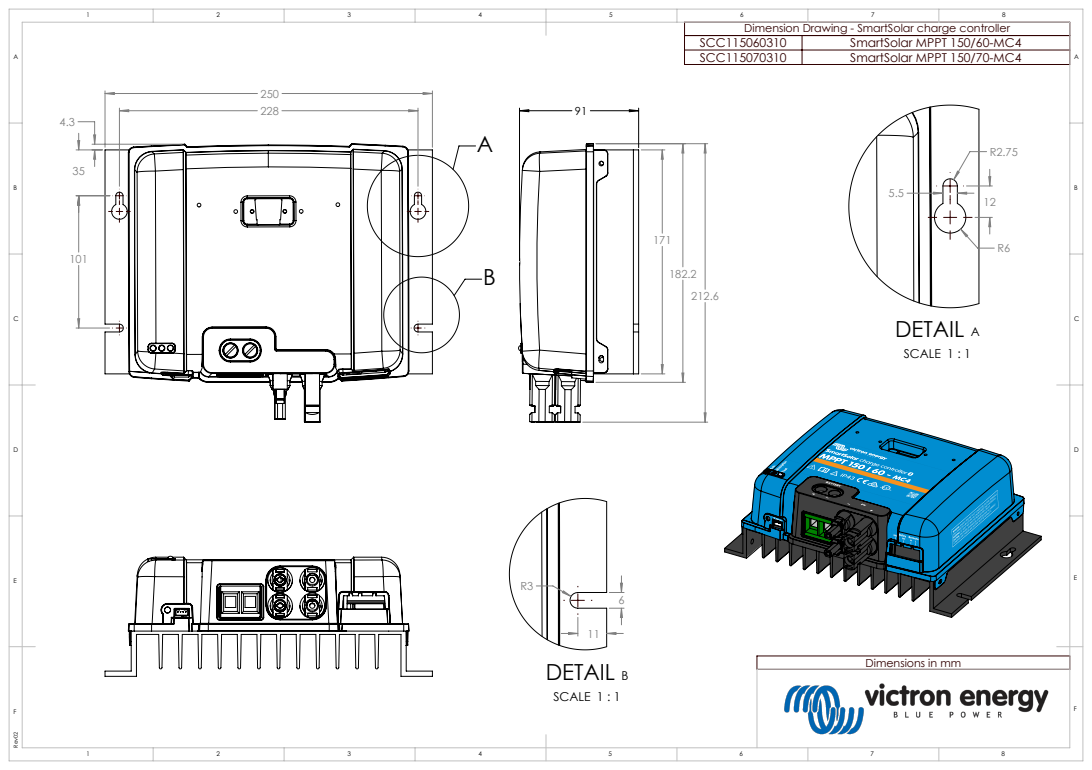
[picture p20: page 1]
DETAIL B; SCALE 1 : 1; DETAIL A

Dimension Drawing - SmartSolar charge controller
SCC115060310 | SmartSolar MPPT 150/60-MC4
SCC115070310 | SmartSolar MPPT 150/70-MC4

Dimensions in mm

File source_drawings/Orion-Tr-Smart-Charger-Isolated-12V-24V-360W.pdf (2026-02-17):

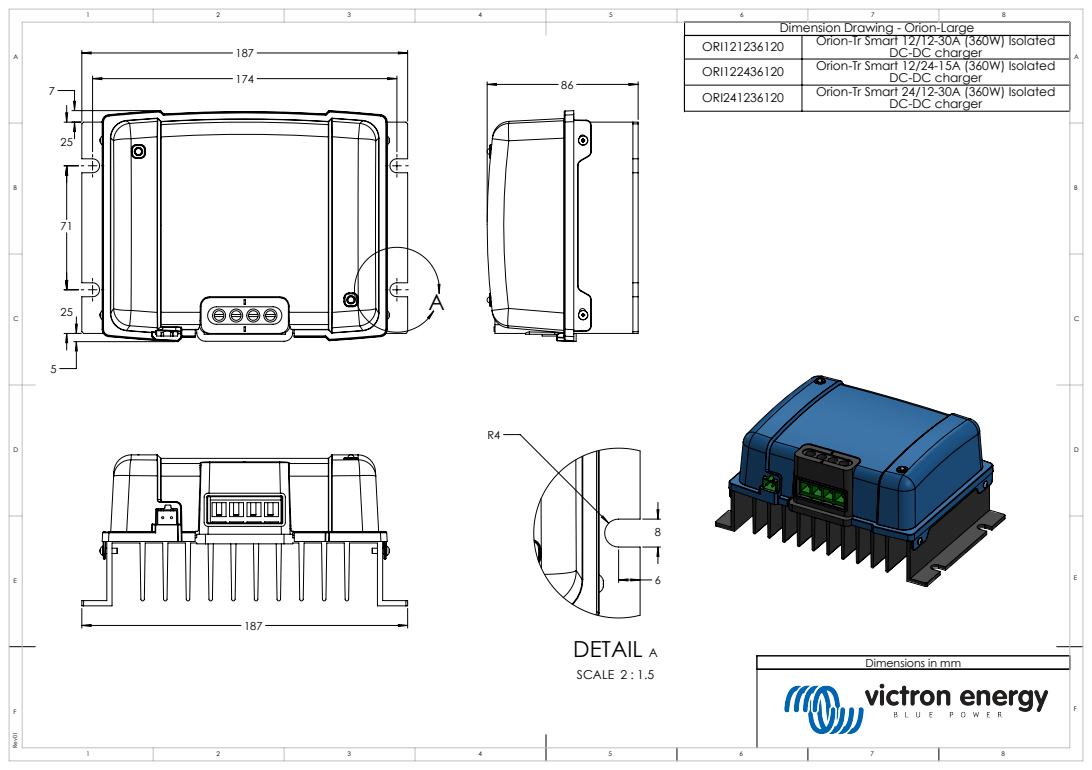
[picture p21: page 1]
DETAIL A; SCALE 2 : 1.5; Rev01

Dimension Drawing - Orion-Large

ORI121236120 | Orion-Tr Smart 12/12-30A (360W) Isolated DC-DC charger
ORI122436120 | Orion-Tr Smart 12/24-15A (360W) Isolated DC-DC charger
ORI241236120 | Orion-Tr Smart 24/12-30A (360W) Isolated DC-DC charger

Dimensions in mm

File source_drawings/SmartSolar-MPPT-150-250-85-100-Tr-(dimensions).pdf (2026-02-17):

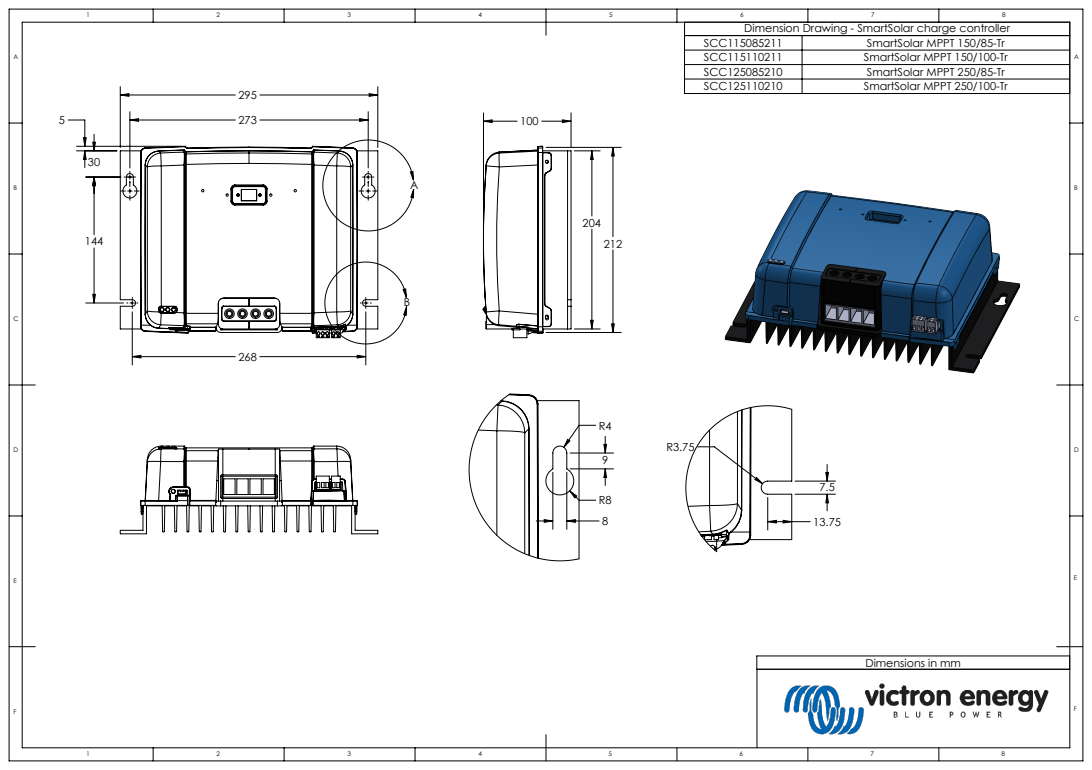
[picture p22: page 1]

Dimension Drawing - SmartSolar charge controller
SCC115085211 | SmartSolar MPPT 150/85-Tr
SCC115110211 | SmartSolar MPPT 150/100-Tr
SCC125085210 | SmartSolar MPPT 250/85-Tr
SCC125110210 | SmartSolar MPPT 250/100-Tr

Dimensions in mm

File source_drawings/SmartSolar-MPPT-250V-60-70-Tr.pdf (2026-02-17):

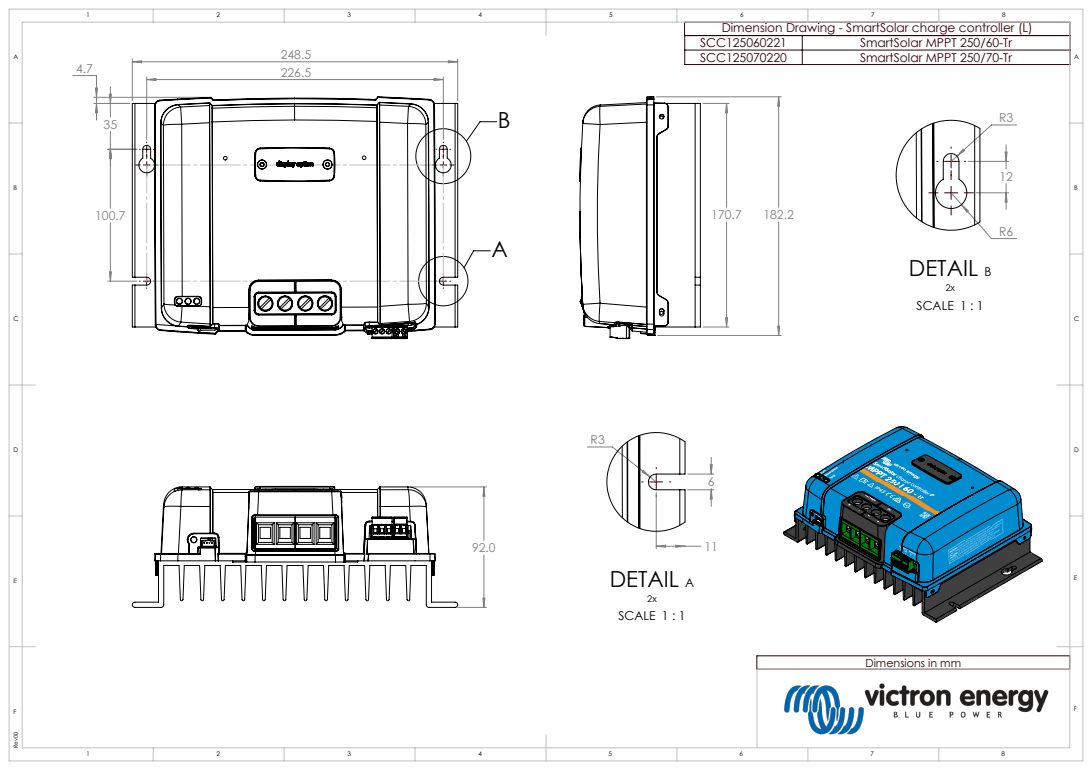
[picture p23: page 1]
DETAIL A; SCALE 1 : 1; DETAIL B

248.5 | | Dimension Drawing - SmartSolar charge controller (L)

SCC125060221 | SmartSolar MPPT 250/60-Tr
SCC125070220 | SmartSolar MPPT 250/70-Tr

Dimensions in mm

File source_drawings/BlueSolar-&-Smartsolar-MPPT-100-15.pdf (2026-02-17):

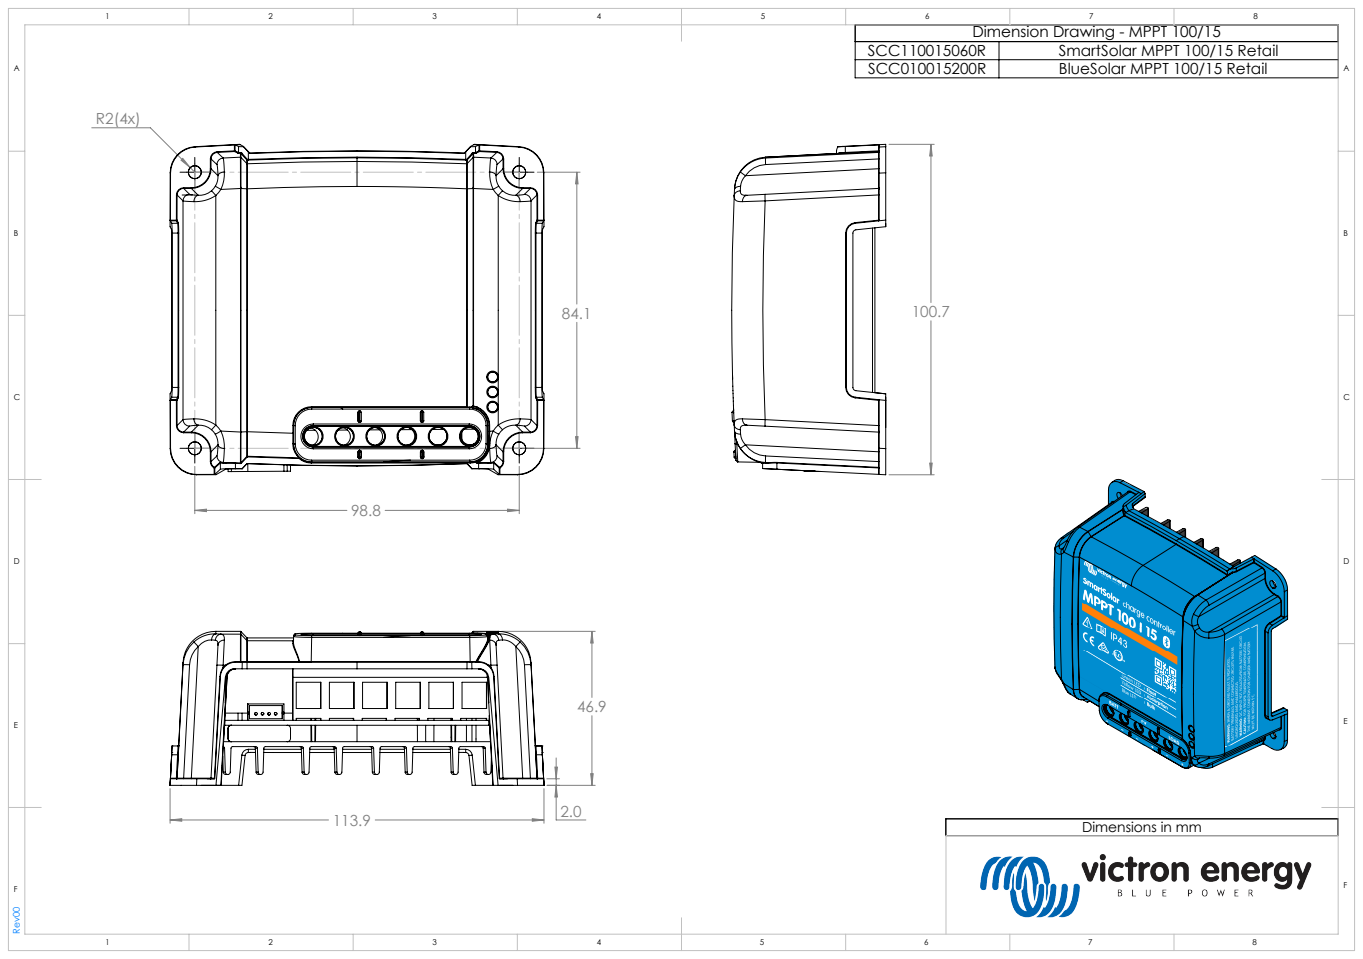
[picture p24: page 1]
Rev00

Dimension Drawing - MPPT 100/15

SCC110015060R | SmartSolar MPPT 100/15 Retail
SCC010015200R | BlueSolar MPPT 100/15 Retail

Dimensions in mm

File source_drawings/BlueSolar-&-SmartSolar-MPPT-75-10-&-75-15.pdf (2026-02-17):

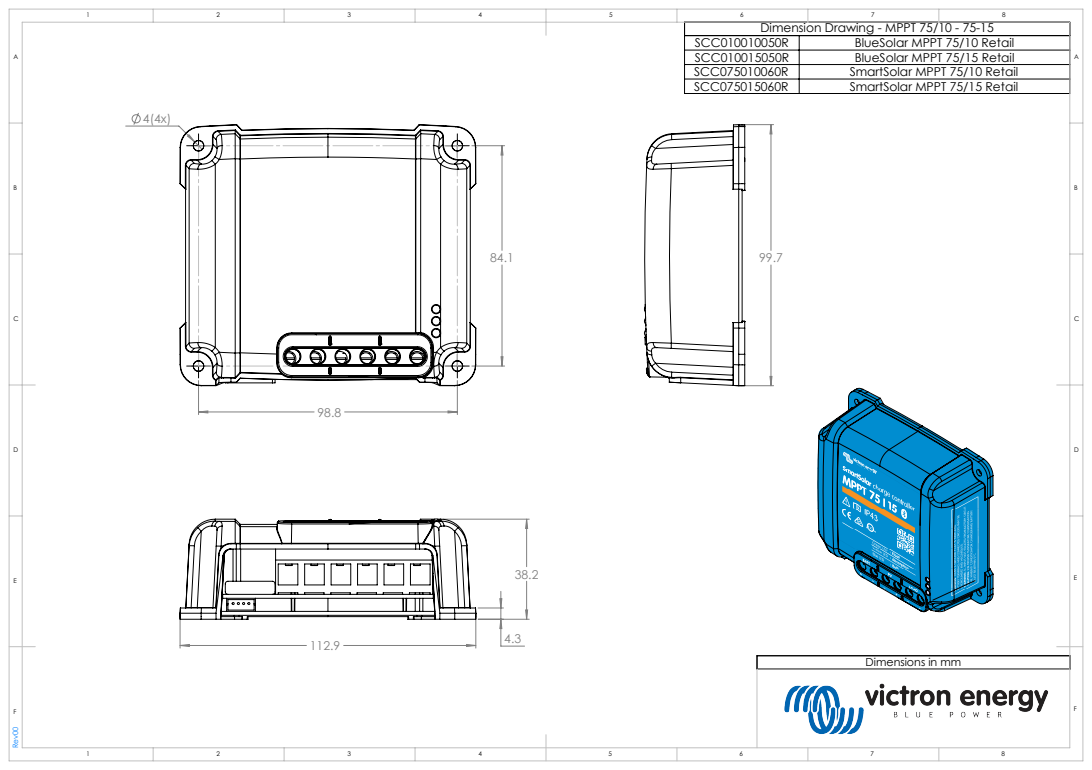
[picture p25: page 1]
Rev00

Dimension Drawing - MPPT 75/10 - 75-15

SCC010010050R | BlueSolar MPPT 75/10 Retail
SCC010015050R | BlueSolar MPPT 75/15 Retail
SCC075010060R | SmartSolar MPPT 75/10 Retail
SCC075015060R | SmartSolar MPPT 75/15 Retail

Dimensions in mm

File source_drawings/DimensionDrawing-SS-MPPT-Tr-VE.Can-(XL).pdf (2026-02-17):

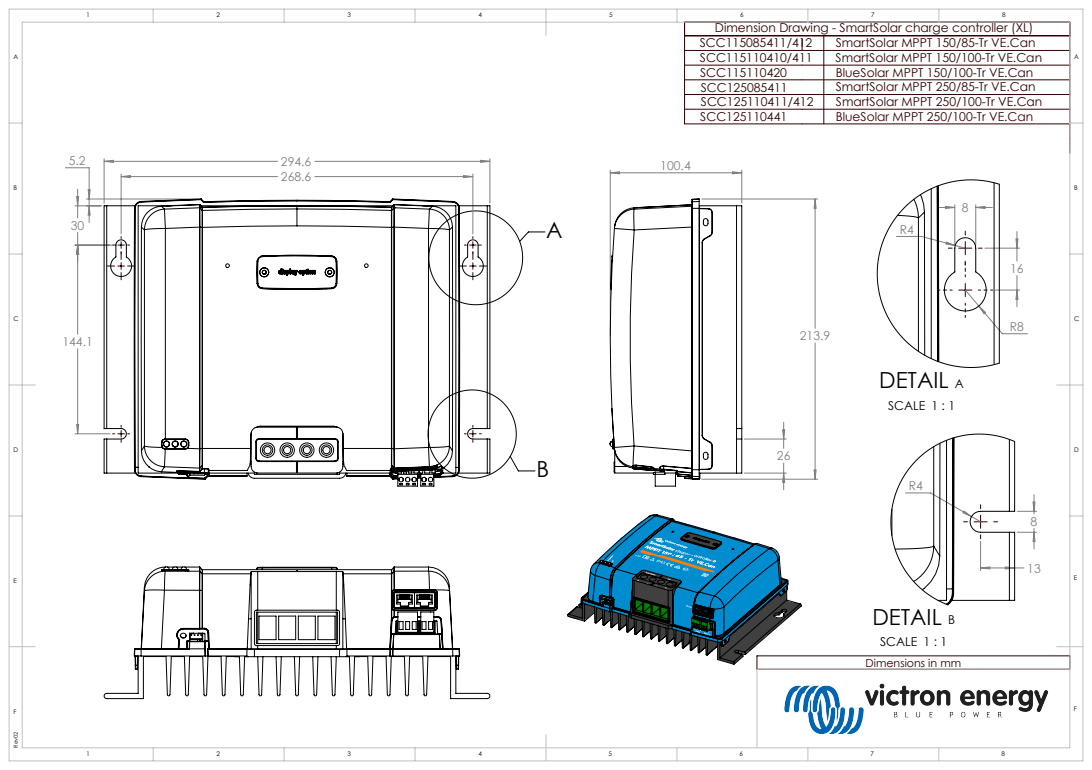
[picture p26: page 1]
DETAIL A; SCALE 1 : 1; DETAIL B; Rev02

Dimension Drawing - SmartSolar charge controller (XL)
SCC115085411/412 | | SmartSolar MPPT 150/85-Tr VE.Can
SCC115110410/411 | | SmartSolar MPPT 150/100-Tr VE.Can
SCC115110420 | | BlueSolar MPPT 150/100-Tr VE.Can
SCC125085411 | | SmartSolar MPPT 250/85-Tr VE.Can
SCC125110411/412 | | SmartSolar MPPT 250/100-Tr VE.Can
SCC125110441 | | BlueSolar MPPT 250/100-Tr VE.Can

SCALE 1 : 1
Dimensions in mm

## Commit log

2026-02-17 Initial commit: Parametric cooling mount system v2.5.0 for 44 Victron MPPT models
    Complete 4-piece 3D printable cooling mount system for Victron BlueSolar/SmartSolar
    MPPT charge controllers and Orion-Tr DC-DC chargers. All 44 models verified from
    manufacturer documentation across 10 configurations (A1, A3, A4, A4_MC4, B1, B2,
    B2_MC4, B3, C1, C2).
    Fan size override feature (fan_size_override parameter):
    - fan_count auto-recalculates using available fan_area_width when size is overridden
    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
    [BlueSolar-SmartSolar-MPPT-100V20A--(3D).STEP, Fan Temperature Control Board Enclosure Case Front.stl, controller_box.scad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]
2026-02-17 v2.6.0: Align rear grill hex pattern with overridden fan size
    When fan_size_override is active, the rear grill ventilation hexagon
    pattern now tracks the actual (cutout) fan height rather than filling
    the full structural plate height.
    Changes:
    - rear_grill(): Added cutout_size = get_effective_fan_size(ctrl)
    - Hex pattern vertical bounds now calculated as:
    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
    [solar_controller_cooling_mount_20260217_123309.scad]
2026-02-17 Add generate_orca_3mf.py - per-model OrcaSlicer 3MF generator v1.0.0
    Generates 76 OrcaSlicer-compatible 3MF files (41 default + 35 x 40mm
    override) for all Victron MPPT controller cooling mount configurations.
    Key features:
    - One 3MF per controller model x fan size (not deduplicated by config group)
    - File naming: {Model_Name}_{fan_size}mm.3mf
    - 3 plates per 3MF: Fan Mount (alone) | Rear Grill (alone) | Rails (L+R pair)
    - Embedded settings: PETG material, 20% sparse infill
    - Pure stdlib STL parser (binary + ASCII), no pip installs required
    - OrcaSlicer multi-plate via Metadata/model_settings.config
    - C1/C2 models (already 40mm default) skip duplicate 40mm override
    Includes docs/generate_or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
2026-02-17 generate_orca_3mf.py v2.0.0: Fix 3MF format to match ElegooSlicer/OrcaSlicer
    v1.0.0 produced files that opened with "no geometry" because:
    - Used <v>/<t> tags; spec requires <vertex>/<triangle>
    - Embedded mesh inline in 3dmodel.model; ElegooSlicer requires each
    STL as a separate 3D/Objects/*.model file referenced via <component>
    - Plate format used <model id=...>; correct format is <model_instance>
    with object_id/instance_id/identify_id metadata keys
    - Missing BambuStudio + production (p:) XML namespaces and UUIDs
    - Missing 3D/_rels/3dmodel.model.rels referencing object files
    v2.0.0 changes:
    - Each STL → separate 3D/Objects/{name}.model with proper mesh XML
    - 3D/3dmo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
2026-02-17 generate_orca_3mf.py v2.1.0: Add OpenSCAD PNG plate thumbnails
    Each 3MF now includes real rendered thumbnails instead of blank PNGs:
    plate_1.png → front fan mount (component 1)
    plate_2.png → left rail (stand-in for rails plate)
    plate_3.png → rear grill (component 4)
    Rendered at 300x300 via OpenSCAD --export-format png with
    --autocenter --viewall for automatic framing. _small variants
    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
2026-02-19 Fix 40mm fan holes (32mm pattern, no nut well) and fix 3MF Z positioning
    solar_controller_cooling_mount.scad v2.6.1:
    - Correct 40mm fan screw hole pattern from 30mm to 32mm (industry standard)
    - Remove nut well recess from 40mm fan holes (M3, no well needed)
    - 50mm fans unchanged (M4, 40mm pattern, 5.6mm nut well retained)
    generate_orca_3mf.py v2.3.0:
    - Fix "half on/half off plate" bug: set build transform tz = part_height/2
    ElegooSlicer re-centers meshes at Z=0 before applying transforms, so
    tz must equal height/2 to place part bottom flush with the build plate
    - Apply same tz fix to assemble_item transforms and source_offset_z
    - Add thumbnail relationship entries to _rels/.rels (match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
    [solar_controller_cooling_mount.scad]
2026-02-19 solar_controller_cooling_mount.scad v2.6.2: Fix B1/B2 keyhole and A4 hole positions
    - Fix B1/B2/B2_MC4 keyhole center-to-center: 17mm → 9mm (confirmed from Victron PDF)
    Affects SmartSolar/BlueSolar 150/85, 150/100, 250/85, 250/100 Tr and VE.Can models
    - Fix A4/A4_MC4 hole positions: 11mm → 35mm from each end (confirmed from Victron PDF)
    Affects SmartSolar 150/60-Tr, 150/70-Tr, 150/60-MC4, 150/70-MC4
    Holes now at 35mm and (controller_length - 35mm), matching 101mm hole-to-hole spacing
    - Separate B3 from A4 in hole position ternary (B3 value still pending PDF verification)
    - Regenerate all 76 3MF files with corrected geometry
    Rail length confirmed correct: rail_length = controller_l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
    [BlueSolar_MPPT_100-20_40mm.3mf, BlueSolar_MPPT_100-20_48V_40mm.3mf, BlueSolar_MPPT_100-20_48V_50mm.3mf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]
2026-02-19 solar_controller_cooling_mount.scad v2.6.3: Fix B2/B2_MC4 flange holes from STEP analysis
    - Fix B2/B2_MC4 keyhole center-to-center: 9mm → 16mm (confirmed from both STEP files)
    - Fix B2/B2_MC4 hole positions: 13.75mm → 30mm from each end (STEP: Z=30 and Z=174.1)
    - Fix B2/B2_MC4 u_hole_diameter: 7.5mm → 8mm (R4 confirmed from STEP)
    - Fix B2_MC4 database length: 246mm → 204mm (heatsink is 204mm; 246mm was overall
    housing including MC4 connectors, not the relevant rail span)
    - B2 Tr VE.Can length already corrected to 204mm in previous commit (physical measurement)
    - Separate B1 and B2/B2_MC4 in all dimension lookups (previously incorrectly grouped)
    - B1 values unchanged: 13.75mm positi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
    [BlueSolar_MPPT_100-20_40mm.3mf, BlueSolar_MPPT_100-20_48V_40mm.3mf, BlueSolar_MPPT_100-20_48V_50mm.3mf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]
2026-02-19 solar_controller_cooling_mount.scad v2.6.4: Fix keyhole geometry + B3 hole positions
    Keyhole redesign (all configs):
    - Previous code used Z-direction counterbore (concentric circles at same XY, different depth)
    - This looked like a stepped round hole, NOT a keyhole shape
    - New code uses Y-direction keyhole (two circles at different Y positions + connecting slot)
    - Small circle at end position (screw shank locks here)
    - Large circle offset toward rail center (screw head entry point)
    - Rectangular slot connecting them - visible as true keyhole from top face
    - Applies to A4/A4_MC4 (R2.75/R6, 12mm), B1 (R4/R8, 9mm),
    B2/B2_MC4 (R4/R8, 16mm), B3 (R3/R6, 12mm)
    B3 hole positions (conf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
    [BlueSolar_MPPT_100-20_40mm.3mf, BlueSolar_MPPT_100-20_48V_40mm.3mf, BlueSolar_MPPT_100-20_48V_50mm.3mf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]
2026-02-20 generate_orca_3mf.py v2.6.5: Fix A4_MC4 length, update comments from STEP audit
    STEP audit findings:
    - A4_MC4 (150/60-MC4, 150/70-MC4): DB had 212.6mm (overall housing including MC4
    connector protrusions). STEP analysis confirms heatsink rail is 171mm — same
    body as A4 Tr, holes at Z=35 and Z=136. Fixed: 212.6mm → 171mm.
    - A1: Corrected stale comment "142mm" to actual "122mm" (confirmed from STEP:
    holes at Z=25.0 and Z=96.5, 71.5mm c-t-c).
    - B3 keyhole comment updated from "unverified" to "confirmed from STEP file".
    - All 76 3MF files regenerated.
    STEP audit also identified 6 potential missing models in Victron line:
    - 150/70-Tr VE.Can, 250/70-Tr VE.Can (same body as A4, L-Tr ST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
    [solar_controller_cooling_mount.scad]
2026-02-20 solar_controller_cooling_mount.scad v2.6.6: Add 250/60-70 MC4 models, fix 150/60-70 MC4 config
    All 150/60 through 250/70 MC4 non-VE.Can variants confirmed on same dimension
    drawing (SS-MPPT-250-60-70-MC4-3D.STEP) and share B3 body geometry (R3/R6
    keyhole, 12mm c-t-c, 35mm from ends, 170.7mm x 248.5mm).
    - Moved SCC115060310 (150/60-MC4) and SCC115070310 (150/70-MC4) from A4_MC4
    config to B3 config — corrects keyhole from R2.75→R3, heatsink 171→170.7mm,
    width 250→248.5mm, heatsink height 32.5→34.5mm
    - Added SCC125060310, SCC125060321 (250/60-MC4) as new B3 models
    - Added SCC125070310, SCC125070321 (250/70-MC4) as new B3 models
    - A4_MC4 config now has no models (left as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
    [solar_controller_cooling_mount.scad]
2026-02-20 solar_controller_cooling_mount.scad v2.6.7: Add A4 VE.Can 70A models
    Add three missing Tr VE.Can models with A4 heatsink body (171mm, R2.75/R6,
    12mm c-t-c, 35mm from ends) confirmed from DimensionDrawing-SS-MPPT-150-250-70-Tr-VE.Can-(L)-3D.STEP:
    SCC115070411 SmartSolar MPPT 150/70-Tr VE.Can
    SCC125070421 SmartSolar MPPT 250/70-Tr VE.Can
    SCC125070441 BlueSolar MPPT 250/70-Tr VE.Can
    3MF count: 84 → 90 files
    [solar_controller_cooling_mount.scad]
2026-02-20 v2.6.8: Add total_width_override parameter for physical measurement correction
    Adds a new user-configurable parameter total_width_override (default 0) that
    allows the printed width to be set to a physically-measured value when the
    STEP file nominal dimension does not match the real product.
    Problem: Victron STEP files for A4 class (SmartSolar 150/60-Tr, 150/70-Tr, etc.)
    specify 250mm total width, but physical measurement in Fusion 360 confirms
    approximately 247mm. The 3mm discrepancy causes the heatsink to not reach the
    rail ends and the flange holes to misalign.
    - Added /* [Width Override] */ section with total_width_override = 0 parameter
    - Modified get_total_width() to return o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
    [solar_controller_cooling_mount.scad]
2026-02-20 v2.6.8: Make total_width_override free-form manual input only
    Remove OpenSCAD customizer dropdown enum from total_width_override.
    The dropdown implied pre-set standard values; the override is
    intentionally manual for per-unit physical measurements only.
    Plain comment makes the customizer show a text/number field.
    [solar_controller_cooling_mount.scad]
2026-02-21 v2.6.9 SCAD + v2.4.0 generator: Width echo, special variants, fault report
    solar_controller_cooling_mount.scad v2.6.9:
    - Echo now always shows database heatsink width as 'Width (heatsink): Xmm'
    - When total_width_override is active, annotates with '*** OVERRIDE ACTIVE
    — database value: Xmm ***' for clear visual warning
    - Removes width_notice from Dimensions line; width is its own dedicated line
    generate_orca_3mf.py v2.4.0:
    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
    [solar_controller_cooling_mount.scad]
2026-02-21 solar_controller_cooling_mount.scad v2.7.0: Nut wells for all fan sizes
    Remove the if (cutout_size == 50) guard on nut wells so that 40mm fan
    plates also get recessed nut wells (d=5.6mm, 4.5mm deep from back face).
    The 5.6mm well diameter accommodates M3 hex nuts (5.5mm AF) the same as
    M4, so no dimension change is needed — only the conditional is removed.
    CLAUDE.md previously noted "40mm fans don't have nut wells"; this changes
    that design decision at user direction.
    [solar_controller_cooling_mount.scad]
2026-02-21 solar_controller_cooling_mount.scad v2.7.1: Shorten dropdown labels
    Reduce model_code enum comment from 1783 to 1369 characters to stay
    within OpenSCAD customizer parser limits that caused models past a
    certain point to be silently dropped from the dropdown.
    Abbreviations used (no functional change — codes are unchanged):
    BlueSolar → BS SmartSolar → SS
    VE.Can → VC MPPT removed from all labels
    Orion-Tr Smart → Orion-Tr
    Duplicate MC4 names disambiguated: 250/60-MC4b, 250/70-MC4b
    [solar_controller_cooling_mount.scad]
2026-02-21 solar_controller_cooling_mount.scad v2.7.2: Add global fa/fs resolution
    Set fa=5 and fs=0.5 globally so all cylinders render with smooth
    proportional facet counts rather than OpenSCAD coarse defaults which
    gave 5.6mm nut wells only 8 sides (near-hexagonal appearance).
    Approximate facet counts at new settings:
    5.6mm nut well = ~35 sides (was 8)
    42mm fan cutout = ~65 sides (was 22)
    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
    [solar_controller_cooling_mount.scad]
2026-02-24 solar_controller_cooling_mount.scad v2.7.4: Per-config rail widths from STEP analysis
    SCAD changes:
    - Add get_rail_width() function returning per-config flange foot width measured
    from STEP files: B1/B2/B2_MC4 (150/85+) → 24mm, A4/A4_MC4 (150/60-70 Tr) → 20mm,
    all others → 18mm
    - Shadow global rail_width=18 inside left_rail and right_rail modules so each
    controller family uses the correct rail dimension
    - Change edge_offset in front_fan_mount and rear_grill from hardcoded 8 to
    get_rail_width(ctrl)/2 so plate M4 holes align with rail holes for all configs
    - flange_x_override comment updated with per-config defaults
    Generator + 3MF outputs:
    - generate_orca_3mf.py: updated from p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
    [BlueSolar_MPPT_100-20_40mm.3mf, BlueSolar_MPPT_100-20_48V_40mm.3mf, BlueSolar_MPPT_100-20_48V_50mm.3mf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]
2026-02-24 generate_orca_3mf.py v2.4.3: Fix PLATE_STRIDE so all plates are centered on bed
    Root cause: PLATE_STRIDE was BED_SIZE * 1.2 (307.2mm) but ElegooSlicer uses
    exactly BED_SIZE (256mm) as the virtual canvas stride between plates. With
    the old stride, plate 2 (rails) and plate 3 (grill) objects were positioned
    51mm off-center on their respective plates — causing large parts (295mm wide,
    247mm diagonal after 45° rotation) to appear half on / half off the plate.
    Fix: PLATE_STRIDE = BED_SIZE (256mm, matching Elegoo CC1 build volume)
    With the fix, all four parts are centered at display (128, 128) on each plate:
    - Plate 1 front: virtual (128,128) → display (128,128) [no offset]
    - Plate 2 rails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
    [BlueSolar_MPPT_100-20_40mm.3mf, BlueSolar_MPPT_100-20_48V_40mm.3mf, BlueSolar_MPPT_100-20_48V_50mm.3mf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]
2026-02-24 output_orca_3mf: Refresh all 91 3MF files (thumbnails)
    Re-run of generate_orca_3mf.py v2.4.3 to ensure all files are
    up to date with SCAD v2.7.4 + fixed PLATE_STRIDE. 91/91 succeeded.
    [BlueSolar_MPPT_100-20_40mm.3mf, BlueSolar_MPPT_100-20_48V_40mm.3mf, BlueSolar_MPPT_100-20_48V_50mm.3mf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]
2026-02-24 generate_orca_3mf.py v2.4.4: Fix source_offset_x/y causing objects off-center in ElegooSlicer
    ElegooSlicer adds source_offset to the transform translation. With
    source_offset_x=147.6 (front plate half-width), displayed center became
    tx+147.6=275.6, placing the left edge at plate center (128mm) with the
    part extending 295mm off the right edge. Rails had source_offset_y=102
    causing them to start at plate center-Y and go 76mm off the top edge.
    Fix: source_offset_x = 0, source_offset_y = 0. Meshes are already
    centered at XY origin by read_binary_stl so the effective offset is zero.
    The transform (128,128) now correctly places each part at bed center.
    Regenerated all 91 3MF files. source_offset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
    [BlueSolar_MPPT_100-20_40mm.3mf, BlueSolar_MPPT_100-20_48V_40mm.3mf, BlueSolar_MPPT_100-20_48V_50mm.3mf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]
2026-02-24 output_orca_3mf: Rebuild all 91 3MF files
    Fresh rebuild with all fixes applied:
    - SCAD v2.7.4: per-config rail widths (B1/B2=24mm, A4=20mm, others=18mm)
    - Generator v2.4.4: PLATE_STRIDE=BED_SIZE (objects centered on each plate)
    - Generator v2.4.4: source_offset_x/y=0 (correct XY placement in ElegooSlicer)
    91/91 succeeded.
    [BlueSolar_MPPT_100-20_40mm.3mf, BlueSolar_MPPT_100-20_48V_40mm.3mf, BlueSolar_MPPT_100-20_48V_50mm.3mf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]
2026-02-24 scad v2.7.5 + generator v2.4.5: Full names in Customizer dropdown
    Replace model_code string enum (abbreviated names, code prefixes) with
    model_index integer enum showing full model names in Customizer:
    - "BlueSolar 100/30" instead of "SCC020030200:BS 100/30"
    - Full BlueSolar, SmartSolar, VE.Can, Orion-Tr Smart names restored
    - Enum is 1253 chars (fits under ~1369 char Customizer parser limit)
    SCAD changes (v2.7.5):
    - model_index = 0 integer dropdown with 48 full-name entries
    - /* [Hidden] */ section: _MODEL_CODES lookup array + model_code derivation
    - Updated usage comment and example section
    Generator changes (v2.4.5):
    - CODE_TO_INDEX dict maps model_code -> index in CONTROLLERS list
    - re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
    [BlueSolar_MPPT_100-20_40mm.3mf, BlueSolar_MPPT_100-20_48V_40mm.3mf, BlueSolar_MPPT_100-20_48V_50mm.3mf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]
